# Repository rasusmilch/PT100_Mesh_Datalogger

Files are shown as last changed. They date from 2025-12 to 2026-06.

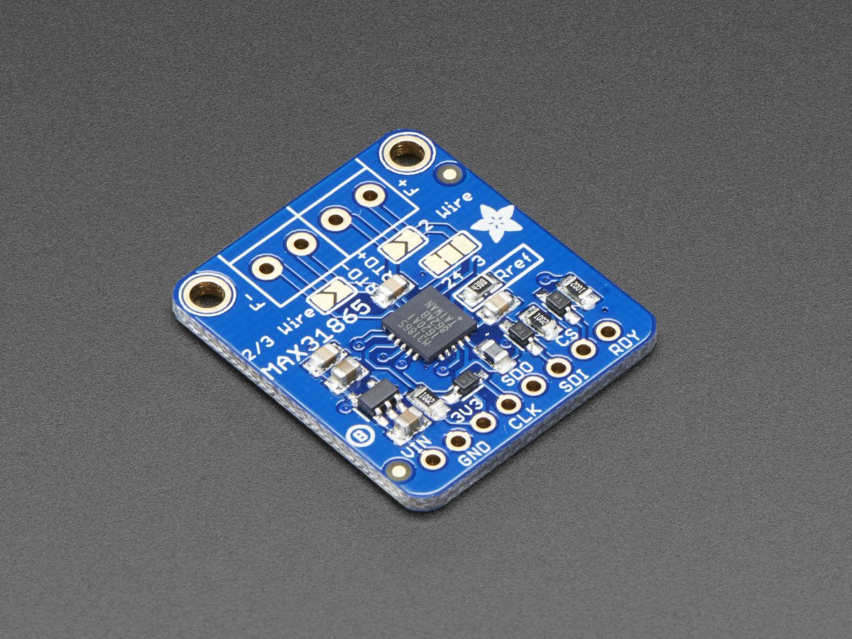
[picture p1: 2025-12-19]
documents/Adafruit_MAX31865-master/Adafruit_MAX31865-master/assets/image.jpg

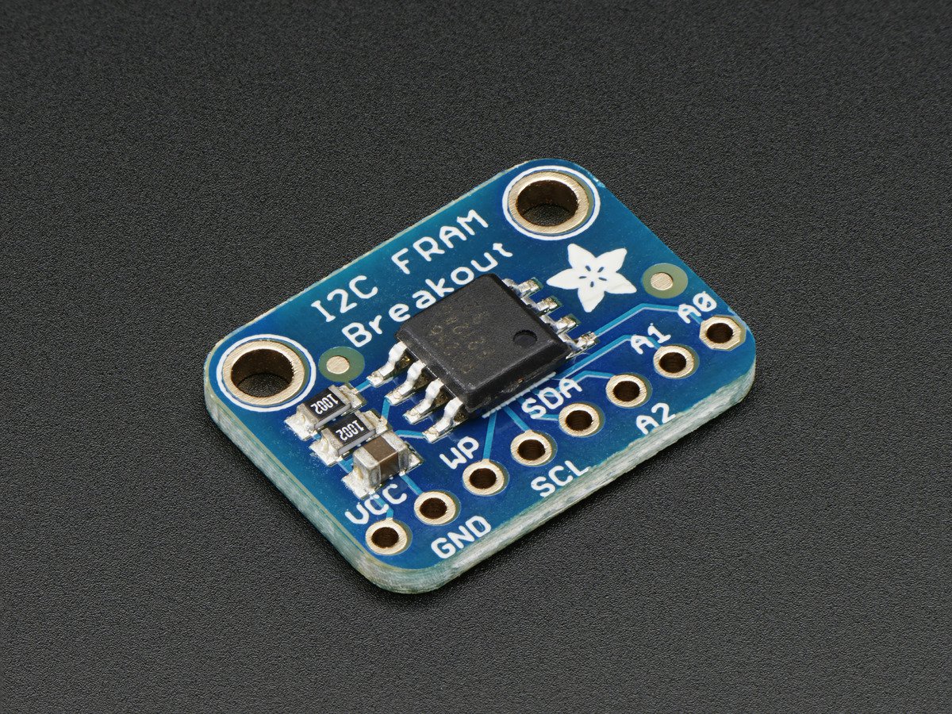
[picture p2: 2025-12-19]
documents/Adafruit_FRAM_I2C-master/Adafruit_FRAM_I2C-master/assets/image.jpg

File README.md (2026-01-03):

# PT100 + MAX31865 Temperature Data Logger (ESP32-S3, ESP-IDF)

This application turns an ESP32-S3 N8R2 into a UTC-centric PT100 data logger with FRAM-first buffering, SD-card CSV batching/verification, DS3231 RTC support, mesh streaming, and serial-console calibration.

## Hardware / wiring

All signal pins are configurable under `idf.py menuconfig -> PT100 Logger`:

- Shared SPI bus: `MOSI`, `MISO`, `SCLK`
- Chip-selects: `MAX31865 CS`, `FRAM CS`, `SD CS`
- DS3231 I2C: `SDA`, `SCL` (address selectable)

Configure mesh root/leaf role and Wi-Fi credentials in the same menu.

## Build / flash

```bash
idf.py set-target esp32s3
idf.py menuconfig   # configure pins, mesh role, batch sizes, flush thresholds
idf.py build flash monitor
```

## Logging pipeline (FRAM → SD with verification)

- Sensor task samples MAX31865 at `log interval` (NVS-backed).
- Each record is appended as a fixed-size binary struct (with CRC) to a FRAM ring buffer; the persistent header tracks read/write indices and the next sequence number.
- The SD task builds large CSV batches (~64–256 KB, configurable) from FRAM without consuming it, then:
  1. Appends the batch to the daily CSV file (`YYYY-MM-DD.csv`) with `setvbuf` buffering.
  2. `fflush()` + `fsync()`.
  3. Reads back the appended region and checks SHA-256.
  4. On mismatch: truncates to the original size and leaves FRAM untouched.
  5. On success: consumes the matching FRAM records.
- CSV header (written once per day):  
  `schema_ver,record_id,seq,epoch_utc,iso8601_local,raw_rtd_ohms,raw_temp_c,cal_temp_c,flags,node_id`
- FRAM is limited (default 32 KB); when it fills, logging pauses (no overwrite) until a flush frees space. A `fram_full` flag surfaces via `status`.

### Resume / crash safety

- On boot or day rollover the logger:
  1. Opens today’s file, truncates to the last newline if the tail was partial.
  2. Scans the tail to find the last written `seq`.
  3. Drops any FRAM records with `seq <= last_sd_seq` to guarantee no duplicates.
- If FRAM corruption is detected, consumption stops and the corrupted record can be skipped explicitly (see logs).

### Timekeeping

- DS3231 is treated as UTC and seeds system time at boot.
- Mesh root uses SNTP, updates DS3231, and broadcasts time over the mesh; leaves can request/broadcast time updates.

## Serial console commands

- `status`
- `raw` (one sample: raw/calibrated temp + resistance)
- `log interval <ms>`
- `log watermark <records>` (FRAM flush high-water mark)
- `log flush_period <ms>` (periodic SD flush interval)
- `log batch <bytes>` (target SD batch size)
- `log show`
- `cal clear`
- `cal add <raw_c> <actual_c>`
- `cal list`
- `cal apply` (1 point = offset-only; 2–4 points fit deg1–deg3)
- `flush` (best-effort FRAM→SD flush with verification)
- `diag check` (diagnostics mode only; sensor/FRAM/SD/mesh/time quick health check)

All configuration changes persist to NVS.

## Mesh / host streaming

### Mesh mode (leaf → root → broker/serial)

- Leaf nodes publish samples into the mesh; logging to FRAM continues if the
  mesh or upstream network is down.
- The root bridges mesh records to the MQTT broker and/or the DATA UART (CSV),
  and these exports are best-effort only.

### Direct Wi-Fi leaf mode (leaf → broker)

- Leaves can bypass the mesh and publish directly to the broker when configured
  for direct Wi-Fi.

FRAM/SD logging plus the DATA UART output never depend on network availability.

- Leaf nodes send samples upstream; logging to FRAM continues if mesh is down.
- Root node prints one CSV row per record over UART (after the CSV header).

Root upstream router credentials can be provided via the `wifi_ssid` /
`wifi_pass` NVS settings (from your console tooling or provisioning flow). If
those are not set, the root falls back to
`CONFIG_APP_WIFI_ROUTER_SSID` / `CONFIG_APP_WIFI_ROUTER_PASSWORD` in Kconfig.

## Test plan

1. **Calibration persistence**: Add points, apply, reboot, and confirm `status` shows the same coefficients and calibrated readings remain adjusted.
2. **Batching size**: Monitor SD writes (logic analyzer or debug prints) to confirm large buffered writes (64–256 KB) rather than per-sample writes.
3. **Crash during flush**: Pull power mid-flush; on reboot confirm the CSV tail is repaired and no duplicated `seq` appears on SD after FRAM drains.
4. **Tail repair**: Manually append a partial line to a CSV, reboot, and confirm it is truncated to the last newline automatically.
5. **Mesh resilience**: Run leaves with the root powered off; verify local FRAM accumulation and later FRAM→SD flush when root/SD returns.
6. **SD removal**: Unmount/remove SD, ensure FRAM continues to grow; remount and verify backlogged records flush with verified appends.

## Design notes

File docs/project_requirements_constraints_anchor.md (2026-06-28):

# Project Requirements and Constraints Anchor

Suggested path: `docs/project_requirements_constraints_anchor.md`

## Product requirements

The PT100 mesh datalogger shall prioritize unattended data preservation, clear diagnostics, and safe recovery over convenience or broad automatic cleanup.

Core product requirements:

1. The firmware shall collect PT100 temperature samples and preserve them through SD-card interruptions where possible.
2. The root logging node shall write durable PTLOG files to SD storage.
3. The system shall use FRAM as a buffer when SD logging is unavailable, delayed, degraded, or recovering.
4. New PTLOG files shall use the nested monthly FAT 8.3 layout:

   * `/sdcard/logs/YYYY-MM/YYYYMMDD.RRR`

   `RRR` is a decimal same-day revision from `000` through `999`; the extension is revision metadata, not file-type metadata.
5. The firmware shall ignore old root-level and long-name `.ptlog` files for PTLOG scanning, stats, and reclaim.
6. SD reclaim shall delete only old eligible compact nested PTLOG files from approved locations.
7. SD reclaim shall preserve current-date PTLOG files unless a later explicit emergency policy approves otherwise.
8. SD diagnostics shall preserve enough detail to distinguish mount, card, byte-space, create/open, directory-entry, and I/O failure classes where practical.
9. FRAM diagnostics shall distinguish current live pressure from historical data-loss evidence.
10. Host tools shall continue to read and process compact PTLOG data required for plotting, reporting, and validation; CSV import may remain as a generic feature.
11. Host tools shall tolerate partial/corrupt PTLOG tails, process all valid compact nested revisions independently, deduplicate valid records by `record_id`, and report skipped/corrupt records with file/offset or line details when available.

## Workflow requirements

Developer workflow requirements:

1. Before any Codex planning, execution, review, validation, or next-action task, inspect the latest available source directly.
2. Prefer the latest user-provided local snapshot if available. If not available, inspect the current GitHub repository, PR, branch, or commit.
3. State exactly what source, branch, PR, commit, files, anchors, and receipts were inspected.
4. Treat Codex receipts, old plans, comments, tests, and code names as claims to verify, not authority.
5. Keep tasks narrow and staged.
6. Do not combine unrelated roadmap work into a single execute task.
7. For embedded firmware changes, require build validation with ESP-IDF before merge when available.
8. For storage/recovery behavior, distinguish host-test coverage from real hardware validation.
9. Do not claim hardware validation unless real target hardware/media was used and the scenario is described.
10. Preserve explicit exclusions in every task receipt.

Operator workflow requirements:

1. Operators shall have a clear way to inspect SD and FRAM status.
2. Destructive SD format shall remain an explicit operator action.
3. Runtime alerts shall distinguish active/current failures from stale historical conditions where practical. Repeated stale `fram_overrun - active` ntfy after SD recovery and FRAM drain is a known deferred defect, not expected product behavior.
4. Display/status codes shall not be treated as precise unless their semantics are explicit.
5. Recovery behavior should avoid requiring card format unless reclaim/retry policies cannot recover.

## Data and state requirements

PTLOG data requirements:

1. PTLOG files shall remain append-safe and recoverable after interrupted writes where practical.
2. New daily PTLOG file names shall include the UTC date as `YYYYMMDD` in `/logs/YYYY-MM/YYYYMMDD.RRR`.
3. New revision PTLOG files shall use decimal `.RRR` revision metadata from `000` through `999`; old long names with `-<revision>.ptlog` are ignored by firmware.
4. New daily PTLOG files shall be grouped under `/logs/YYYY-MM/`.
5. Root-level and old long-name PTLOG-looking files shall not be eligible for firmware scanning, stats, or reclaim.
6. Automatic retention shall use parsed PTLOG metadata, not directory enumeration order alone.
7. Automatic retention shall fail closed when names, paths, stat results, or directory traversal are ambiguous.
8. On boot, SD remount, recovery, restart, header/signature uncertainty, or prior-file uncertainty, firmware should create a new same-day revision file rather than repairing and appending to an uncertain old tail.
9. Old/corrupt/partial revision files shall be preserved for host-side recovery, and firmware must not consume/discard FRAM records until append/verify to the active revision succeeds.

FRAM state requirements:

1. FRAM total overrun count shall be treated as durable historical data-loss evidence.
2. FRAM active pressure shall represent current live pressure or active overwriting, not merely an old unacknowledged total.
3. Historical/unacknowledged FRAM overrun and current/live FRAM pressure shall be modeled separately.
4. FRAM contents shall not be cleared by SD format unless a later explicit policy approves that behavior.
5. After SD recovery, FRAM drain behavior shall preserve record ordering and record IDs.
6. Repeated `fram_overrun - active` ntfy after SD recovery and FRAM drain appears caused by historical cumulative overrun being treated as active/current pressure; later FRAM semantic work shall fix it, and unrelated SD storage tasks shall not modify ntfy/display/FRAM behavior unless explicitly scoped.

SD state requirements:

1. SD mounted/unmounted state, card-present state, create/open failure, I/O failure, byte-space pressure, directory-entry pressure, and degraded/backoff state are distinct.
2. Current daily PTLOG date shall be protected from reclaim.
3. Current open PTLOG path protection is desirable but not currently tracked; current-date protection is the current conservative guard.
4. Reclaim deletion count shall count only successful `unlink()` calls.
5. Reclaim shall recompute storage condition after each successful delete.

## Architecture and model constraints

General architecture constraints:

1. Keep storage/path behavior centralized in storage/path helper code where practical.
2. Avoid duplicating PTLOG name parsing in multiple modules.
3. Prefer bounded, fixed-buffer embedded logic, but do not treat fixed-size buffers as approval to place large storage path, file, candidate, scan-observation, or I/O buffers on a FreeRTOS task stack.
4. SD/PTLOG path, filename, month-directory, candidate-path, and related path-workflow buffers currently local to stack-heavy workflows should be moved to centrally owned static storage where practical. Prefer PSRAM-backed allocation/storage on the target when safe and available.
5. Largish reusable buffers should be centrally owned/static rather than repeatedly placed on task stacks. Do not increase FreeRTOS task stack sizes merely to compensate for storage/path stack pressure.
6. The abandoned generic storage scratch-owner direction from PR #376 is not the intended architecture and must not be merged as-is; it is preserved only on `archive/scratch-owner-pr376-0819853` for reference.
7. The next implementation must remain narrow: path/candidate buffer placement only, using a dedicated typed SD/PTLOG path workspace if useful. It must not create a generic allocator, slot pool, borrow/release API, or concurrency framework.
8. Future storage/path code must document ownership, lifetime, capacity, fail-closed behavior, diagnostics, and explicit runtime serialization or locking assumptions for shared/static workspace use.
9. Separate mechanism from policy:

   * candidate discovery is mechanism;
   * retention thresholds are policy;
   * create/open retry rules are policy;
   * current-date deletion is policy;
   * display/ntfy wording is product behavior.
10. Prefer one-candidate-per-pass reclaim over large in-memory candidate arrays.
11. Do not use unbounded recursive directory traversal on embedded firmware.
12. Do not follow arbitrary host-created directories.
13. Do not preserve obsolete root-only assumptions after the nested PTLOG layout.
14. Do not refactor broadly while fixing a specific reliability issue.
15. Do not change public/operator-visible behavior unless it is in scope.

PTLOG path constraints:

1. Approved automatic scan locations are:

   * `/sdcard`
   * `/sdcard/logs`
   * `/sdcard/logs/YYYY-MM`
2. Approved automatic delete candidates are regular files with parsed PTLOG names in approved locations.
3. Unknown subdirectories under `/logs` shall not be traversed unless they match `YYYY-MM`.
4. System directories such as `.Trash-1000`, `FOUND.000`, and `System Volume Information` shall be ignored by automatic retention.
5. Path joins shall check truncation and fail closed.
6. Scan/reclaim code shall remain bounded and non-recursive when storage path-workflow buffers are moved out of task stack.

## Security and permission constraints

1. Automatic firmware deletion shall be restricted to validated PTLOG candidates.
2. The firmware shall not automatically delete arbitrary user files, host-created system directories, or unknown directories.
3. Destructive operations such as SD format shall require explicit operator command/action.
4. Diagnostics may include path and errno information, but should avoid leaking unrelated sensitive data.
5. Network notification changes, if any, shall be scoped and reviewed separately.
6. Tasks shall not introduce new unauthenticated control paths or remote destructive operations without explicit approval.
7. Host tools shall not silently overwrite source data unless explicitly designed and documented.

## Validation and testing requirements

General validation requirements:

1. Every execute task shall list exact commands run and exact results.
2. Tests must be behavior-based where practical, not only compile/import smoke tests.
3. Host tests are acceptable for path parsing, candidate selection, and small deterministic helpers.
4. ESP-IDF build is required for embedded firmware changes before merge when `idf.py` is available.
5. If `idf.py` is unavailable, the exact error shall be reported and firmware build shall remain unverified.
6. Hardware validation is required before claiming real SD/FAT behavior is proven.
7. `git diff --check` shall be run for code changes.
8. Final receipts shall identify unverified and environment-limited items.

Storage-specific validation requirements:

1. PTLOG path construction tests shall cover base daily files and revision files.
2. PTLOG parsing tests shall reject malformed names and overflow revisions.
3. Candidate traversal tests shall cover root and nested candidates.
4. Candidate traversal tests shall verify current-date and current-path protection where applicable.
5. Reclaim tests shall verify:

   * nested candidate selection;
      * current-date protection;
   * same-date revision protection;
   * non-PTLOG preservation;
   * PTLOG-looking directory preservation;
   * system directory exclusion;
   * malformed month directory exclusion;
   * max delete limit behavior;
   * successful delete counting;
   * unlink-failure no-count behavior.
6. Hardware SD validation should include real FAT16 media, nested log directories, old ignored root files, low-space or forced reclaim conditions, and current-date file protection.

## Documentation requirements

1. Project anchors shall be concise and reusable.
2. Do not paste raw receipts into anchors.
3. Anchors shall summarize current intent, requirements, constraints, decisions, risks, and validation gaps.
4. Markdown anchor files should include a “Last updated context” section.
5. Code comments shall explain non-obvious behavior, invariants, safety constraints, or failure models.
6. Avoid placeholder comments that restate function names or parameter names without adding meaning.
7. Operator documentation shall be updated when commands, public workflows, display/status behavior, setup, or expected operator action changes.
8. PR bodies shall accurately distinguish direct production-function tests from test-local approximations.
9. If a code documentation policy anchor exists, future source changes shall read and follow it.
10. If no code documentation policy anchor exists, embedded tasks shall include focused documentation requirements.

## Deployment and environment constraints

1. Target firmware environment is ESP-IDF on ESP32-class hardware.
2. SD storage currently uses FAT-compatible ESP-IDF VFS behavior.
3. FAT16 with 16 KiB allocation units is an accepted current configuration.
4. `.allocation_unit_size = 16 * 1024` shall not be changed without explicit approval.
5. `.max_files = 5` shall not be changed without explicit approval and validation.
6. Real SD/FAT behavior may differ from Linux host filesystem behavior.
7. Host tests may use Linux temporary directories to simulate paths, but such tests do not prove FAT directory-entry behavior.
8. Some Codex/local environments may lack configured git remotes.
9. Some Codex/local environments may lack `idf.py`.
10. Codex may check out work into a local branch named `work`; this name shall not be treated as the product branch name.

## Code style and maintainability requirements

1. Prefer small, readable C helpers over large mixed-responsibility functions.
2. Use fixed-size buffers and explicit bounds checks in embedded path/storage code.
3. Preserve existing public interfaces unless a task explicitly changes them.
4. Remove dead static helpers when replacing obsolete behavior.
5. Avoid broad reformatting or unrelated cleanup.
6. Log useful failure detail without creating noisy repeated logs.
7. Keep task-specific comments focused on safety and model decisions.
8. Avoid duplicating parsing/validation rules in multiple places.
9. Prefer deterministic candidate ordering.
10. Keep host-test helpers small and purpose-specific.
11. Do not create a large fake ESP-IDF harness unless a task explicitly approves it.
12. Any execute task touching storage/path code shall report new stack buffers by file/function/size, new static buffers by owner/lifetime/size, new heap or PSRAM allocations with fallback behavior, and task-safety/locking assumptions for shared static path workspaces.
13. Future storage tasks shall not silently add or preserve large stack buffers; if a small stack path-fragment buffer is necessary, the task receipt shall justify it and distinguish it from reusable static SD/PTLOG path-workflow buffers.

## Prompting and Codex receipt formatting requirements

Codex planning tasks shall require:

1. Latest source inspection before planning.
2. No file changes.
3. Verified current behavior by file/function.
4. Comparison of current behavior to intended behavior.
5. Explicit behavior gap.
6. Architecture/model/pattern/rule checkpoint.
7. Minimal safe implementation path.
8. Split-vs-single-task recommendation.
9. Proposed tests.
10. Documentation requirements.
11. Risks, unverified items, product decisions, and exclusions.
12. Complete planning receipt inside one copy/paste-ready `~~~text` fence.

Codex execute tasks shall require:

1. Latest source inspection before editing.
2. Implementation of only approved behavior.
3. Preservation of prior validated behavior.
4. Avoidance of future roadmap work.
5. Behavior tests for intended workflow and real failure scenarios.
6. Documentation compliance.
7. Exact command results.
8. Final receipt inside one copy/paste-ready `~~~text` fence.
9. No nested fences in receipts.

Codex receipts shall include at minimum:

1. Inspected context.
2. Source state and branch/commit identity.
3. Anchor files and docs inspected.
4. Summary of changes or planning decision.
5. Files changed, if any.
6. Verified behavior.
7. Tests and commands.
8. Acceptance criteria.
9. Documentation compliance.
10. Explicitly preserved exclusions.
11. Risks and unverified items.
12. Environment-limited items.
13. Next recommended action.

## Scope-control rules

1. Do not let Codex decide product policy.
2. Mark undecided behavior as a product decision.
3. Do not broaden a task because related issues are visible.
4. Do not start the next roadmap task until the current PR has at least build validation.
5. Do not claim validation that was not performed.
6. If a task touches embedded storage, preserve safety exclusions unless explicitly changed.
7. If a task reveals a wrong model, stop and replan instead of patching around it.
8. Do not combine SD path/reclaim changes with FRAM semantic changes.
9. Do not combine display/status/ntfy wording changes with storage mechanism changes unless explicitly scoped.
10. Do not create anchors during unrelated implementation tasks unless explicitly requested.

## Known project-specific hazards

1. FAT16 root-directory entry exhaustion from many long PTLOG filenames.
2. Long FAT filenames consuming multiple directory entries.
3. Free byte space appearing sufficient while directory-entry allocation fails.
4. Linux reading a card successfully while ESP-IDF FATFS fails create/open.
5. Root-only reclaim failing after logs move to nested monthly directories.
6. Automatic deletion accidentally targeting non-PTLOG files if parsing/traversal is too broad.
7. Current-date PTLOG deletion causing active logging data loss.
8. Historical FRAM overrun being displayed or alerted as active/live pressure.
9. Misleading `SDOUT` interpretation.
10. Post-append mutation of a record flag not affecting the already-stored FRAM record.
11. Environment receipts that report local branch `work` without remote metadata.
12. PR or receipt claims overstating test coverage.

## Settled requirements

These are currently settled unless the user explicitly changes them:

1. New daily PTLOG files use nested monthly directories with `YYYYMMDD.RRR` FAT 8.3 basenames.
2. Legacy/root long-name PTLOG compatibility is intentionally removed; old files are ignored, not migrated.
3. Automatic PTLOG traversal is bounded to approved locations.
4. Automatic reclaim deletes only parsed regular PTLOG candidates.
5. Current-date PTLOG files are protected.
6. Reclaim deletes one oldest eligible candidate per pass.
7. Reclaim currently remains byte-space-triggered only until threshold policy is added.
8. FAT16 / 16 KiB allocation unit configuration remains accepted.
9. Hardware validation is required before claiming SD/FAT runtime behavior is proven.
10. FRAM historical overrun and live pressure must be separated in future FRAM work.
11. Display/ntfy status changes are separate tasks.
12. Project tasks should minimize Codex usage through focused planning and execution.

## Provisional requirements and product decisions still needed

These require user decision or explicit task approval:

1. Exact max total PTLOG file count.
2. Exact max PTLOG files per directory.
3. Exact compact nested PTLOG count threshold.
4. Exact estimated FAT directory-entry pressure threshold.
5. Whether reclaim should run before daily open based on file-count/directory-entry pressure.
6. Which daily `fopen`/create errors trigger reclaim and retry.
7. Whether create/open reclaim retry deletes one file or multiple files.
8. Whether current-date PTLOGs may ever be deleted in an emergency.
9. Whether same-day old revision PTLOGs may be deleted automatically.
10. Whether empty month directories should be removed after reclaim.
11. Whether to track current open PTLOG path in `sd_logger_t`.
12. Compact PTLOG names are mandatory for firmware PTLOG files as `YYYYMMDD.RRR`; legacy `.ptlog` compatibility is removed.
13. Replacement display/status code taxonomy for `SDOUT`.
14. FRAM acknowledgement policy for historical data loss.
15. Whether `LOG_RECORD_FLAG_FRAM_FULL` should be fixed before append or removed.
16. Whether formal decision log and validation ledger anchors should be required for future tasks.

## References and related anchors

Known current reference:

* `docs/sd_fram_failure_2026_06_23_analysis.md`

Recommended related anchors:

* `docs/project_intent_anchor.md`
* `docs/project_roadmap_anchor.md`
* `docs/code_documentation_policy_anchor.md`
* `docs/decision_log_anchor.md`
* `docs/validation_ledger_anchor.md`

At this update, the requirements/constraints anchor itself was not present in current `main`.

## Last updated context

This anchor was drafted from:

* Current conversation through merged PR #369.
* Merged PR #368: `Move PTLOG writes to FAT16-safe log directories`.
* Merged PR #369: `Refactor SD reclaim to use SdPtlogFindOldestCandidate and add reclaim unit tests`.
* Current `main/sd_logger.c` reclaim implementation after PR #369.
* Current `main/sd_ptlog_paths.c` bounded PTLOG path and candidate scanner implementation.
* `docs/sd_fram_failure_2026_06_23_analysis.md`.
* Codex Task 2A planning and execution receipts.
* ChatGPT senior review of Task 2A execution.
* User direction to conserve Codex usage through narrow, staged tasks.

Unverified at this update:

* Real hardware SD/FAT16 validation after PR #368 and PR #369.
* Long-duration field behavior after nested monthly PTLOG writes and reclaim changes.
* Host tool support for nested `/logs/YYYY-MM/` discovery across all workflows.
* Whether display/ntfy state names have been corrected.
* Whether FRAM active-vs-historical overrun semantics have been fixed.
* Whether formal roadmap, code documentation policy, decision log, or validation ledger anchors exist in the repository after this draft.

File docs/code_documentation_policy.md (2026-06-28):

# Code Documentation Policy

Suggested path: `docs/code_documentation_policy.md`

## Purpose and scope

This policy defines how source code documentation shall be written and reviewed in this repository.

It applies to:

* Embedded C firmware.
* Public and internal C headers.
* Python host tools.
* Tests and test helpers.
* Build/tooling scripts when they contain project behavior.
* Future C++ code if added.
* Codex-generated code and review tasks.

The goal is not to add large comments everywhere. The goal is to preserve product intent, safety constraints, hardware assumptions, validation boundaries, and non-obvious behavior so future maintainers and Codex sessions do not accidentally preserve stale patterns or introduce unsafe behavior.

## Audience

Code documentation should help:

* Future maintainers.
* Junior developers.
* Codex sessions.
* Human reviewers.
* Operators investigating failures.
* Hardware/debug support.
* Test authors.
* Anyone validating SD, FRAM, mesh, display, notification, calibration, or host-tool behavior.

Documentation should assume the reader can read code, but may not know the project history, hardware constraints, SD/FAT failure modes, FRAM semantics, or prior product decisions.

## Repository languages detected

The repository currently contains:

* Embedded C firmware under `main/`.
* C headers under `main/`.
* Python host tools under `host_tools/`.
* C host tests under `host_tools/tests_c/`.

C++ source was checked but not found as an active implementation language in the inspected context. C headers use `extern "C"` guards, so public headers should remain compatible with future C++ consumers.

Markdown documentation exists under `docs/`.

## General documentation standard

Document behavior when the reader needs information that is not obvious from the code.

Good documentation explains:

* Why this behavior exists.
* What invariant must remain true.
* Which product decision it encodes.
* Which safety or reliability issue it prevents.
* Which hardware or filesystem assumption it depends on.
* Which states are intentionally distinct.
* Which failures are expected and how they are handled.
* Which behavior is provisional or intentionally deferred.

Avoid comments that merely translate syntax into English.

Documentation must not claim validation that was not performed.

## Python standard

Python modules, classes, and functions shall follow PEP 257-compatible docstrings.

Use concise one-line docstrings for simple private helpers where the behavior is obvious but the helper name benefits from clarification.

Use a full docstring block when a function or class has:

* Nontrivial parsing or validation.
* File I/O.
* Report/export behavior.
* User-facing behavior.
* Error handling.
* Side effects.
* Data conversion.
* Time zone logic.
* Calibration or units.
* Compatibility with firmware schemas.
* Regression coverage for a previous bug.

Prefer Google-style sections when they add clarity:

* `Args:`
* `Returns:`
* `Raises:`
* `Side Effects:`
* `Notes:`

Python docstring example:

```python
def parse_ptlog_timestamp(value: str, default_tz: ZoneInfo) -> datetime.datetime:
    """Parse a PTLOG timestamp and attach the expected source timezone.

    Args:
        value: Timestamp text from a PTLOG or CSV export.
        default_tz: Timezone to apply when the source timestamp is naive.

    Returns:
        A timezone-aware datetime suitable for sorting and report ranges.

    Raises:
        ValueError: If the timestamp cannot be parsed.

    Notes:
        PTLOG source timestamps may be naive in older exports. Do not silently
        treat them as local workstation time; that changes report ordering and
        trim behavior.
    """
```

Short private-helper example:

```python
def _is_blank_row(row: dict[str, str]) -> bool:
    """Return true when every parsed CSV field is empty."""
```

Do not add large docstrings to trivial wrappers where the name and type hints already explain the behavior.

## C standard

Use Doxygen-compatible comments for:

* Public header functions.
* Public structs, enums, and typedefs.
* Callback types.
* Macros that behave like APIs or encode product limits.
* Nontrivial static functions when they encode safety, policy, hardware, timing, or failure behavior.
* Test helpers that model production behavior.

Preferred tags:

* `@brief`
* `@param`
* `@return`
* `@retval`
* `@note`
* `@warning`
* `@pre`
* `@post`

Document the following when relevant:

* Ownership and lifetime.
* Buffer sizes.
* Units.
* Error codes and return meanings.
* Blocking behavior.
* ISR safety.
* Thread/task safety.
* Locking assumptions.
* Allocation behavior.
* Stack usage when a helper uses more than small scalar or path-fragment locals.
* Buffer ownership, lifetime, and required capacity for static SD/PTLOG path-workspace buffers.
* Whether an SD/PTLOG path-workspace buffer is stack, static, heap, PSRAM, or caller-owned.
* Task/lock assumptions for shared static SD/PTLOG path-workspace buffers, including whether the function may run while holding the SD I/O lock.
* Truncation and fail-closed behavior for path construction.
* Allocation failure behavior and fallback allocation caps.
* Whether a function may log.
* Whether a function may mutate persistent state.
* Whether a function may delete files or otherwise perform destructive operations.

Storage-specific documentation requirements:

* Do not add comments that normalize large task-stack buffers in storage code.
* Public structs, public helpers, and nontrivial static helpers that use or receive SD/PTLOG path-workspace buffers must document buffer ownership, lifetime, required capacity, placement (stack/static/heap/PSRAM/caller-owned), task/lock assumptions, SD I/O lock expectations, truncation/fail-closed behavior, and allocation failure behavior.
* If a function intentionally uses a stack buffer larger than a small scalar/path-fragment buffer, the source comment must justify why that stack use is safe and the task receipt must report the file, function, and size.
* Documentation must not claim target stack high-water, heap, PSRAM, FAT, or hardware validation unless that validation was actually performed and described.

C header example:

```c
/**
 * @brief Find the oldest PTLOG file that automatic retention may delete.
 *
 * @param mount_point Mounted SD root path, such as "/sdcard".
 * @param current_path Optional exact path of the currently open PTLOG file.
 * @param current_date Optional current UTC date string in "YYYY-MM-DDZ" form.
 * @param candidate_out Receives the selected candidate when true is returned.
 *
 * @return true when an eligible regular PTLOG file was found.
 * @return false when no eligible file was found or required arguments are invalid.
 *
 * @note Traversal is intentionally bounded to root, /logs, and /logs/YYYY-MM.
 * @warning The caller may delete the returned path. This function must fail
 * closed for malformed names, path truncation, special files, and system dirs.
 */
bool SdPtlogFindOldestCandidate(const char* mount_point,
                                const char* current_path,
                                const char* current_date,
                                sd_ptlog_candidate_t* candidate_out);
```

C struct example:

```c
/**
 * @brief Parsed PTLOG candidate returned by bounded SD retention scanning.
 *
 * All string fields are null-terminated. Paths are absolute within the mounted
 * filesystem. A candidate is safe to consider for retention only after the
 * scanner has verified it is a regular file with a parsed PTLOG basename.
 */
typedef struct
{
  char path[SD_PTLOG_MAX_PATH_LEN]; /**< Full path to the candidate file. */
  char name[SD_PTLOG_MAX_NAME_LEN]; /**< Basename as found in the directory. */
  char date[SD_PTLOG_DATE_LEN + 1u]; /**< Parsed UTC date: YYYY-MM-DDZ. */
  uint32_t revision;                /**< Parsed same-day revision, or 0. */
  bool legacy_root;                 /**< True when candidate came from root. */
  bool current_open;                /**< True only if exact current path matched. */
} sd_ptlog_candidate_t;
```

C static helper example:

```c
/**
 * @brief Join a directory and child name without allowing truncation.
 *
 * @return true when the full path fit in the destination buffer.
 * @return false when any argument is invalid or the joined path would truncate.
 *
 * @note Storage code must fail closed on truncated paths because later callers
 * may open, create, or delete the returned path.
 */
static bool JoinPath(const char* dir_path,
                     const char* child_name,
                     char* out_path,
                     size_t out_path_size);
```

## C++ standard

No active C++ implementation files were found in the inspected context. If C++ is added later, use Doxygen-compatible comments for:

* Public classes.
* Public methods and functions.
* Templates.
* Interfaces.
* Enums.
* RAII ownership types.
* Hardware abstraction wrappers.
* Error/status types.

Document:

* Class invariants.
* Ownership and lifetime.
* Move/copy behavior.
* Exception or error-return behavior.
* Thread safety.
* Side effects.
* Blocking behavior.
* Hardware/resource ownership.

C++ example:

```cpp
/**
 * @brief Owns an SD log file and closes it on destruction.
 *
 * The object is movable but not copyable because it owns a file handle.
 *
 * @note Methods are not thread-safe unless the caller holds the runtime lock.
 * @warning Destruction may flush buffered data and can block on filesystem I/O.
 */
class SdLogFile {
 public:
  SdLogFile(SdLogFile&& other) noexcept;
  SdLogFile& operator=(SdLogFile&& other) noexcept;

  SdLogFile(const SdLogFile&) = delete;
  SdLogFile& operator=(const SdLogFile&) = delete;
};
```

## Embedded C/C++ standard

Embedded documentation must capture hardware and runtime assumptions that are not obvious from generic C code.

Document these when relevant:

* Hardware revision assumptions.
* Pin maps and peripheral maps.
* SPI/I2C/UART bus ownership.
* Clock and timer assumptions.
* Interrupt behavior and ISR/main interactions.
* DMA ownership and alignment requirements.
* RTOS task names, priorities, queues, event groups, and synchronization.
* Stack, heap, static allocation, and PSRAM assumptions.
* Calibration constants, units, scaling, and fixed-point math.
* Power/reset/watchdog behavior.
* Datasheet, errata, and register-sequence assumptions.
* Required delays and timing constraints.
* Safety-critical retry limits.
* Persistent storage layout.
* Filesystem format assumptions.
* Failure states and recovery boundaries.

Embedded example:

```c
/**
 * @brief Attempt bounded SD reclaim before another append attempt.
 *
 * @pre Caller holds the SD logger lock.
 * @pre logger->mount_point is a mounted FAT filesystem path.
 *
 * @param logger Active SD logger instance.
 * @param required_free_bytes Minimum byte-space target before append.
 * @param deleted_files Optional output count of successfully unlinked PTLOGs.
 *
 * @retval ESP_OK Reclaim completed or no eligible PTLOG candidate existed.
 * @retval ESP_ERR_INVALID_ARG logger was NULL.
 * @retval ESP_FAIL Free-space query failed.
 *
 * @note Reclaim is currently byte-space-triggered only. Directory-entry and
 * file-count pressure are handled by later retention policy work.
 * @warning Automatic reclaim must only delete parsed regular PTLOG candidates
 * from approved locations and must protect the current date.
 */
static esp_err_t SdLoggerReclaimSpaceLocked(sd_logger_t* logger,
                                            uint64_t required_free_bytes,
                                            uint32_t* deleted_files);
```

## Inline comment expectations

Inline comments should explain “why,” not trivial “what.”

Use inline comments for:

* Non-obvious domain assumptions.
* Safety constraints.
* Security/permission boundaries.
* Hardware timing assumptions.
* Peripheral register sequences.
* Interrupt, task, or lock interactions.
* Ownership and lifetime rules.
* Strict rejection cases.
* Regression protections for previous quality escapes.
* Why a broader-looking case is intentionally not handled.
* Why a policy is deferred.

Good inline comment example:

```c
/* Current-date protection is intentionally broad because sd_logger_t does not
 * yet track the exact open PTLOG path.  Do not narrow this until current-path
 * lifetime is modeled and tested. */
```

Bad inline comment example:

```c
/* Increment i. */
i++;
```

## What not to comment

Do not add:

* Comments that narrate syntax.
* Speculative comments.
* Stale comments.
* Comments that contradict tests or source behavior.
* Comments that claim hardware validation without hardware results.
* Large copied receipts in source comments.
* TODOs without owner, condition, or follow-up context.
* Comments that preserve deprecated assumptions.
* Comments that repeat function or parameter names without explaining behavior.

Do not remove useful product, hardware, safety, or failure-model comments unless replacing them with more accurate documentation.

## Codex task requirements

Every Codex task that adds or modifies source code must read this policy before editing.

Codex prompts must restate documentation requirements in acceptance criteria. Do not only say “follow the policy.”

Minimum Codex source-task acceptance language:

```text
Code documentation acceptance criteria:
- Read `docs/code_documentation_policy.md` before editing source.
- Add or update Doxygen-compatible comments for new or changed public C headers,
  structs, enums, callbacks, macros that behave like APIs, and nontrivial
  functions whose behavior is not obvious.
- Add or update PEP 257-compatible Python docstrings for new or changed
  modules, classes, public functions, and nontrivial private helpers.
- Add inline comments only for non-obvious product, safety, hardware, timing,
  ownership, concurrency, validation, or failure-model assumptions.
- Do not add comments that merely narrate syntax.
- Do not remove useful safety/product/hardware comments without replacing them
  with more accurate comments.
- Report documentation changes and any intentional documentation omissions in
  the final receipt.
```

Every Codex final receipt for a source task must include:

```text
Code documentation compliance:
- Policy file inspected: yes/no and path.
- Public APIs changed: yes/no.
- New/touched functions/classes/modules documented: yes/no.
- Inline safety/product comments added or updated: yes/no.
- Documentation intentionally omitted for trivial code: yes/no and why.
- Stale/misleading comments removed or corrected: yes/no.
```

## Documentation-only source-pass safety

Documentation-only passes must prove behavior did not change.

For Python documentation-only changes:

* Parse changed Python files with `ast.parse`.
* Compare AST after removing docstrings when practical.
* Run available tests.
* Run formatting/static checks if already part of the project workflow.
* Do not change imports, executable statements, defaults, type behavior, or command-line behavior during doc-only work.

Python AST equivalence guidance:

```text
For documentation-only Python changes, compare the AST with module, class, and
function docstrings stripped. If this guard is unavailable, explain the gap and
run the strongest available tests.
```

For C/C++ documentation-only changes:

* Prefer compile or build checks.
* Use preprocessing or token comparison where practical.
* Run available host tests.
* Run `git diff --check`.
* Run ESP-IDF build when firmware files changed and `idf.py` is available.
* If target hardware behavior is relevant, state that hardware was not validated unless it was.

C/C++ guard guidance:

```text
For documentation-only C/C++ changes, run the relevant compiler/build target
when available. If a token/preprocess equivalence check is available, use it.
If not, report that equivalence was guarded by compile/build/tests only.
```

Embedded verification limits:

* A successful host test does not prove target hardware behavior.
* A successful ESP-IDF build does not prove SD/FAT, timing, ISR, FRAM, or hardware behavior.
* Any hardware claim must list the target board, media/peripheral used, scenario, and observed result.

## Documentation backlog

Use this backlog for future focused tasks.

### Phase D1 — Add or verify behavior-preservation guard tooling

Goal:

* Provide repeatable checks for documentation-only changes.

Examples:

* Python docstring-stripped AST comparison helper.
* C/C++ preprocess/token comparison guidance.
* Documentation-only PR checklist.

### Phase D2 — Document core firmware entry points

Focus:

* `app_main.c`
* runtime manager entry points
* console command registration
* storage startup/shutdown
* task lifecycle

### Phase D3 — Document public APIs and headers

Focus:

* SD logger APIs
* PTLOG path helpers
* FRAM log APIs
* runtime health/status APIs
* alert manager APIs
* display/status APIs
* MAX31865 reader/calibration APIs

### Phase D4 — Document hardware abstraction and peripheral code

Focus:

* SD card detect and SD/FAT assumptions
* FRAM SPI/I2C behavior
* MAX31865 behavior
* I2C bus ownership
* Wi-Fi/mesh stack assumptions
* display hardware
* GPIO units/buttons
* watchdog/reset/power assumptions

### Phase D5 — Document complex tests and fixtures

Focus:

* Host PTLOG parsing/path tests.
* Reclaim behavior tests.
* FRAM drain/overrun tests.
* Host plotter/report tests.
* Any fake filesystem, fake clock, fake SD, or fake FRAM helpers.

### Phase D6 — Remove or correct misleading comments

Focus:

* Placeholder comments.
* Comments that preserve root-only PTLOG assumptions.
* Comments that imply `SDOUT` means only out-of-space.
* Comments that imply historical FRAM overrun is always active/current.
* Comments that overstate test or hardware validation.

## Policy for anchor files and related docs

If this policy is committed at `docs/code_documentation_policy.md`, future anchors should refer to that path.

Do not create duplicate competing policy files such as both:

* `docs/code_documentation_policy.md`
* `docs/code_documentation_policy_anchor.md`

If a legacy anchor path already exists, update the canonical policy file and add a short pointer from the older path if needed.

## Last updated context

This policy was drafted from:

* Current repository: `rasusmilch/PT100_Mesh_Datalogger`, branch `main`.
* Current ESP-IDF embedded C source list in `main/CMakeLists.txt`.
* Current Python host tool example `host_tools/pt100_plotter.py`.
* Current C public header style in `main/sd_ptlog_paths.h`.
* Recent SD/FAT16 PTLOG storage work through PR #368 and PR #369.
* Current chat drafts for project intent, requirements/constraints, decision log, and roadmap anchors.
* User preference for focused Codex tasks, explicit exclusions, and precise receipts.

Unverified at this update:

* Full repository language inventory beyond inspected/search-visible C, headers, Markdown, CMake, and Python.
* Whether C++ source exists in an uninspected path.
* Whether generated code exists and should be exempt from this policy.
* Whether a future docs/admin PR has already committed other anchor files.
* Exact target hardware revision, full pin map, and complete peripheral map.
* Project-wide static-analysis tooling beyond commands seen in prior receipts.
* Any hardware validation results beyond the user-reported successful ESP-IDF build after PR #369.

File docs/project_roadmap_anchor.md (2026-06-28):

# Project Roadmap Anchor

Suggested path: `docs/project_roadmap_anchor.md`

## Current project / workstream objective

Stabilize PT100 mesh datalogger SD/FRAM persistence so long-duration unattended logging is reliable, diagnosable, and recoverable.

The immediate workstream is the SD/FAT16 and FRAM-overrun recovery sequence triggered by the June 2026 storage incident. The working model is:

1. SD failure was most likely FAT directory-entry pressure from many long PTLOG filenames, especially at SD root.
2. FRAM later reported misleading active overrun state because historical cumulative overrun was treated like current live pressure.
3. SD storage mechanism fixes should be completed and validated before FRAM semantic fixes.
4. Each task should remain narrow to conserve Codex usage and prevent scope drift. Product intent remains unattended data preservation: avoid losing records, avoid firmware getting wedged by SD/FAT/path issues, avoid risky broad refactors, prefer bounded deterministic embedded behavior, and defer complex recovery/repair to host tools when that preserves data and reduces firmware risk.

## Current active feature / fix

Current active feature/fix: SD PTLOG storage and reclaim hardening.

Completed in this feature line:

* PR #368: Move new daily PTLOG writes into `/logs/YYYY-MM/`, add bounded path/candidate helper foundation, and add daily PTLOG diagnostics.
* PR #369: Wire bounded PTLOG candidate traversal into SD reclaim so reclaim can delete old eligible PTLOG files from compact nested monthly directories.

Current state after PR #369:

* New PTLOG writes use nested monthly directories.
* Legacy/root long-name PTLOG compatibility is removed; old files are ignored by firmware.
* Reclaim uses `SdPtlogFindOldestCandidate()`.
* Reclaim remains byte-space-triggered only.
* Current-date PTLOG files remain protected.
* No create/open reclaim retry exists yet.
* No file-count or directory-entry threshold policy exists yet.
* Hardware SD/FAT16 validation remains unverified in the available context.

## Phase 0 — Anchor and workflow stabilization

Purpose: reduce repeated context, prevent Codex scope drift, and make future task prompts smaller.

### 0A — Project intent anchor

Status: drafted in chat; repository commit unverified.

Create `docs/project_intent_anchor.md`.

Scope:

* Project purpose.
* Primary users/operators/systems.
* Core workflows.
* Desired behavior.
* Known behavior.
* Non-goals.
* Canonical terminology.
* Deprecated/misleading terminology.
* Data/state lifecycle assumptions.
* Safety/reliability expectations.
* Architecture principles.
* Risks and open decisions.

Task type:

* Focused docs execute task.

Branch/PR:

* May share one docs/admin draft PR with 0B, 0C, 0D, and 0E if no firmware source is touched.

Validation:

* Markdown review only.
* No firmware build required.

### 0B — Requirements and constraints anchor

Status: drafted in chat; repository commit unverified.

Create `docs/project_requirements_constraints_anchor.md`.

Scope:

* Product requirements.
* Workflow requirements.
* Data/state requirements.
* Architecture/model constraints.
* Security/permission constraints.
* Validation/testing requirements.
* Documentation requirements.
* Deployment/environment constraints.
* Code style and maintainability requirements.
* Prompting and receipt-format requirements.
* Scope-control rules.
* Known hazards.
* Settled vs provisional requirements.

Task type:

* Focused docs execute task.

Branch/PR:

* Can share the docs/admin anchor PR with 0A, 0C, 0D, and 0E.

Validation:

* Markdown review only.
* No firmware build required.

### 0C — Decision log anchor

Status: drafted in chat; repository commit unverified.

Create `docs/decision_log_anchor.md`.

Scope:

* Settled decisions from PR #368 and PR #369.
* Provisional decisions still needing product approval.
* Deprecated assumptions.
* Misleading implementation artifacts.
* Patterns that should not be treated as authority.

Task type:

* Focused docs execute task.

Branch/PR:

* Can share the docs/admin anchor PR with 0A, 0B, 0D, and 0E.

Validation:

* Markdown review only.
* No firmware build required.

### 0D — Roadmap anchor

Status: this document.

Create `docs/project_roadmap_anchor.md`.

Scope:

* Current workstream objective.
* Active feature/fix.
* Immediate tasks.
* Stabilization tasks.
* Pilot/validation tasks.
* Future tasks.
* Deferred/rejected paths.
* Sequencing and branch strategy.
* Planning vs execute requirements.
* High-risk checkpoints.
* Current next required action.

Task type:

* Focused docs execute task.

Branch/PR:

* Can share the docs/admin anchor PR with 0A, 0B, 0C, and 0E.

Validation:

* Markdown review only.
* No firmware build required.

### 0E — Code documentation policy anchor

Status: not drafted yet.

Create `docs/code_documentation_policy_anchor.md`.

Scope:

* Embedded C comment expectations.
* Host Python/tooling doc expectations.
* Doxygen/API comment rules.
* What comments to avoid.
* When docs must be updated.
* How to document safety-critical storage behavior.
* How to document test helper boundaries.

Task type:

* Read-only planning first if policy is not already agreed.
* Then focused docs execute task.

Branch/PR:

* Can share the docs/admin anchor PR if kept concise.

Validation:

* Markdown review only.
* No firmware build required.

## Phase 1 — Completed SD FAT16-safe layout foundation

### 1A — Bounded PTLOG path and candidate helper foundation

Status: completed in PR #368.

Outcome:

* Added PTLOG path helpers.
* Added nested monthly path construction.
* Added PTLOG filename parsing.
* Added bounded candidate traversal foundation.

Validation:

* Host PTLOG helper tests passed.
* Firmware built locally.
* Hardware SD runtime validation not performed.

### 1B — Wire daily writer to nested monthly paths

Status: completed in PR #368.

Outcome:

* New PTLOG files are written to `/logs/YYYY-MM/YYYYMMDD.RRR`.
* Same-day revisions are written under the same month directory.
* Legacy root compatibility preserved.
* Directory creation and daily PTLOG diagnostics added.

Validation:

* Host tests passed.
* Firmware built locally.
* Hardware SD runtime validation not performed.

### 1C — Daily PTLOG diagnostics

Status: completed in PR #368.

Outcome:

* Added diagnostics around path build, directory stat/mkdir/verify, revision scan, access, `fopen`, resume, header commit, and empty-file cleanup failures.
* Surfaced last daily PTLOG diagnostic through `diag sd`.

Validation:

* Firmware built locally.
* Hardware validation not performed.

## Phase 2 — SD reclaim and retention hardening

### 2A — Traversal-backed PTLOG reclaim

Status: completed in PR #369.

Outcome:

* `SdLoggerReclaimSpaceLocked()` now uses `SdPtlogFindOldestCandidate()`.
* Reclaim can select eligible compact PTLOGs from nested `/logs/YYYY-MM/`; root files are ignored by current policy.
* Reclaim deletes one candidate per pass.
* Reclaim recomputes free bytes after successful delete.
* Reclaim counts only successful `unlink()` calls.
* Current-date protection is preserved.
* No current-open path field was added.
* No file-count/directory-entry thresholds were added.
* No create/open retry was added.

Validation:

* Host path/reclaim-style tests passed.
* `git diff --check` passed.
* ESP-IDF firmware build was reported successful by user after local checkout.
* Hardware SD/FAT16 runtime validation not performed.

Branch/PR:

* Complete and merged.

Remaining checkpoint:

* Hardware validation still required before considering SD/FAT behavior fully proven.

### 2B — File-count and directory-entry-aware retention triggers

Status: next SD execute candidate after validation.

Goal:

* Add retention triggers beyond free byte space.

Likely scope:

* Count total PTLOG files across approved locations.
* Count PTLOG files per relevant directory.
* Add conservative estimated FAT long-filename directory-entry pressure metric if approved.
* Trigger reclaim when configured thresholds are exceeded.
* Preserve PTLOG-only, regular-file-only, bounded traversal, current-date protection, and one-candidate-per-pass deletion.
* Do not add create/open retry in this task unless explicitly approved.

Needs read-only planning first:

* Yes.

Why:

* Thresholds are product policy.
* Must decide exact compact nested limits; root legacy cleanup is not part of firmware reclaim.
* Must avoid Codex inventing retention policy.

Dependencies:

* 2A complete.
* Prefer hardware/build checkpoint after 2A before execution.
* Product decision required for threshold values.

Branch/PR:

* Separate draft PR from 2A.
* Can share one branch with only tightly related threshold/count code and tests.
* Do not combine with 2C.

High-risk checkpoint:

* Yes. Requires build and hardware/SD-media validation.

### 2C — Reclaim on daily create/open failure and retry

Status: deferred but important.

Goal:

* If daily PTLOG create/open fails with an approved errno/failure class, run reclaim even if free bytes are high, then retry open once.

Likely scope:

* Capture `errno` immediately on daily `fopen` failure.
* Classify operation as daily file open/create.
* If errno suggests space/create/directory-entry pressure, reclaim one approved candidate.
* Retry `fopen` once.
* Preserve diagnostics.
* If retry fails, report specific status/diagnostic.

Needs read-only planning first:

* Yes.

Why:

* Policy decisions are needed for errno list, retry count, candidate count, and status behavior.

Dependencies:

* 2A complete.
* Prefer 2B complete, unless a create/open failure is urgent enough to do 2C first.
* Requires precise diagnostic propagation review.

Branch/PR:

* Separate PR from 2B.
* Do not combine with display/ntfy status split.

High-risk checkpoint:

* Yes. Requires build plus hardware validation with induced create/open failure if feasible.

### 2D — SD diagnostic propagation and status specificity

Status: deferred after 2B/2C planning.

Goal:

* Preserve operation/path/errno/ESP error details from SD logger into runtime status and operator-visible diagnostics.

Likely scope:

* Structured SD failure detail.
* Last operation.
* Last path.
* Last errno and errno text.
* Whether reclaim was attempted.
* Whether create/open failure was suspected directory-entry pressure.

Needs read-only planning first:

* Yes.

Dependencies:

* 2C likely informs diagnostic fields.
* Must coordinate with display/ntfy split.

Branch/PR:

* Separate PR.
* May share with 2E only if planned together.

High-risk checkpoint:

* Moderate. Requires tests and operator-status review.

### 2E — SD display/status code split

Status: deferred.

Goal:

* Replace or supplement overloaded `SDOUT`.

Likely scope:

* Distinguish no card, mount failure, I/O error, out of byte space, create/directory failure, and degraded/backoff.
* Update display/status/ntfy wording only where scoped.
* Avoid changing storage mechanism in the same task.

Needs read-only planning first:

* Yes.

Dependencies:

* 2D recommended first.
* Must decide display code taxonomy.

Branch/PR:

* Separate PR from storage mechanism changes.

High-risk checkpoint:

* Medium. Operator-facing wording and alerts require review.

## Phase 3 — SD hardware and field validation

### 3A — Hardware validation after PR #368 and PR #369

Status: required; not completed in available context.

Goal:

* Validate nested write and traversal-backed reclaim on target ESP32 hardware and actual SD media.

Test matrix:

* Known-good industrial SD card.
* FAT16/current format.
* Old root/long-name PTLOG-looking files present and ignored.
* Nested `/logs/YYYY-MM/` PTLOGs.
* Low-free-space or forced reclaim condition.
* Current-date PTLOG present.
* PTLOG-looking directory present if safe to stage.
* Non-PTLOG file present.
* System directory present if naturally created.

Checks:

* New daily file creates under `/logs/YYYY-MM/`.
* Same-day revision behavior still works.
* Reclaim deletes old eligible nested PTLOG.
* Reclaim does not delete current-date PTLOG.
* Reclaim does not delete non-PTLOG files.
* Reclaim counters/status behave as expected.
* No unexpected mount/backoff behavior.

Needs read-only planning first:

* No, can be a validation checklist/task.

Branch/PR:

* No code branch required unless validation reveals defects.

High-risk checkpoint:

* Yes. This is the checkpoint before claiming SD/FAT behavior is proven.

### 3B — Long-duration pilot

Status: deferred until 2B/2C or at least 3A passes.

Goal:

* Run long enough to verify daily rollover, nested monthly file creation, FRAM drain, and absence of stale error states.

Scope:

* Multi-day logging.
* Date rollover.
* Optional month-boundary simulation if feasible.
* SD removal/reinsert recovery.
* FRAM buffering and drain.
* Status/ntfy observation.

Needs read-only planning first:

* No, but create a clear checklist.

Branch/PR:

* No code branch required unless defects are found.

High-risk checkpoint:

* Yes, field reliability checkpoint.

## Phase 4 — FRAM active-vs-historical overrun fix

### 4A — Plan FRAM overrun semantic split

Status: next major non-SD workstream after SD reclaim/create diagnostics are stable.

Goal:

* Separate historical data-loss accounting from current live FRAM pressure.
* Explicitly address repeated stale `fram_overrun - active` ntfy after SD recovery and FRAM drain.

Needs read-only planning first:

* Yes.

Why:

* This changes status/alert semantics and must not hide real data loss. The stale FRAM ntfy symptom is known and deferred; it is not part of static SD/PTLOG path-workspace work.

Dependencies:

* SD work should be stable enough that FRAM behavior can be evaluated without storage noise.
* Review current `fram_log.c`, `runtime_manager.c`, ntfy/status/display paths, and tests.

Branch/PR:

* Separate PR from SD tasks.

High-risk checkpoint:

* Yes. Alert semantics and audit behavior are high risk.

### 4B — Implement FRAM active-vs-historical status fields

Status: deferred until 4A plan approved.

Likely scope:

* Track lifetime overrun total.
* Track session baseline.
* Track last seen total.
* Track unacknowledged historical overrun separately from active live pressure.
* Alert on new/current overrun, not stale historical state.
* Preserve audit trail that data loss occurred.

Needs read-only planning first:

* Already covered by 4A.

Branch/PR:

* Separate PR.

Validation:

* Unit tests for boot with historical overrun.
* Unit tests for new overrun during session.
* Unit tests for SD recovery and FRAM drain clearing active pressure while preserving historical/unacknowledged state.

### 4C — Fix misleading FRAM warning logs

Status: deferred.

Goal:

* Replace live-overwrite wording when only historical overrun is observed.

Needs read-only planning first:

* Maybe not if 4A/4B already specify behavior.

Branch/PR:

* Can share with 4B if tightly scoped and planned.
* Otherwise separate.

### 4D — Fix or remove `LOG_RECORD_FLAG_FRAM_FULL`

Status: deferred.

Goal:

* Address post-append mutation of `record.flags` that may not affect stored FRAM record.

Needs read-only planning first:

* Yes.

Why:

* Must decide whether this flag is required as per-record audit data or should be removed.

Branch/PR:

* Separate PR unless 4A concludes it is part of the same status model.

## Phase 5 — Host tools and reporting alignment

### 5A — Verify host tools discover nested PTLOG files

Status: deferred but should occur before relying on field cards with nested logs.

Goal:

* Ensure host-side plotting/reporting/analysis tools handle `/logs/YYYY-MM/` and compact nested PTLOG files.

Needs read-only planning first:

* Yes, inspect host tools first.

Scope:

* Search for root-only assumptions.
* Add recursive/bounded discovery in host tools if needed.
* Preserve explicit user file selection behavior where present.
* Add tests with root and nested sample files.

### 5A-PTLOG-HOST-RECOVER — Host-side tolerant PTLOG ingestion and corrupt-tail handling

Status: deferred, required after firmware tail-repair direction changes.

Requirements:

* Scan all approved compact nested PTLOG revision files: `/sdcard/logs/YYYY-MM/YYYYMMDD.RRR`.
* Tolerate partial or corrupt trailing records/lines.
* Extract all valid records that can be parsed safely.
* Deduplicate by `record_id`.
* Report skipped/corrupt records with file names, offsets or line numbers when available, and reason codes.
* Do not let one corrupt revision/file prevent processing of other valid files.
* Keep any historical root/legacy file support separate and explicit because firmware ignores firmware-created root/legacy files.

Branch/PR:

* Separate host-tool PR.

High-risk checkpoint:

* Medium. Affects data retrieval/reporting, not embedded runtime.

### 5B — Validation ledger anchor

Status: deferred docs/admin task.

Goal:

* Track builds, host tests, hardware tests, SD media tests, known unverified items, and field pilot results.

Needs read-only planning first:

* No.

Branch/PR:

* Can share with docs/admin anchor PR if concise.

## Expansion / future tasks

These are future tasks, not part of the active SD/FAT16 fix unless explicitly promoted:

1. Task 2B-3A adopted new nested `YYYYMMDD.RRR` FAT 8.3 PTLOG filenames and `#PT100_LOG_V1` magic identity; next implement read-only pressure/status scanning.
2. Evaluate FAT32 migration only if field evidence justifies it.
3. Add richer SD diagnostics to ntfy messages.
4. Add operator acknowledgement workflow for historical FRAM data-loss state.
5. Add maintenance command to list PTLOG counts by root/month directory.
6. Add maintenance command to report estimated FAT directory-entry pressure.
7. Add optional empty-month-directory cleanup after retention, if approved.
8. Add current-open PTLOG path tracking, if same-day revision reclaim or more precise protection becomes necessary.
9. Add consolidated validation harness for SD/FRAM recovery scenarios.
10. Add field-pilot checklist and operator guide.

## Explicitly deferred tasks

Deferred until after SD Task 2A validation:

* File-count and directory-entry-aware retention triggers.
* Daily create/open reclaim retry.
* SD status/display/ntfy taxonomy replacement.
* FRAM active-vs-historical overrun semantics.
* `LOG_RECORD_FLAG_FRAM_FULL` fix/removal.
* Empty month directory cleanup.
* Short 8.3 filename design.
* FAT32 migration.
* Host tool recursive/nested discovery changes, unless host tool failure blocks data analysis.

## Explicitly rejected or deprecated paths

Rejected/deprecated unless a later decision reverses them:

1. Root-only PTLOG model.
2. Root-only reclaim.
3. Treating free byte space as the only final retention signal.
4. Treating `SDOUT` as precise “out of byte space.”
5. Treating historical cumulative FRAM overrun as current active pressure.
6. Unbounded SD directory traversal.
7. Automatic deletion of non-PTLOG files.
8. Automatic deletion of current-date PTLOG files.
9. Broad cleanup PRs mixed with reliability fixes.
10. Claiming hardware validation from host tests or firmware build alone.

## Task dependencies and sequencing

Current recommended sequence:

1. Complete the documentation correction that abandons the generic scratch-owner direction and records the revised static SD/PTLOG path-workspace roadmap.
2. Implement `2B-3B-1R` static PSRAM-backed SD/PTLOG path workspace only.
3. Implement `2B-3B-2` firmware tail-repair/resume removal and always-new-revision-on-uncertainty policy.
4. Implement `5A-PTLOG-HOST-RECOVER` host-side tolerant corrupt-log ingestion and `record_id` deduplication.
5. Plan and execute read-only bounded PTLOG pressure/status scan facts.
6. Plan Task 2B read-only: file-count/directory-entry-aware retention triggers.
7. Execute Task 2B after threshold policy approval.
8. Hardware validate Task 2B.
9. Plan Task 2C read-only: daily create/open reclaim retry.
10. Execute Task 2C after errno/retry policy approval.
11. Hardware validate Task 2C.
12. Plan and execute SD diagnostic/status split.
13. Plan and execute FRAM active-vs-historical overrun fix, including stale `fram_overrun - active` ntfy after recovery/drain.
14. Verify host tools discover nested PTLOG files.
15. Run long-duration pilot.

## Branch / PR grouping guidance

Tasks that can share one draft PR branch:

* Phase 0 anchor files can share one docs/admin PR if no firmware source is touched.
* A documentation-only validation ledger can share the same docs/admin PR if concise.

Tasks that should be separate PRs:

* Task 2B threshold-based retention triggers.
* Task 2C create/open reclaim retry.
* SD diagnostic/status propagation.
* SD display/ntfy status split.
* FRAM active-vs-historical overrun semantic fix.
* `LOG_RECORD_FLAG_FRAM_FULL` fix/removal.
* Host tool nested PTLOG discovery and tolerant corrupt-tail recovery/deduplication.

Do not combine:

* SD storage mechanism changes with FRAM semantic changes.
* Display/ntfy wording changes with reclaim mechanism changes.
* Product-policy threshold decisions with unrelated cleanup.
* Anchor docs with firmware behavior changes unless explicitly requested.

## Tasks requiring read-only planning first

Require read-only planning first:

1. Task 2B-3B-1R: static PSRAM-backed SD/PTLOG path workspace.
2. Task 2B: file-count/directory-entry-aware retention triggers.
3. Task 2C: create/open reclaim retry.
4. Task 2D: SD diagnostic propagation/status specificity.
5. Task 2E: SD display/status code split.
6. Task 4A/4B: FRAM active-vs-historical overrun model.
7. Task 4D: `LOG_RECORD_FLAG_FRAM_FULL` fix/removal.
8. Task 5A / 5A-PTLOG-HOST-RECOVER: host tools nested PTLOG discovery and tolerant corrupt-tail ingestion/deduplication.
9. Any FAT32 migration or short 8.3 filename change.
10. Any automatic deletion of current-date or same-day revision PTLOGs.

## Tasks that can be focused execute tasks

Can be focused execute tasks if already approved:

1. Create/update anchor docs from approved chat drafts.
2. Add validation ledger anchor.
3. Update PR/body wording or docs wording where behavior is already settled.
4. Add narrowly scoped tests for already-settled helper behavior.
5. Add hardware validation checklist docs.

## High-risk tasks requiring checkpoint validation

High-risk tasks:

1. File-count/directory-entry retention triggers.
2. Create/open reclaim retry.
3. Any automatic deletion policy change.
4. Any SD format or filesystem configuration change.
5. Any display/ntfy status taxonomy change.
6. FRAM active-vs-historical overrun semantic change.
7. Any host tool change that affects interpretation/export/reporting of logged data.
8. Any migration/rewrite/move of existing PTLOG files.

Checkpoint requirements:

* Source review.
* Host tests where practical.
* `git diff --check`.
* ESP-IDF build for firmware changes.
* Hardware validation for SD/FAT behavior.
* Operator-facing review for display/ntfy wording.
* Explicit list of unverified items.

## Completed tasks still needing integrated validation

Completed but not fully integrated-validated:

1. PR #368 nested monthly PTLOG writes.

   * Host tests passed.
   * Firmware build reported successful.
   * Hardware SD runtime validation not verified.

2. PR #369 traversal-backed PTLOG reclaim.

   * Host tests passed.
   * Firmware build reported successful.
   * Hardware SD/FAT16 reclaim validation not verified.

3. Drafted anchors in chat.

   * Project intent anchor drafted.
   * Requirements/constraints anchor drafted.
   * Decision log anchor drafted.
   * Roadmap anchor drafted here.
   * Repository commits unverified.

## Deferred/future scoped tasks that must remain visible

* `2B-3B-1R` static PSRAM-backed SD/PTLOG path workspace implementation.
* `2B-3B-2` firmware tail-repair/resume removal and always-new-revision-on-uncertainty policy.
* `5A-PTLOG-HOST-RECOVER` host-side corrupt log handling and `record_id` deduplication.
* PTLOG pressure/read-only scan facts.
* File-count/directory-entry-aware retention triggers.
* Daily create/open failure retry/reclaim policy.
* SD diagnostic/status specificity.
* Display/ntfy status wording split.
* FRAM active-vs-historical overrun semantic fix, including stale `fram_overrun` active alerts after recovery/drain.
* `LOG_RECORD_FLAG_FRAM_FULL` ordering/fix/removal if still applicable.
* Host tools nested PTLOG discovery/ingestion.
* Runtime file-buffer sizing review, including old 64 KiB fallback versus current Kconfig defaults.
* CSV tail-scan buffer sizing/removal review, including old 256 KiB fallback versus current configured default.
* Hardware validation after SD/PTLOG changes.
* Long-duration pilot validation.

## Current next required action

Recommended next actions, in order:

1. Documentation correction to abandon the generic scratch-owner direction and record the revised static SD/PTLOG path-workspace direction.
2. `2B-3B-1R — Replace SD/PTLOG stack path buffers with static PSRAM-backed path workspace`.
3. `2B-3B-2 — Remove firmware tail repair/resume scan and always create new revision on uncertainty`.
4. `5A-PTLOG-HOST-RECOVER — Host-side tolerant PTLOG ingestion and corrupt-tail handling`.
5. Resume the broader SD pressure/reclaim/status roadmap: read-only pressure scan facts, file-count/directory-entry retention triggers, create/open retry/reclaim policy, SD diagnostic specificity, display/ntfy wording split, FRAM semantic fixes, hardware validation, and long-duration pilot validation.

Do not merge PR #376 as-is. Its scratch-owner implementation is abandoned for now and preserved only on `archive/scratch-owner-pr376-0819853` for reference. Do not start read-only PTLOG pressure/status scan facts, retention thresholds, create/open retry, display/ntfy changes, FRAM semantic fixes, host-tool ingestion changes, or SD format changes as part of the path-workspace implementation. The repeated stale `fram_overrun - active` ntfy after SD recovery and FRAM drain remains a known deferred FRAM active-vs-historical semantic defect.

## Last updated context

This roadmap was drafted from:

* Current conversation through merged PR #369.
* Current GitHub repository `rasusmilch/PT100_Mesh_Datalogger`, default branch `main`.
* PR #368: `Move PTLOG writes to FAT16-safe log directories`, merged at `939ac9b717373a6ce5e9b38e9f4dfae112be2e43`.
* PR #369: `Refactor SD reclaim to use SdPtlogFindOldestCandidate and add reclaim unit tests`, merged at `1e9dffa51d6409c9c63dfbee5410525e9f406bbc`.
* Current `main/sd_logger.c` reclaim implementation after PR #369.
* Current `main/sd_ptlog_paths.c` bounded PTLOG scanner.
* `docs/sd_fram_failure_2026_06_23_analysis.md`.
* Codex Task 2A planning and execution receipts.
* ChatGPT senior review of Task 2A execution.
* Drafted project intent, requirements/constraints, and decision log anchors from this chat.

Unverified at this update:

* Real hardware SD/FAT16 validation after PR #368 and PR #369.
* Long-duration field behavior after nested monthly PTLOG writes and reclaim changes.
* Full host-tool support for nested `/logs/YYYY-MM/` PTLOG discovery.
* Display/ntfy status split implementation.
* FRAM active-vs-historical overrun fix implementation.
* Whether project intent, requirements/constraints, decision log, roadmap, code documentation policy, or validation ledger anchors have been committed after this draft.

## Task 2B-3 staged PTLOG filename, pressure scan, and reclaim work

### 2B-3A — YYYYMMDD.RRR filename and PTLOG magic foundation

Status: implemented in this branch. New nested firmware PTLOG files use `/sdcard/logs/YYYY-MM/YYYYMMDD.RRR` with decimal revisions `000` through `999`; legacy/root long-name `.ptlog` compatibility is removed; old files are ignored by firmware. PTLOG identity is formalized around the first-line `#PT100_LOG_V1` magic. No migration, display progress, read-only pressure expansion, create/open retry, or reclaim policy change is included.

### 2B-3B-DOC1 / DOC2 — Superseded storage scratch-owner documentation

Status: superseded by Task 2B-3B-DOC3. Earlier anchors described a centrally owned PSRAM-backed storage scratch owner with a future slot-style design. That direction is abandoned for now.

### 2B-3B-DOC3 — Abandon scratch owner and record revised SD/PTLOG roadmap

Status: documentation-only correction. Record that PR #376 is not the intended architecture and must not be merged as-is; preserve it only on `archive/scratch-owner-pr376-0819853`; replace the generic scratch-owner path with a narrow static SD/PTLOG path-workspace direction; record the tail-repair removal decision; and add host-tool corrupt-log recovery/deduplication requirements.

### 2B-3B-1R — Replace SD/PTLOG stack path buffers with static PSRAM-backed path workspace

Status: next implementation after the documentation correction. Move SD/PTLOG path, filename, month directory, candidate path, and related path-workflow buffers that are currently local stack arrays to centrally owned static storage where practical. Prefer PSRAM-backed storage on target when safe and available. Keep the implementation narrow: path/candidate buffer placement only. Do not create a generic allocator, slot pool, borrow/release API, concurrency framework, CSV tail repair change, file-buffer sizing change, SD format change, reclaim policy change, display/ntfy wording change, FRAM semantic change, or host-tool ingestion change. Explicitly document ownership, lifetime, capacity, and runtime serialization/locking assumptions.

### 2B-3B-2 — Remove firmware tail repair/resume scan and always create new revision on uncertainty

Status: future dedicated implementation. Runtime firmware tail repair/resume scanning is abandoned. On boot, SD remount, recovery, restart, header/signature uncertainty, or prior-file uncertainty, firmware should create a new same-day revision file instead of repairing/appending to the uncertain old one. Old/corrupt/partial revision files are preserved for host-side recovery. Firmware must still avoid consuming or discarding FRAM records until append/verify to the active revision succeeds. This removes historical CSV sequence-resume baggage and associated large tail-scan buffers in a scoped code task, not in documentation.

### 2B-3B — Read-only bounded pressure/status scan model

Status: after 2B-3B-1R path-workspace implementation and tail-repair/host-recovery sequencing as approved. Add richer read-only scan facts without deletion or full-card recursion, but do not merely add scan facts on top of large task-stack PTLOG path buffers.

### 2B-3C — Compact MAX7219 scan progress

Status: later. Add throttled count-up display states only after scan/status architecture is validated.

### 2B-3D — Pressure-targeted reclaim

Status: later. Reclaim actions must directly relieve the pressure class; directory-count cleanup remains unapproved unless explicitly decided.

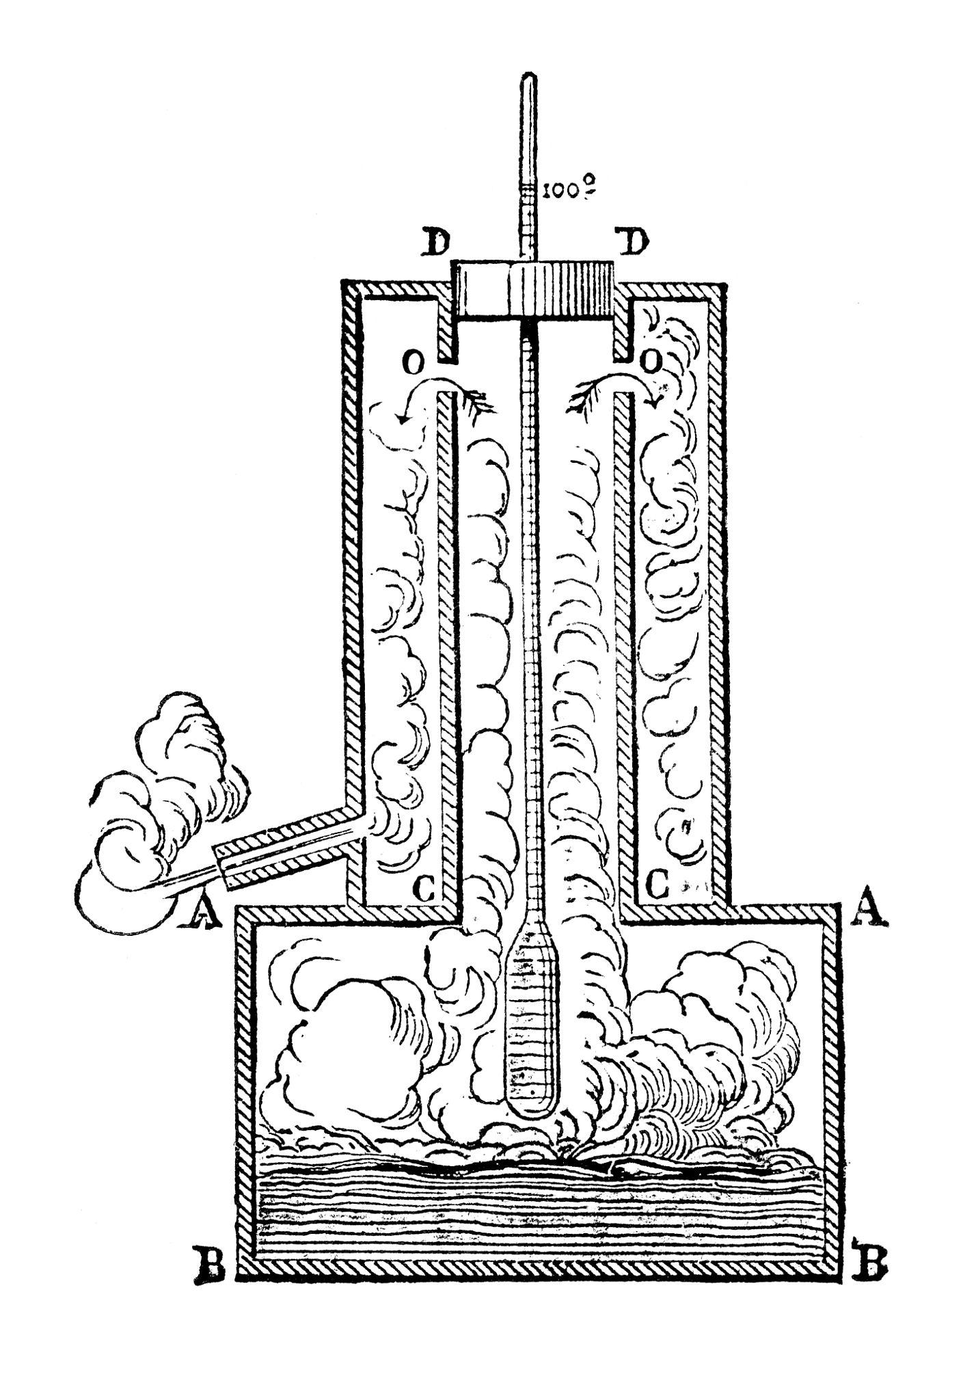
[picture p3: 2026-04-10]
documents/Hypsometer (Steam point bath).jpg

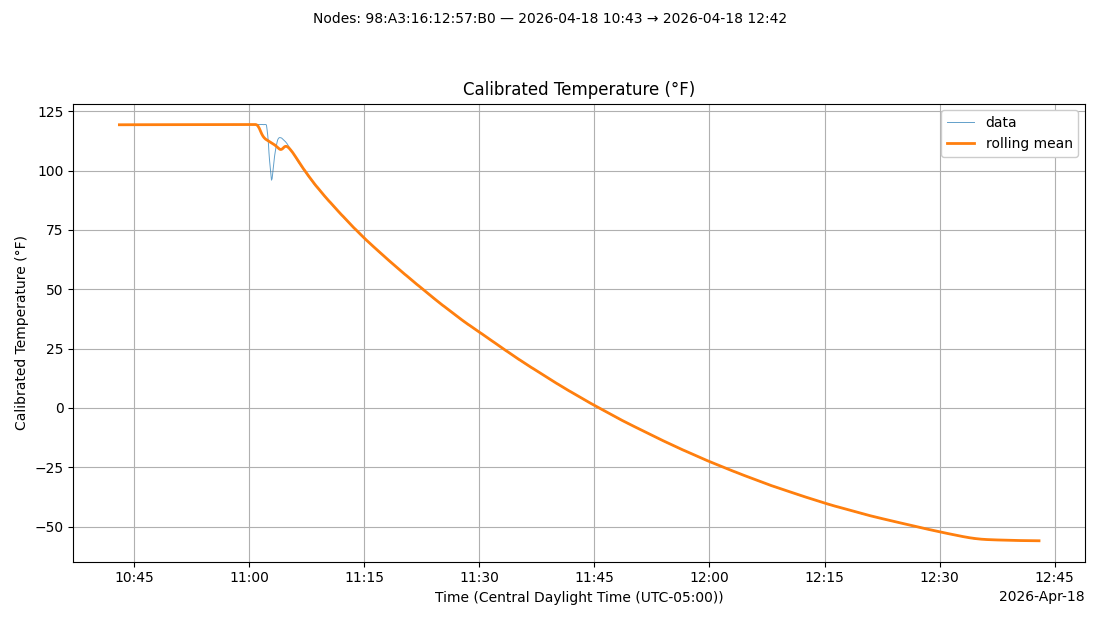
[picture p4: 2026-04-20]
documents/Figure_1.png

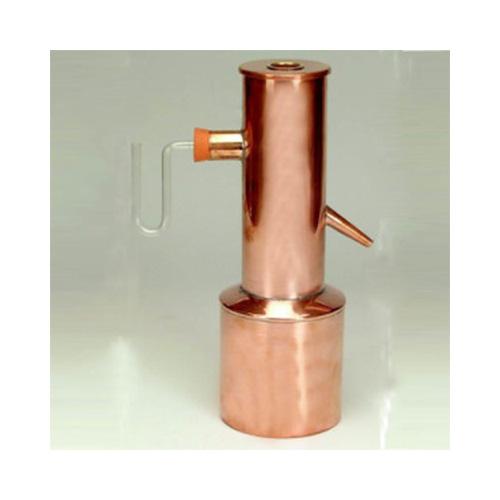
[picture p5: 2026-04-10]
documents/Hypsometer 3.jpg

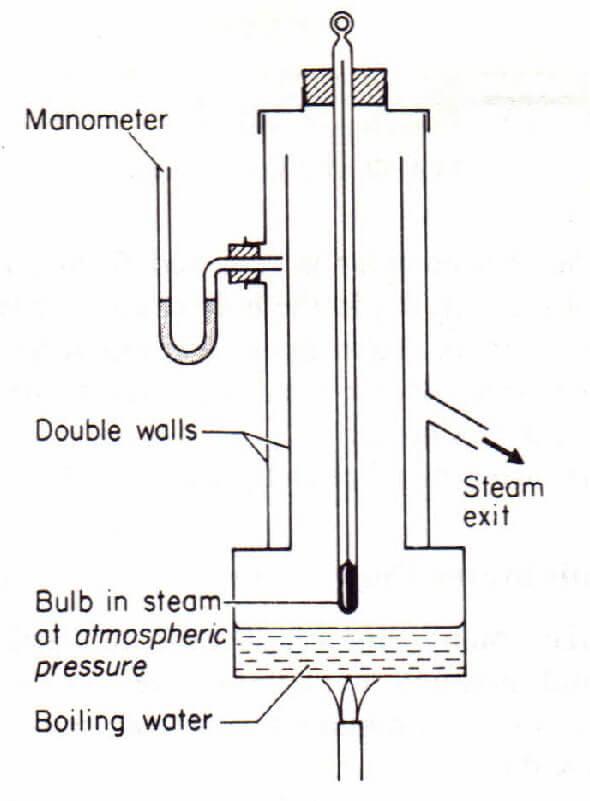
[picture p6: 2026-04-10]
documents/Hypsometer 2.jpg

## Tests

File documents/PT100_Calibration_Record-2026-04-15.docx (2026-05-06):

# CALIBRATION RECORD

PT100 Temperature Datalogger System

Certificate No. | [to be assigned] | Date of Calibration | 2026-04-15
Asset ID | [to be assigned] | Calibration Due Date | 2027-04-15
Alternate Unique ID | MAC 98:A3:16:12:57:B0 | Reference Indicator | Fluke 51 II N1052
Reference Probe | Wahl TC801P Type K | Transfer Block | Epicor 1126212

# 1. Instrument Identification

Instrument Under Test (IUT): PT100 temperature datalogger system

Sensor: Omega PR-21D-3-100 platinum resistance thermometer

Sensor Configuration: 4-wire RTD

Measurement Electronics: MAX31865 RTD interface, 430 ohm reference resistor

Transfer Block Material: 6061-T6 aluminum

Reference Thermocouple Probe: Wahl TC801P Type K thermocouple probe, 1/8 in diameter, approximately 12 in long, standard thermocouple connector

# 2. Statement of Calibration

The IUT was calibrated as a complete corrected measurement system using a resistance-domain polynomial calibration derived from comparison against the reference thermometer system identified in this certificate.

This certificate applies to the corrected PT100 probe-plus-readout system in service. The retained source record documents the calibration-point dataset used to generate and apply the active correction model and includes the active polynomial form and coefficients. Accordingly, this certificate documents the calibration-point data, the active correction equation, the calibration coefficients, and the uncertainty statement for the corrected system.

The active resistance-domain polynomial coefficients are listed in Section 4.

# 3. Calibration Method

Calibration was performed by transfer comparison in a Thermotron environmental chamber using the custom aluminum transfer block identified above. The reference Type K thermocouple probe and the IUT probe were inserted into adjacent transfer-block bores at nominally equal depth. Setpoints were allowed to stabilize prior to data capture.

The transfer block was manufactured from 6061-T6 aluminum, which has typical thermal conductivity of approximately 167 W/m·K at 77 °F. Dry-block calibration performance, however, depends not only on block material but also on axial and radial uniformity, probe fit, stem conduction, loading, and external influences.

# 4. Calibration Conditions and Capture Controls

The resistance-domain correction applied by the system is R_(corrected) =ax^2 +bx+c , where x is the measured raw resistance in ohms and the calibrated coefficients are those listed in the table below.

Calibration mode | Polynomial
Calibration domain | Resistance (ohm)
Capture window | 60 seconds
Drift limit | 0.020 °C/min
Runtime correction path | Raw measured ohms → corrected ohms → corrected temperature
Calibration equation | R_(corrected) =ax^2 +bx+c , where x = raw measured resistance (ohm)
Coefficient a | 0.000124274878
Coefficient b | 0.968385256
Coefficient c | 1.95552775

For this certificate, residuals are defined as follows:

∆T_i =T_(ref,i) -T_(raw,i)

∆R_i =R_(ideal,i) -R_(raw,i)

Positive residual temperature therefore indicates that the raw uncorrected IUT reading was lower than the reference temperature at that point.

# 5. Calibration Data Used for the Active Correction Model

Point | Ref. Temp. (°C) | Captured Raw Avg. Temp. (°C) | Residual Temp. (°C) | Raw Temp. Std. Dev. (°C) | Drift (°C/min) | Delta (°C)
1 | -48.900 | -49.455 | +0.555 | 0.018 | -0.018 | -0.011
2 | -13.300 | -13.467 | +0.167 | 0.019 | +0.007 | +0.006
3 | 24.700 | 24.718 | -0.018 | 0.019 | -0.003 | -0.003
4 | 81.600 | 81.742 | -0.142 | 0.017 | +0.002 | +0.002

The retained source export records this calibration as valid, applied, time-valid, and due on 2027-04-15.

The largest raw temperature residual in the source dataset was +0.555 °C at -48.900 °C, and the smallest was -0.142 °C at 81.600 °C. The raw captured point standard deviations remained between 0.017 and 0.019 °C in temperature and between 0.006 and 0.007 ohm in resistance across the four calibration captures.

Figure 1 is provided as a supplemental visual aid comparing the raw captured calibration-point residuals against the residuals remaining after application of the resistance-domain polynomial model. The figure is intended to aid interpretation only and does not replace the tabulated calibration data, fit statistics, or uncertainty statement.

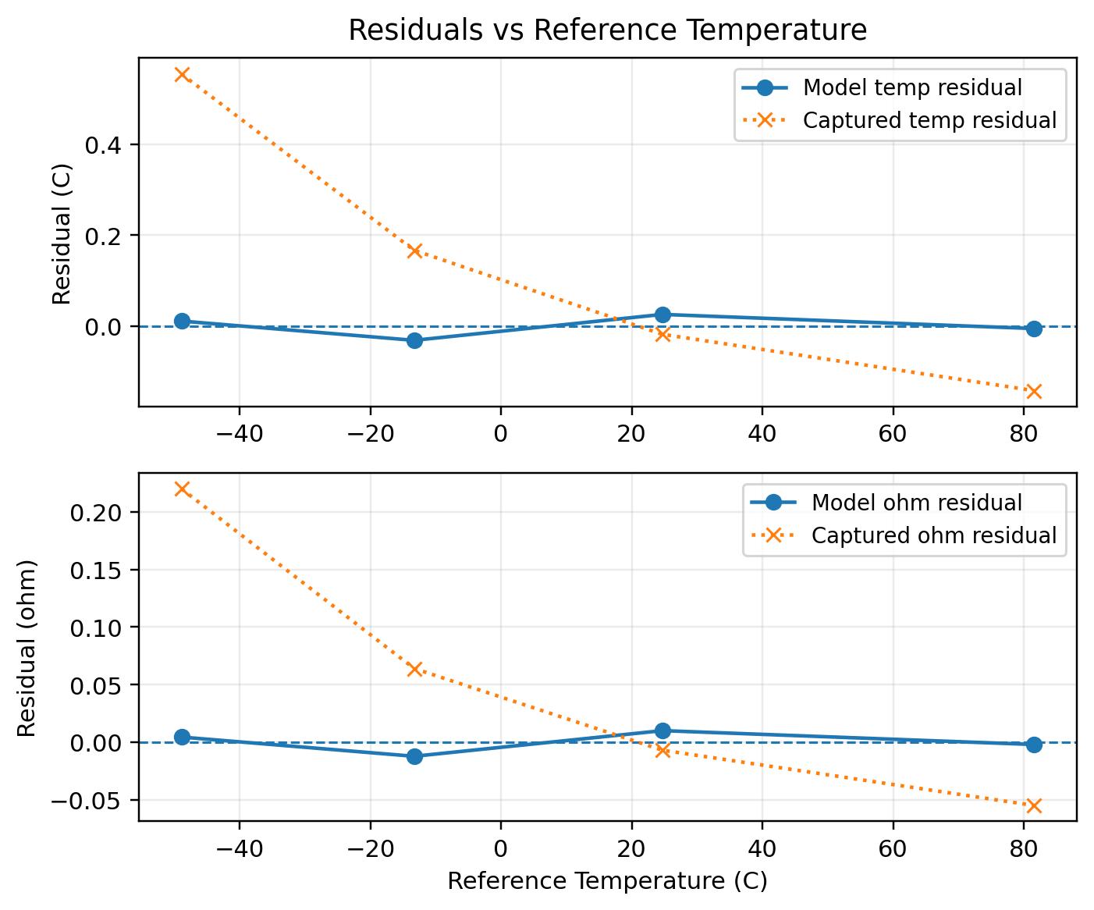
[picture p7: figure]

Figure 1. Calibration-point residual comparison before and after application of the resistance-domain polynomial correction model. The figure illustrates improvement at the stored calibration points only.

# 6. Supporting Verification of IUT Repeatability

A separate PT100 repeatability study was performed in a slush ice bath and is included here only as supporting verification of short-term IUT stability, not as a direct contributor in the formal transfer-calibration uncertainty budget.

Number of independent runs | 5
Samples per run | 30
Resistance range | 99.964-99.971 ohm
Resistance spread | 0.007 ohm
Temperature residual range | +0.074-0.092 °C
Temperature spread | 0.018 °C
Per-run standard deviation | 0.005-0.007 °C
Practical repeatability | ±0.01°C to ±0.02°C

These results support the conclusion that short-term PT100 measurement repeatability was small relative to the final reference-chain uncertainty stated in Section 8.

# 7. Supporting Verification of Transfer-Block Bore Performance

A bore-bracketing study was performed at the 48.8°C (120 °F) setpoint using A-B-A and B-A-B sequences, including a 180-degree block rotation.

When reduced to a common B-A basis, the observed combined mean bore difference was approximately +0.0074 °C, with combined RMS variation of approximately 0.025 °C and maximum observed magnitude of approximately 0.049 °C.

The sign did not reverse after block rotation, indicating a small bore-dependent effect rather than a dominant chamber-side asymmetry. These results support use of a small transfer-medium contribution relative to the reference thermocouple contribution.

# 8. Uncertainty Analysis

## 8.1 Reference Indicator Contribution

The Fluke 51 II calibration certificate for Gage ID N1052 states uncertainty of 0.08 °C at 95% confidence level for Type K over the range -55 °C to 1000 °C and explicitly states that thermocouple error is not included. For the formal uncertainty budget, this was treated as approximately k = 2.

u_(meter) =0.08/2=0.04°C

## 8.2 Reference Thermocouple Contribution

A current probe-specific calibration certificate was not available for the Wahl TC801P thermocouple probe used during calibration. The probe was therefore modeled conservatively as a standard commercial Type K thermocouple using the published standard limits of error.

Across the temperature range used in this calibration, the ±2.2°C term governs. To incorporate this value into a formal uncertainty budget, the class limit was treated as a rectangular Type B distribution.

u_(probe) =2.2/(√3)=1.27°C

## 8.3 Transfer and Setup Contribution

The transfer and setup contribution was based on the measured bore study and the physical transfer arrangement. Standard uncertainties of 0.03 °C each were assigned to radial bore difference/probe-spacing effect, insertion depth sensitivity, thermal coupling/fit variation, and block gradient/environmental coupling.

u_(transfer) =√(0.03^2 +0.03^2 +0.03^2)=0.06°C

## 8.4 Combined Standard Uncertainty

u_c =√(u_(meter) ^2 +u_(probe) ^2 +u_(transfer) ^2)

u_c =√(0.04^2 +1.27^2 +0.06^2 =1.27°C)

## 8.5 Expanded Uncertainty

Expanded uncertainty is reported using k = 2, consistent with NIST convention for reporting expanded uncertainty.

U=2u_c =2(1.27)=2.54°C

Reported Expanded Uncertainty: +/-2.6 °C (k = 2)

# 9. Calibration Result

The PT100 datalogger system identified in this certificate was calibrated as a complete corrected system using a 4-point resistance-domain polynomial calibration referenced to the Fluke 51 II indicator and Wahl TC801P Type K thermocouple identified above. The active correction equation and coefficients documented in Section 4 are part of the corrected system configuration covered by this certificate.

This uncertainty is dominated by the reference thermocouple contribution. The PT100 repeatability and transfer-block contributions were small relative to the reference thermocouple term.

# 10. Applicability and Validity

This certificate applies only to the specific PT100 probe-and-readout combination identified in Section 1, in the calibrated configuration used at the time of calibration. It does not apply to the sensor alone, the electronics alone, or any substituted reference probe. Continued validity is contingent on the system remaining in the same calibrated configuration and not undergoing damage, repair, or material change affecting measurement performance.

# 11. Authorization

Calibrated by | Robert Susmilch | 2026-04-15
Reviewed by
Approved by

# 12. References

[1] MatWeb, Aluminum 6061-T6 Material Data Sheet, thermal conductivity approximately 167 W/m K at 77 degF.

[2] ASTM E3186, Standard Guide for Use and Testing of Dry-Block Temperature Calibrators.

[3] Fluke 51 II calibration certificate, Gage ID N1052, Certificate No. 4015405, calibrated 2026-02-16; stated uncertainty 0.08 °C at 95% confidence for Type K over -55 °C to 1000 °C; thermocouple error excluded.

[4] Omega Engineering, Type K Thermocouple Reference Table, standard limits of error +/-2.2 °C or applicable percent term, whichever is greater.

[5] NIST Technical Note 1297, Type B evaluation and expanded uncertainty reporting.

Calibration Certificate - PT100 Temperature Datalogger System

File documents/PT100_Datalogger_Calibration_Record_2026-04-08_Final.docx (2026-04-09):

# Temperature Datalogger Calibration Record

Internal calibration record for the PT100 datalogger.

# Revision History

Revision | Date | Description of Change | Approved By / Initials
0 | 2026-03-06 | Initial editable calibration record issued for the single PT100 datalogger unit. | RS
1 | 2026-03-06 | Separated assigned calibration uncertainty from in-use allowance and added basis notes for assigned values. | RS
2 | 2026-04-08 | Updated template for Omega PR-21D-3-100-A-1/8-0300-M12-1, resistance-domain fixed-point calibration workflow, steam-column method, and revised uncertainty structure. | RS

# Instrument Identification

Item | Value
Instrument | PT100 Temperature Datalogger
Calibration ID
Internal ID (MAC address) | 98:A3:16:12:57:B0
Controller | ESP32-S3
RTD Interface | MAX31865
Probe Model | Omega PR-21D-3-100-A-1/8-0300-M12-1
Probe Construction Notes | Pt100, Class A, 4-wire, 316L sheath, 1/8 in diameter, 3 in length, M12 connection
Location | Bemidji Test Laboratory
Atmospheric Pressure Source | KBJI METAR (Bemidji Regional Airport, adjacent to site) or local calibrated barometer if available
Calibration Domain in Firmware | Resistance-domain fixed-point model preferred (raw measured ohms -> corrected ohms -> corrected temperature)

# Measurement Configuration Snapshot

Item | Value
RTD Type | PT100
Wiring | 4-wire
Reference Resistor | 430 ohm
MAX31865 Filter | 60 Hz
MAX31865 Conversion Mode | PT100 table
Bias Settle Delay | 10 ms
Temperature Resolution | 0.03125 C nominal
Calibration Model | 2-point linear unless engineering change approves otherwise
Calibration Storage | ESP32 NVS
Record Note | Template should retain both temperature-domain values for readability and resistance-domain values for audit traceability.

# Calibration Procedure

Ice point procedure. Prepare distilled water and crushed ice as a true slush, not floating ice in bulk water. Immerse the sensing section deeply enough that the active element is fully surrounded by slurry. Gently move or stir the probe during stabilization to break up local pockets. Capture the point at 0.000 C.

Steam point procedure. Boil distilled water vigorously in a vented beaker and place the probe in the attached steam column so the sensing section is fully inside the saturated steam path and not in liquid water. Keep the column vented; do not seal the system. The steam reference temperature is calculated in firmware using satpt from either local station pressure or METAR altimeter plus site elevation. Record the exact pressure input used.

Model application. The firmware prefers resistance-domain calibration. During capture, the instrument stores raw average temperature, raw average resistance, and their stability statistics. During calibration application, the entered reference temperature is converted to ideal Pt100 resistance and the fit is performed in ohms; runtime correction then applies in ohms before converting back to temperature.

# Pressure / Steam Reference Record

Field | Record
Pressure source type | METAR
METAR Station / Barometer ID | KBJI - Bemidji Regional Airport
Calibration Date/Time (UTC) | 2026-04-08T20:12:33Z
Observation Time | 2026-04-08T19:55:00Z
Elevation used | 1391 feet
Altimeter Setting | A2969
Estimated Station Pressure | 28.23 inHg
Calculated Steam Temperature | 98.379
Notes | Probe centered in steam path; vent remained open.

# Calibration Data and Stored Calibration Points

Use the values actually reported by the firmware window/capture data. The record should preserve both operator-readable temperature residuals and the resistance-domain values actually used for fitting.

Point | Raw Avg (C) | Raw Avg (Ohm) | Reference (C) | Ideal Ref (Ohm) | Residual (C) | Residual (Ohm) | Std. Dev. (C) | Std. Dev. (Ohm)
Ice Point | -0.077 | 99.970 | 0.000 | 100.000 | 0.077 | 0.030 | 0.007 | 0.010
Steam Point | 98.688 | 138.891 | 98.379 | 137.891 | -0.309 | -0.121 | 0.027 | 0.003

# Stored Model / Coefficient Record

Coefficient Record | Value
Calibration mode | Linear
Calibration domain | Resistance

# Assigned Calibration Uncertainty

Purpose. This section states the assigned calibration uncertainty of the instrument as calibrated. The values below are recommended working values for this updated hardware and steam-column method. They should be confirmed or adjusted after the first few completed calibrations and after reviewing actual residuals.

Calibration component | Std. unc. (C) | Brief basis
Probe residual / interpolation allowance | 0.08 | Recommended starting value for the Class A probe after 2-point endpoint calibration in resistance domain. Tightened from the earlier template because the probe class is better and the fit is applied in ohms, but still leaves room for interpolation and element/sheath behavior.
Electronics / conversion / quantization | 0.03 | Carryover value for residual MAX31865 readout, reference resistor, conversion, and quantization effects after calibration.
Fixed-point realization (ice + steam column) | 0.07 | Reduced from the earlier steam-space allowance because the attached steam column gives a better defined saturated-vapor zone and reduces splash / surface-gradient ambiguity, while still keeping allowance for pressure estimation, venting, equilibration, and practical setup scatter.

Calculation. Combined calibration standard uncertainty u_c =√(0.08x^2 +0.03x^2 + 0.07x^2)= 0.110 C , rounded to 0.11 C. Assigned calibration expanded uncertainty U=kxu_c with k = 2, rounded to 0.22 C.

Meaning. When the logger is used as a calibrated instrument under conditions similar to the calibration setup, the indicated temperature is provisionally assigned a calibration uncertainty of approximately +/-0.22 C at k = 2. Replace this text if a different uncertainty budget is justified by actual study data.

# Assigned In-Use Allowance and Working Uncertainty

Purpose. This section separates real-world use effects from the calibration itself so the record shows both the calibration-only result and the more conservative working uncertainty used in service.

In-use component | Std. unc. (C) | Brief basis
Placement / coupling / stem-conduction allowance | 0.08 | Retained as a practical allowance for probe placement, thermal coupling, local gradients, insertion depth sensitivity, and stem-conduction effects during normal use. The shorter 3 in sheath does not justify relaxing this without actual use data.

Calculation. Combined working standard uncertainty u_w =√(0.110x^2 +0.08x^2)=0.136 C , rounded to 0.14 C. Assigned working expanded uncertainty U=kxu_w with k = 2, rounded to 0.27 C.

Meaning. This is the more conservative value to use for actual decisions, comparisons, and audit discussions when the instrument is being used outside the calibration setup.

# Residual Review Notes

- Residuals should now be reviewed in both Celsius and ohms. The Celsius residual remains useful for the record, but the ohmic residual better matches the actual fit domain used by the firmware.
- If a calibrated local barometer is available at the bench, it is preferable to METAR-derived pressure for the steam point and may justify a smaller steam-method allowance than 0.07 C.

# Traceability and Use Statement

This calibration is an internally controlled working calibration based on physical temperature reference points. The steam point reference may be derived either from a local barometer or from adjacent-airport METAR data converted in firmware to estimated station pressure. This record supports internal verification and audit documentation for the single custom datalogger unit. It is not an accredited laboratory calibration certificate.

# Authorization

Field | Value
Technician | Robert Susmilch
Calibration Date | 2026-04-08
Next Calibration Due | 1 year from calibration date unless shortened by policy or observed drift

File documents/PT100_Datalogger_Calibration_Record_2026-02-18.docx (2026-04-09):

# Temperature Datalogger Calibration Record

Internal calibration record for the single custom PT100 datalogger unit used in the test laboratory.

# Revision History

Revision | Date | Description of Change | Approved By / Initials
0 | 2026-03-06 | Initial editable calibration record issued for the single PT100 datalogger unit. | RS
1 | 2026-03-06 | Separated assigned calibration uncertainty from in-use allowance and added basis notes for assigned values. | RS

# Instrument Identification

Instrument | PT100 Temperature Datalogger (custom single unit)
Controller | ESP32-S3
RTD Interface | MAX31865
Probe Model | Omega PR-21D-3-100-A-1/8-0300-M12-1
Location | Bemidji Test Laboratory
Atmospheric Pressure Source | KBJI METAR (Bemidji Regional Airport, adjacent to site)

# Measurement Configuration Snapshot

Item | Value
RTD Type | PT100
Wiring | 4-wire
Reference Resistor | 430 ohm
MAX31865 Filter | 60 Hz
MAX31865 Conversion Mode | PT100 table
Bias Settle Delay | 10 ms
Temperature Resolution | 0.03125 C nominal
Calibration Model | 2-point linear
Calibration Storage | ESP32 NVS

# Calibration Procedure

Ice point procedure. Distilled water and crushed ice are prepared as a true slurry/slush, not floating ice in bulk water. The probe is immersed approximately 5 to 6 inches into the slush in a 2 L beaker. The probe is gently moved/stirred in the slurry during stabilization to minimize local pockets and maintain equilibrium at the sensing element. This point is assigned a reference temperature of 0.000 C.

Steam point procedure. Distilled water is boiled vigorously in a loosely covered beaker. The probe is placed several inches above the water surface within the steam space under the cover, without immersion in liquid water. The steam reference temperature is calculated in firmware from KBJI METAR pressure data by converting the reported altimeter setting to estimated station pressure and then calculating the saturation temperature of water at that pressure.

Model application. The raw measured temperatures at the two reference points are used to calculate and store a linear 2-point calibration model in nonvolatile memory within the datalogger.

# METAR Pressure Record

Field | Record
METAR Station | KBJI - Bemidji Regional Airport
Calibration Date/Time | 2026-02-18T17:56:35Z (UTC)
METAR Observation Time | 11:35 AM
Elevation (FAA Chart Supplement) | 1391 feet
Altimeter Setting | 29.23 inHg
Estimated Station Pressure | 27.804 inHg
Calculated Steam Temperature | 97.967 C
Notes | Airport is adjacent to calibration site

# Calibration Data and Stored Calibration Points

Point | Raw Avg (C) | Reference (C) | Residual (C)
Ice Point | 0.471 | 0.000 | -0.471
Steam Point | 98.206 | 97.967 | -0.239

## Coefficient Record

Coefficient Record | Value
Point 1 Raw | 0.471 C
Point 1 Actual | 0.000 C
Point 2 Raw | 98.206 C
Point 2 Actual | 97.967 C
Calibration Mode | Linear

# Assigned Calibration Uncertainty

Purpose. This section states the assigned calibration uncertainty of the instrument as calibrated. The values below are assigned internal working standard uncertainties based on manufacturer information, instrument design, the observed calibration method, and engineering judgment. They are not derived from a formal repeated-study uncertainty analysis.

Calibration component | Std. unc. (C) | Brief basis
Probe residual / interpolation allowance | 0.12 | Residual probe-model allowance after 2-point endpoint calibration. Based on the 1/3 DIN PT100 probe class, but smaller than the full uncalibrated end-of-range tolerance because endpoint offset and gain are already corrected.
Electronics / conversion / quantization | 0.03 | Residual MAX31865 readout contribution after calibration. Covers quantization plus small remaining reference/conversion effects; intentionally larger than bare LSB math alone.
Fixed-point realization (ice + steam) | 0.10 | Method allowance for the stirred slush ice bath and the pressure-corrected steam point. Dominated mainly by the practical steam setup and pressure-estimation method, not by the ice bath.

Calculation. Combined calibration standard uncertainty u_c ,cal=√((0.12^2 + 0.03^2 + 0.10^2 ))=0.159 °C , rounded to 0.16 C. Assigned calibration expanded uncertainty U_(cal) =k∙u_c ,cal with k=2=±0.32 °C , rounded to ±0.32 °C .

Meaning. When the logger is used as a calibrated instrument under conditions similar to the calibration setup, the indicated temperature is assigned a calibration uncertainty of approximately ±0.32 °C at k=2 .

# Assigned In-Use Allowance and Working Uncertainty

Purpose. This section separates real-world use effects from the calibration itself so the record shows both the calibration-only result and the more conservative working uncertainty used in service.

In-use component | Std. unc. (C) | Brief basis
Placement / coupling / stem-conduction allowance | 0.08 | Allowance for probe placement, thermal coupling, local gradients, and stem-conduction effects during normal use. This term is not part of the fixed-point calibration itself; it is added to represent practical field/lab use.

Calculation. Combined working standard uncertainty u_c ,work=√(0.159^2 + 0.08^2)=0.178 °C , rounded to 0.18 °C . Assigned working expanded uncertainty U_(work) =k ∙ u_c ,work with k=2=±0.36 °C , rounded to ±0.36 °C .

Meaning. This is the more conservative value to use for actual decisions, comparisons, and audit discussions when the instrument is being used outside the calibration setup.

# Traceability and Use Statement

This calibration is an internally controlled working calibration based on physical temperature reference points. The atmospheric pressure input for the steam point is derived from the adjacent airport METAR record and converted in firmware to estimated station pressure. This record supports internal verification and audit documentation for the single custom datalogger unit. It is not an accredited laboratory calibration certificate.

# Authorization

Technician | Robert Susmilch
Calibration Date | February 18, 2026
Next Calibration Due | 1 year from calibration date

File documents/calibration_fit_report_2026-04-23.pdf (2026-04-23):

# PT100 Calibration Fit Report

Input source: calibration_2026-04-22

## Summary

Item | Value
Input source | calibration_2026-04-22
Calibration equation | ax^2+bx+c
Fit domain | Resistance (ohms)
Model type | poly
Polynomial degree | 2
Calibration points used | 4
Model parameters | 3
Degrees of freedom | 1
Calibration method | Reference transfer from Fluke 51 II N1052
Effective last UTC | 2026-04-17T00:00:00Z
Due date | 2027-04-17T00:00:00Z

## Calibration Curve

Polynomial fit with calibration target points and model values at each point.

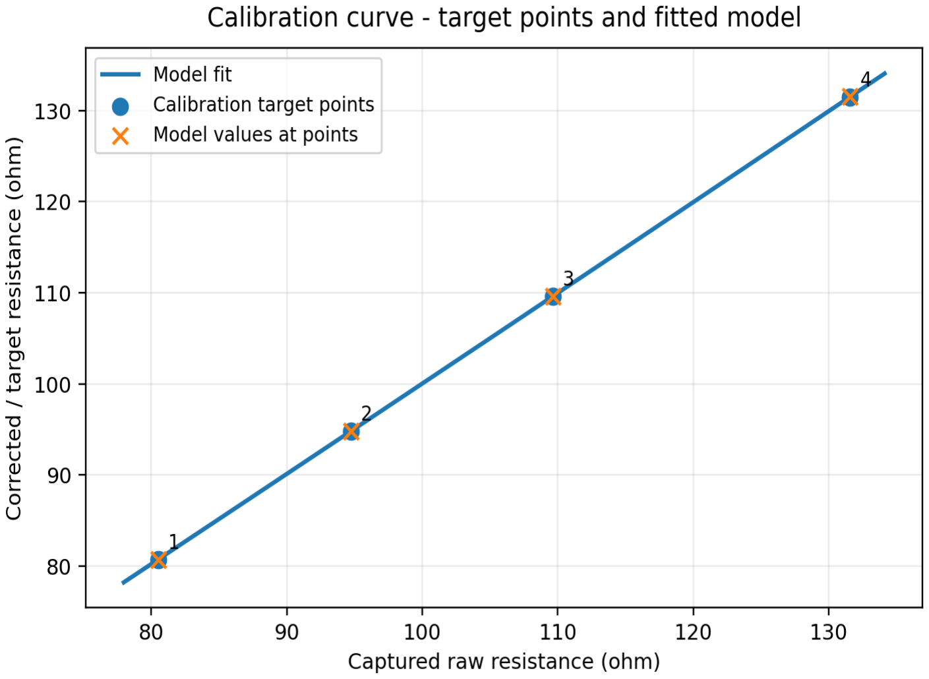
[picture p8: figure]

## Residuals

Model-fit and captured residuals plotted against reference temperature.


## Model Fit Statistics

Metric | Value
Mean absolute residual (ohms) | 0.007189709
Root mean square error (ohms) | 0.008283515
Maximum absolute residual (ohms) | 0.012259575
Mean absolute residual (C) | 0.018400459
Root mean square error (C) | 0.021190599
Maximum absolute residual (C) | 0.031243308
R^2 | 0.999999808
Adjusted R^2 | 0.999999424
Largest applied correction (ohms) | 0.215606214
Mean signed residual (ohms) | 3.40519205e-05
Residual standard deviation (ohms) | 0.008283445
Sum of squared error (ohm^2) | 0.000274466488
Mean signed residual (C) | 8.90917565e-05
Residual standard deviation (C) | 0.021190412
Sum of squared error (C^2) | 0.001796166

## Calibration Point Values

Pt | Target C | Target ohm | Captured C | Captured ohm | Model C | Model ohm
1 | -48.900 | 80.743 | -49.455 | 80.523 | -48.911 | 80.739
2 | -13.300 | 94.792 | -13.467 | 94.728 | -13.269 | 94.804
3 | 24.700 | 109.618 | 24.718 | 109.625 | 24.674 | 109.608
4 | 81.600 | 131.507 | 81.742 | 131.562 | 81.605 | 131.509

## Residuals and Applied Corrections

Pt | Model res C | Model res ohm | Capture res C | Capture res ohm | Applied correction (ohm)
1 | 0.011163 | 0.004431 | 0.555000 | 0.220000 | 0.215606
2 | -0.031243 | -0.012260 | 0.167000 | 0.064000 | 0.075894
3 | 0.025816 | 0.010016 | -0.018000 | -0.007000 | -0.016748
4 | -0.005379 | -0.002052 | -0.142000 | -0.055000 | -0.052752

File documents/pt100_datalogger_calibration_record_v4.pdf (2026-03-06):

# Temperature Datalogger Calibration Record

Internal calibration record for the single custom PT100 datalogger unit used in the test laboratory.

## Instrument Identification

Instrument: PT100 Temperature Datalogger (custom single unit) Controller: ESP32-S3
RTD Interface: MAX31865
Probe Model: Omega P-L-1/3-1/8-6-0-T-3
Location: Bemidji Test Laboratory
Atmospheric Pressure Source: KBJI METAR (Bemidji Regional Airport, adjacent to site)

## Measurement Configuration Snapshot

Item | Value
RTD Type | PT100
Wiring | 4-wire
Reference Resistor | 430 ohm
MAX31865 Filter | 60 Hz
MAX31865 Conversion Mode | PT100 table
Bias Settle Delay | 10 ms
Temperature Resolution | 0.03125 C nominal
Calibration Model | 2-point linear
Calibration Storage | ESP32 NVS

## Calibration Procedure

Calibration is performed using two physical reference points: a stirred ice-water slush bath assigned as 0.000 C and a pressure-corrected saturated steam point derived from local atmospheric pressure.

Ice Point Procedure
Distilled water and crushed ice are prepared as a true slurry/slush, not floating ice in bulk water. The probe is immersed approximately 5 to 6 inches into the slush in a 2 L beaker. The probe is gently moved/stirred in the slurry during stabilization to minimize local pockets and maintain equilibrium at the sensing element. This point is assigned a reference temperature of 0.000 C.

Steam Point Procedure

Distilled water is boiled vigorously in a covered beaker. The probe is placed several inches above the water surface within the steam space under the cover, without immersion in liquid water. The steam reference temperature is calculated in firmware from KBJI METAR pressure data by converting the reported altimeter setting to estimated station pressure and then calculating the saturation temperature of water at that pressure.

Model Application
The raw measured temperatures at the two reference points are used to calculate and store a linear 2-point calibration model in nonvolatile memory within the datalogger.

## METAR Pressure Record

Field | Record
METAR Station | KBJI - Bemidji Regional Airport

Calibration Date/Time

METAR Observation Time

Altimeter Setting (inHg)

Estimated Station Pressure

Calculated Steam Temperature (C)

Notes | Airport is adjacent to calibration site

## Calibration Data and Stored Calibration Points

Point | Raw Avg (C) | Reference (C) | Residual (C)
Ice Point | 0.471 | 0.000 | -0.471
Steam Point | 98.206 | 97.967 | -0.239
Coefficient Record | Value
Point 1 Raw | 0.471 C
Point 1 Actual | 0.000 C
Point 2 Raw | 98.206 C
Point 2 Actual | 97.967 C
Calibration Mode | linear

## Assigned Uncertainty

Uncertainty Component | Standard Uncertainty (C)
Probe class / interpolation allowance | 0.12
Electronics / conversion / quantization | 0.03
Calibration realization (ice + steam) | 0.10
General use / placement / coupling allowance | 0.08

Combined standard uncertainty: 0.173 C
Assigned expanded uncertainty (k = 2): +/-0.30 C over approximately 0 to 100 C.

## Traceability and Use Statement

This calibration is an internally controlled working calibration based on physical temperature reference points. The atmospheric pressure input for the steam point is derived from the adjacent airport METAR record and converted in firmware to estimated station pressure. This record supports internal verification and audit documentation for the single custom datalogger unit. It is not an accredited laboratory calibration certificate.

## Authorization

Technician

Calibration Date

Next Calibration Due | 1 year from calibration date

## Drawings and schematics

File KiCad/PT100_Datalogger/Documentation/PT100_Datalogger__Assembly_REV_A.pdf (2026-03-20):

J9 100nF C¹³ ESP32-S3-WROOM-1-N8R2 U1 | 100nF C⁷ 10uF
R9 ¹⁰⁰nF C¹ | LED

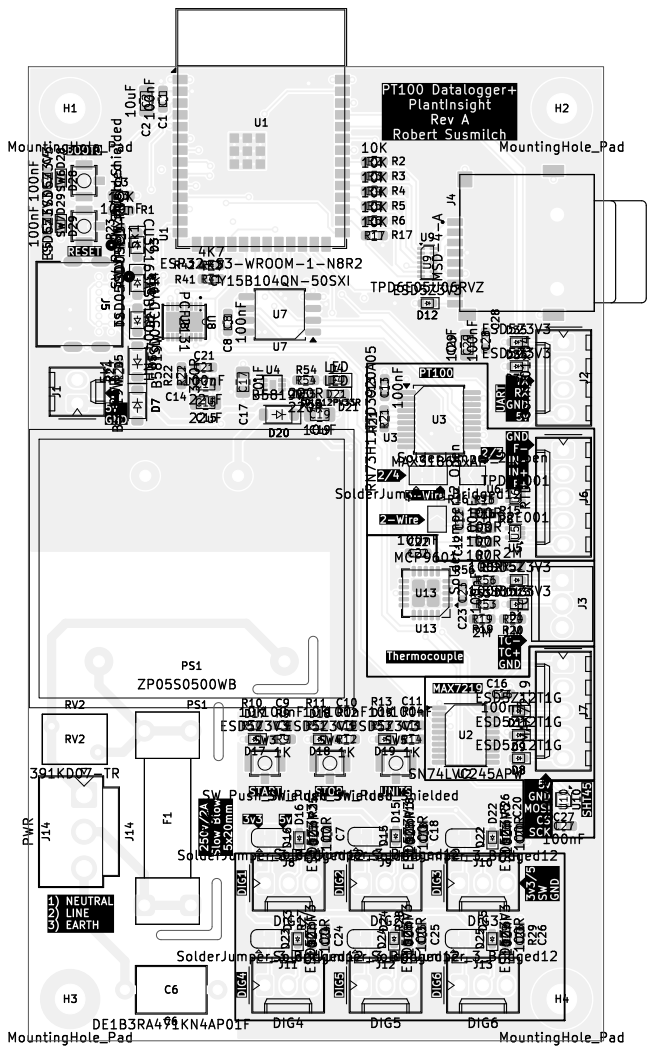
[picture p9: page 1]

Id: /1 Title: File: PT100_Datalogger.kicad_pcb Sheet: Black And White TOP

1 | 2 | 3 | 4 | 5

A

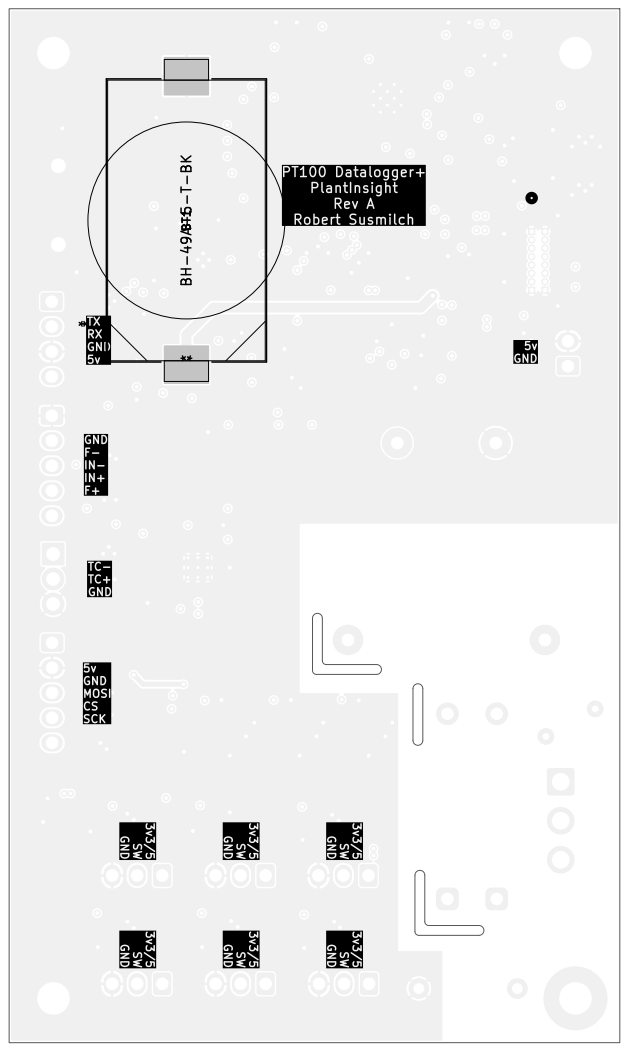
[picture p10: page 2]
D Date: KiCad; E.D.A. 9.0.8 Size: USLetter; Rev:; Id: /1 Title: File: PT100_Datalogger.kicad_pcb Sheet: Black; And; White; BOT Board2Pdf:; Black; BOT -; Page 2/8 BH⁻⁴⁹A⁻⁵⁻T⁻BK

J9 100nF C¹³ ESP32-S3-WROOM-1-N8R2 U1 | 100nF C⁷ 10uF
R9 ¹⁰⁰nF C¹ | LED

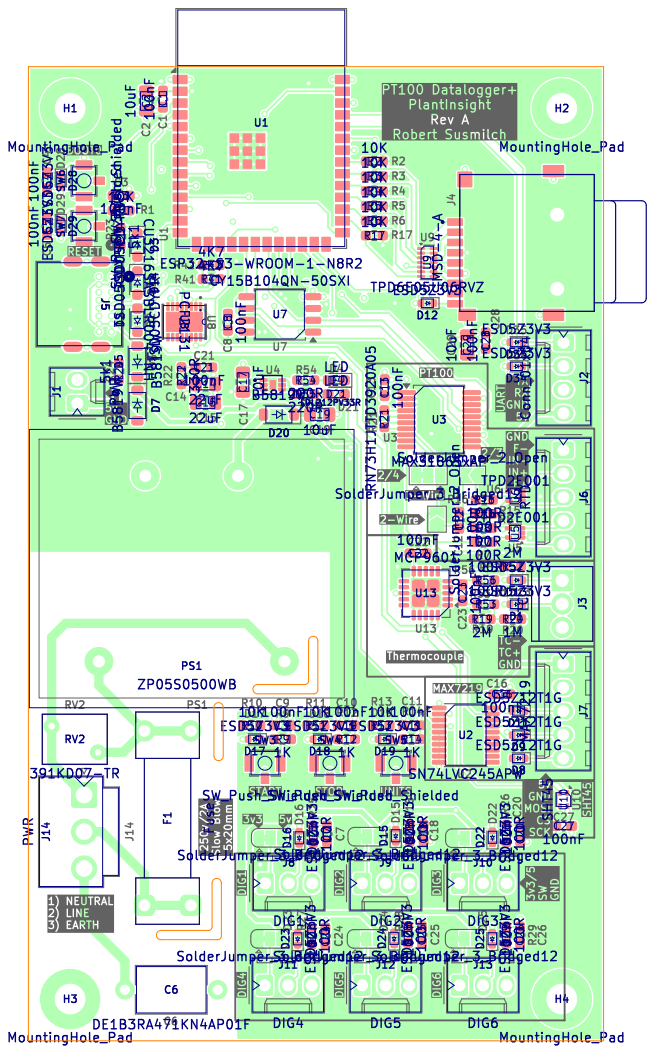
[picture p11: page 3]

Id: /1 Title: File: PT100_Datalogger.kicad_pcb Sheet: Colored TOP

A

A

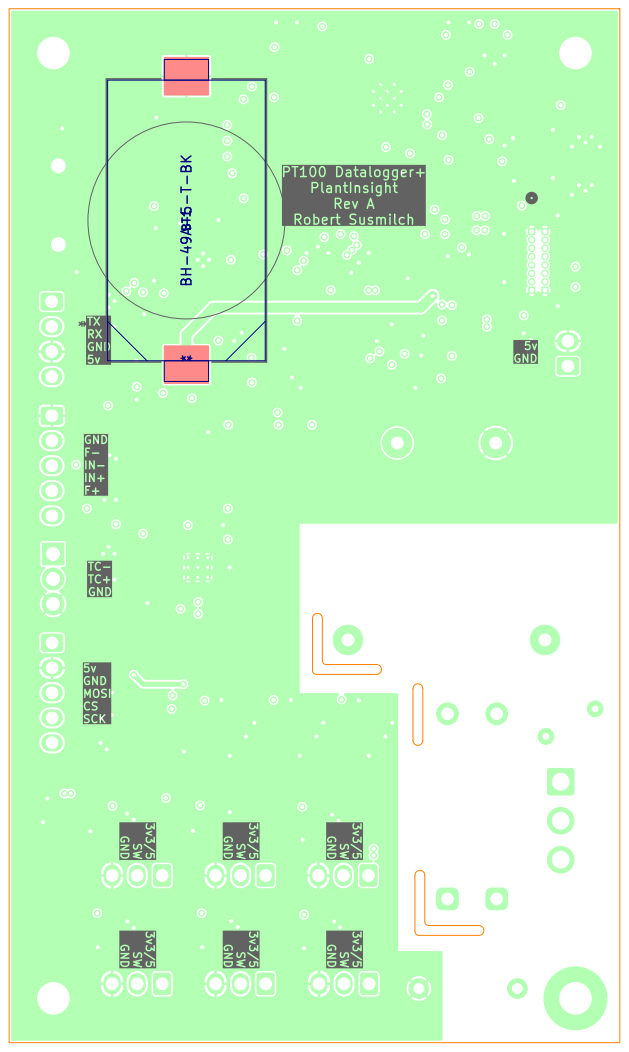
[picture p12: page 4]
D Date: KiCad; E.D.A. 9.0.8 Size: USLetter; Rev:; Id: /1 Title: File: PT100_Datalogger.kicad_pcb Sheet: Colored; BOT Board2Pdf:; Colored; BOT -; Page 4/8 BH⁻⁴⁹A⁻⁵⁻T⁻BK

# KEEP-OUT ZONE

A

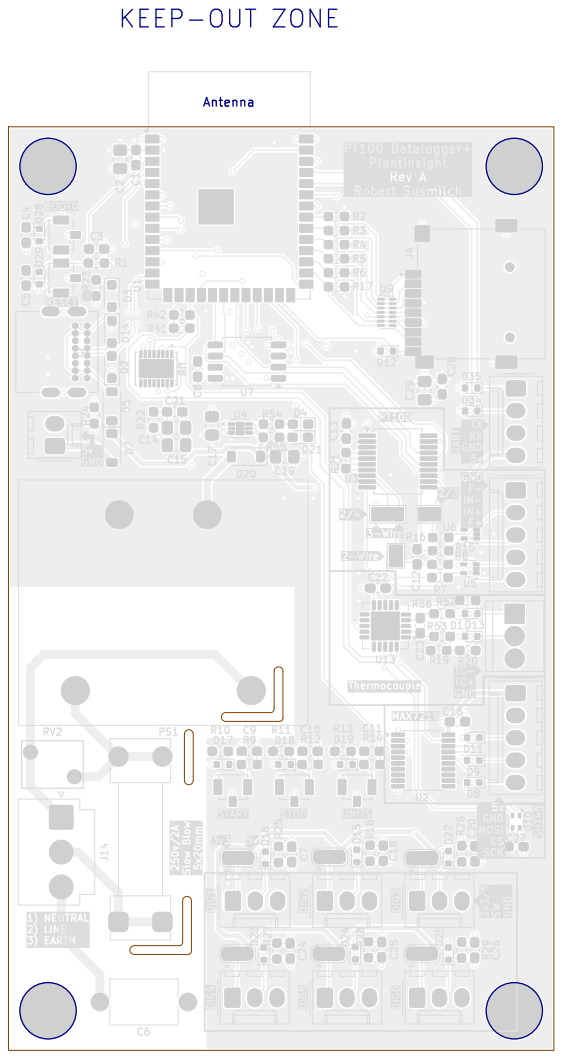
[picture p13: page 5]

A

A

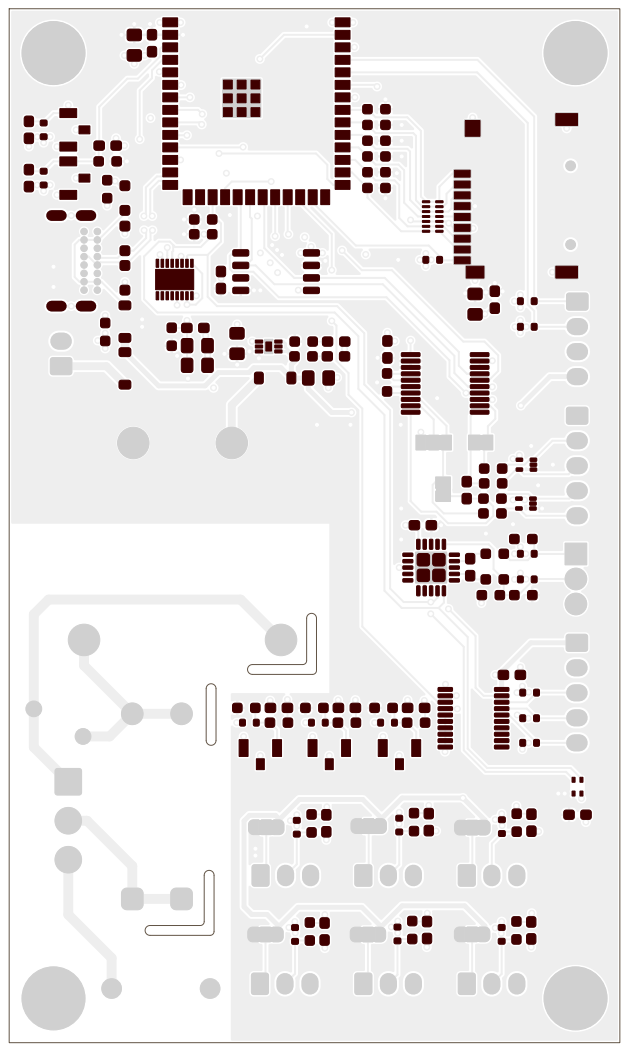
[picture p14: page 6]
D Date: KiCad; E.D.A. 9.0.8 Size: USLetter; Rev:; Id: /1 Title: File: PT100_Datalogger.kicad_pcb Sheet: Light Colors; PCB; Paste; TOP; Board2Pdf:; Light Colors; TOP -; Page 6/8

A

A

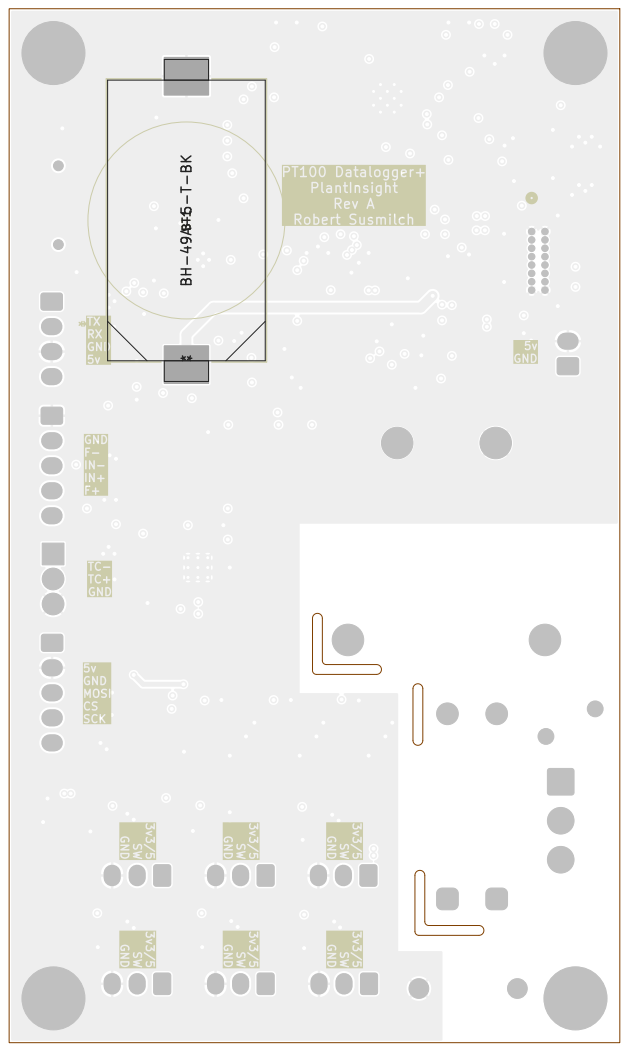
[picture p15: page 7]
D Date: KiCad; E.D.A. 9.0.8 Size: USLetter; Rev:; Id: /1 Title: File: PT100_Datalogger.kicad_pcb Sheet: Light Colors; Placement; BOT Board2Pdf:; Light Colors; BOT -; Page 7/8

J9 100nF C¹³ ESP32-S3-WROOM-1-N8R2 U1 | 100nF C⁷ 10uF
R9 ¹⁰⁰nF C¹ | LED

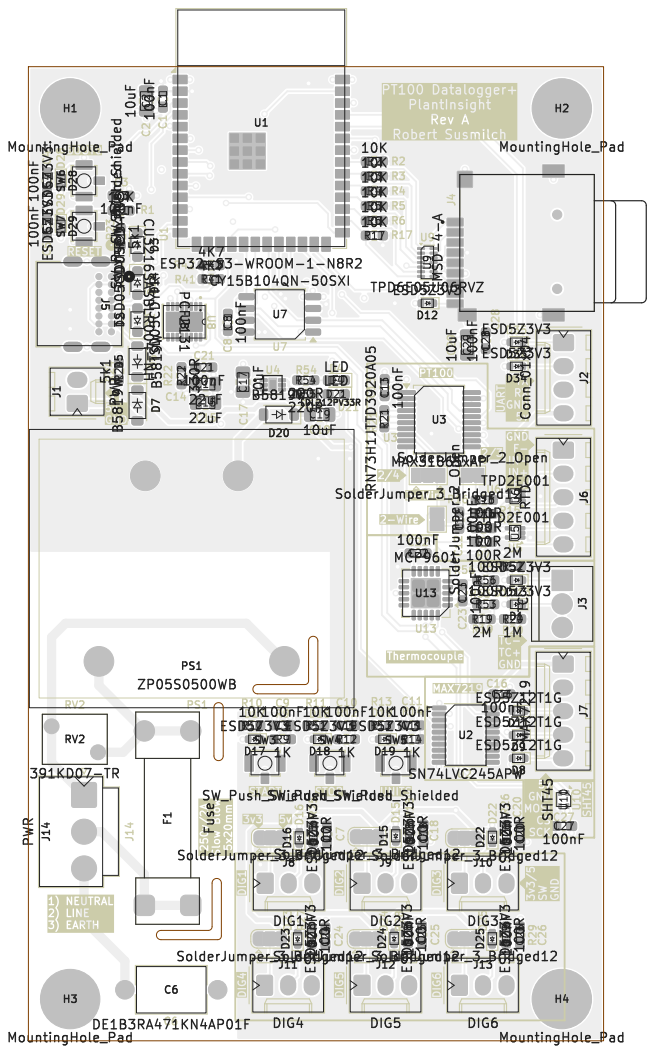
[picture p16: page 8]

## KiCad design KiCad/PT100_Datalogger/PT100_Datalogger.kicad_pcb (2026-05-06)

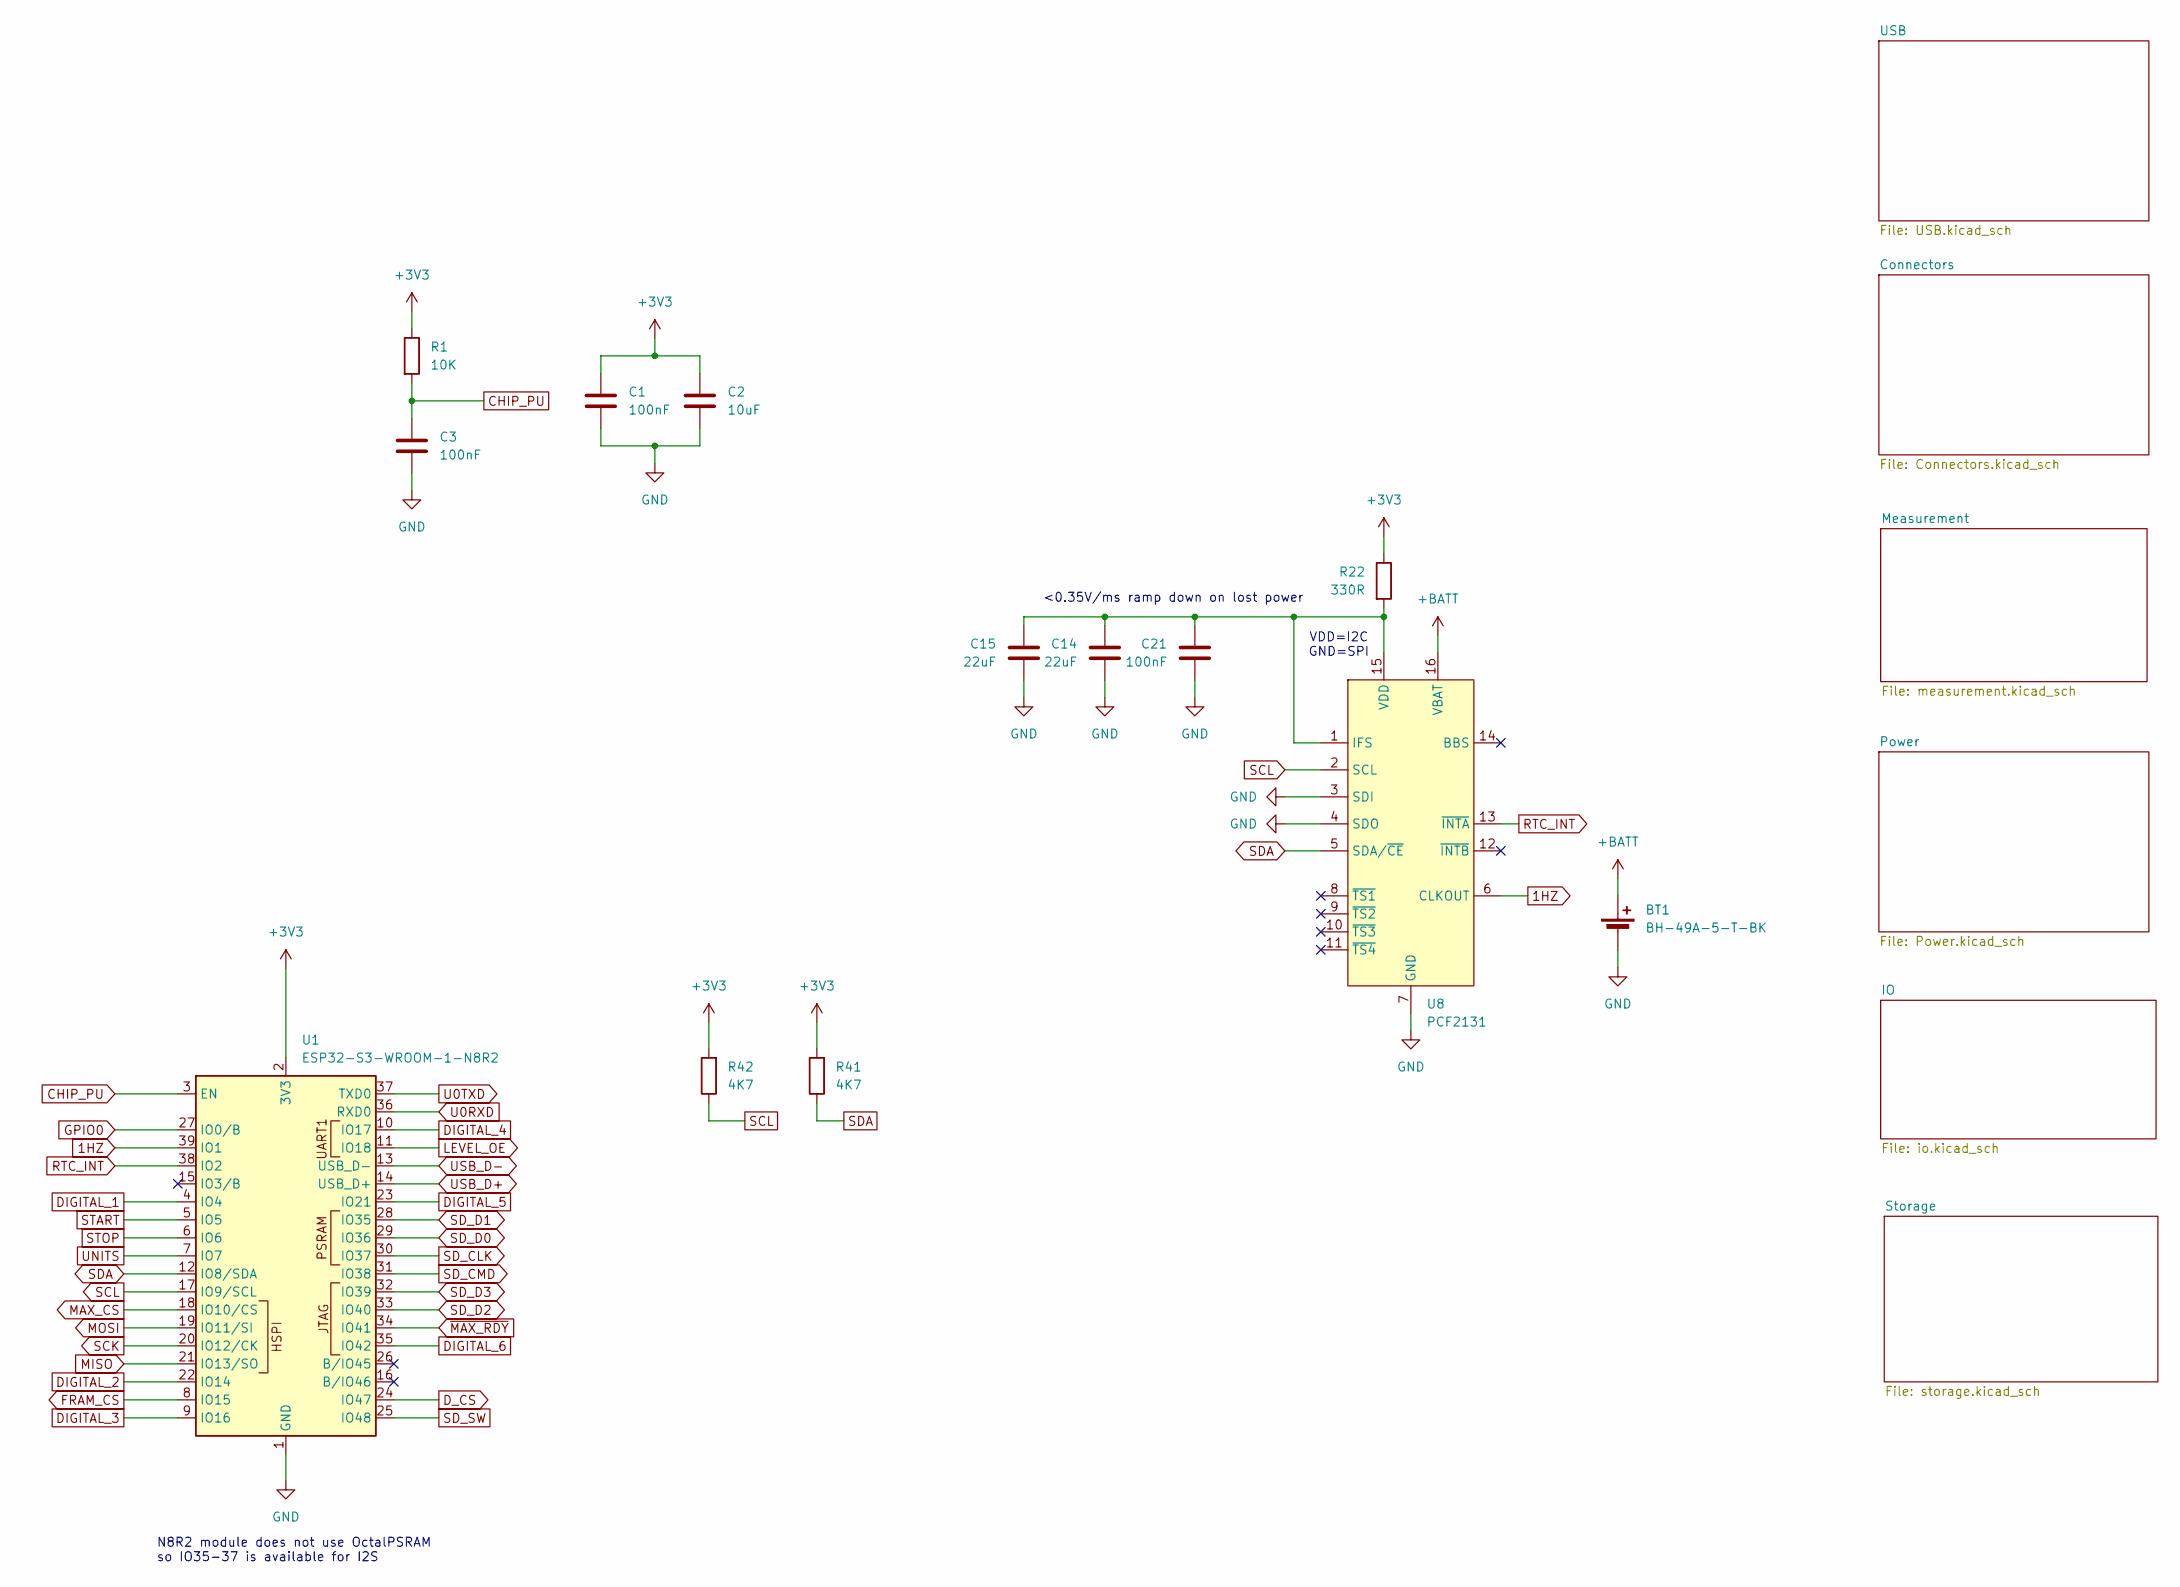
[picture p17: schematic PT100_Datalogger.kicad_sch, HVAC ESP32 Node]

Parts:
BT1: BH-49A-5-T-BK; BH-49A-5-T-BK_ADM
C1, C3, C21: 100nF; C_0603_1608Metric_Pad1.08x0.95mm_HandSolder
C2: 10uF; C_0805_2012Metric_Pad1.18x1.45mm_HandSolder
C14, C15: 22uF; C_0805_2012Metric_Pad1.18x1.45mm_HandSolder
R1: 10K; R_0603_1608Metric_Pad0.98x0.95mm_HandSolder
R22: 330R; R_0603_1608Metric_Pad0.98x0.95mm_HandSolder
R41, R42: 4K7; R_0603_1608Metric_Pad0.98x0.95mm_HandSolder
U1: ESP32-S3-WROOM-1-N8R2; ESP32-S3-WROOM-1
U8: PCF2131; 16-HLSON

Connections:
1HZ: U1.39 (IO1), U8.6 (CLKOUT)
+3V3: C1.1, C2.1, R1.1, R22.1, R41.2, R42.2, U1.2 (3V3); also elsewhere on the board
+BATT: BT1.1 (+), U8.16 (VBAT)
CHIP_PU: C3.1, R1.2, U1.3 (EN); also elsewhere on the board
DIGITAL_1: U1.4 (IO4); also elsewhere on the board
DIGITAL_2: U1.22 (IO14); also elsewhere on the board
DIGITAL_3: U1.9 (IO16); also elsewhere on the board
DIGITAL_4: U1.10 (IO17); also elsewhere on the board
DIGITAL_5: U1.23 (IO21); also elsewhere on the board
DIGITAL_6: U1.35 (IO42); also elsewhere on the board
D_CS: U1.24 (IO47); also elsewhere on the board
FRAM_CS: U1.8 (IO15); also elsewhere on the board
GND: BT1.2 (-), C1.2, C2.2, C3.2, C14.2, C15.2, C21.2, U1.1 (GND), U1.40 (GND), U1.41 (GND), U8.3 (SDI), U8.4 (SDO), U8.7 (GND); also elsewhere on the board
GPIO0: U1.27 (IO0/B); also elsewhere on the board
LEVEL_OE: U1.11 (IO18); also elsewhere on the board
MAX_CS: U1.18 (IO10/CS); also elsewhere on the board
MISO: U1.21 (IO13/SO); also elsewhere on the board
MOSI: U1.19 (IO11/SI); also elsewhere on the board
unnamed: C14.1, C15.1, C21.1, R22.2, U8.1 (IFS), U8.15 (VDD)
RTC_INT: U1.38 (IO2), U8.13 (~INTA)
SCK: U1.20 (IO12/CK); also elsewhere on the board
SCL: R42.1, U1.17 (IO9/SCL), U8.2 (SCL); also elsewhere on the board
SDA: R41.1, U1.12 (IO8/SDA), U8.5 (SDA/~CE); also elsewhere on the board
SD_CLK: U1.30 (IO37); also elsewhere on the board
SD_CMD: U1.31 (IO38); also elsewhere on the board
SD_D0: U1.29 (IO36); also elsewhere on the board
SD_D1: U1.28 (IO35); also elsewhere on the board
SD_D2: U1.33 (IO40); also elsewhere on the board
SD_D3: U1.32 (IO39); also elsewhere on the board
SD_SW: U1.25 (IO48); also elsewhere on the board
START: U1.5 (IO5); also elsewhere on the board
STOP: U1.6 (IO6); also elsewhere on the board
U0RXD: U1.36 (RXD0); also elsewhere on the board
U0TXD: U1.37 (TXD0); also elsewhere on the board
UNITS: U1.7 (IO7); also elsewhere on the board
USB_D+: U1.14 (USB_D+); also elsewhere on the board
USB_D-: U1.13 (USB_D-); also elsewhere on the board
~MAX_RDY: U1.34 (IO41); also elsewhere on the board

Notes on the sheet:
<0.35V/ms ramp down on lost power
VDD=I2C GND=SPI
N8R2 module does not use OctalPSRAM so IO35-37 is available for I2S

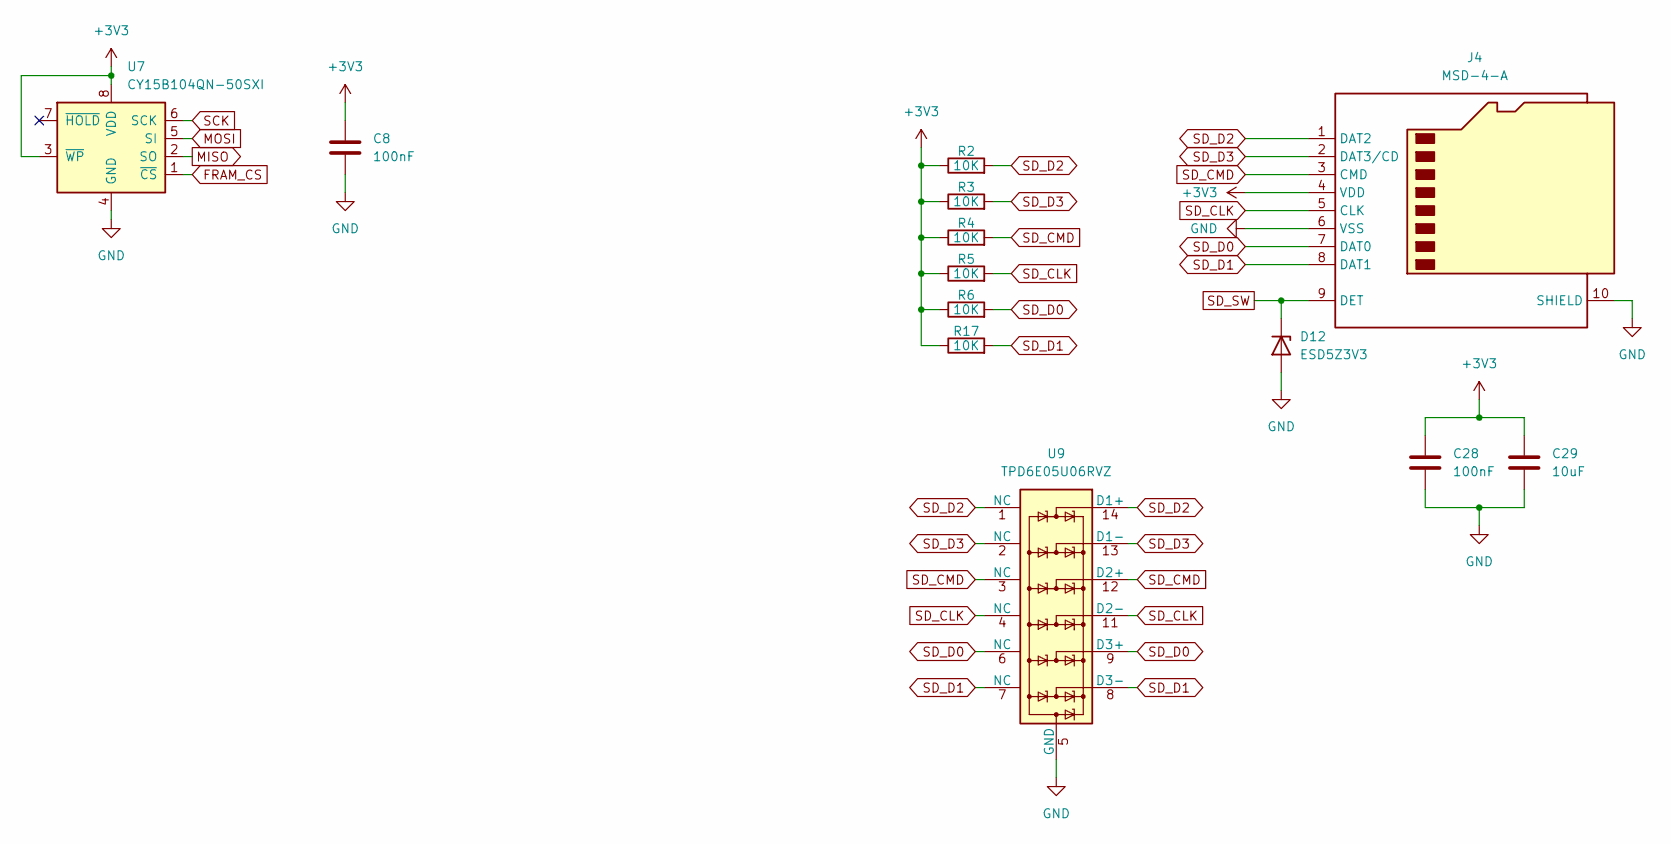
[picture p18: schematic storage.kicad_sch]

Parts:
C8, C28: 100nF; C_0603_1608Metric_Pad1.08x0.95mm_HandSolder
C29: 10uF; C_0805_2012Metric_Pad1.18x1.45mm_HandSolder
D12: ESD5Z3V3; D_SOD-523
J4: MSD-4-A; CUI_MSD-4-A
R2, R3, R4, R5, R6, R17: 10K; R_0603_1608Metric_Pad0.98x0.95mm_HandSolder
U7: CY15B104QN-50SXI; SOIC-8_5.3x5.3mm_P1.27mm
U9: TPD6E05U06RVZ; Texas_R-PUSON-N14

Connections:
+3V3: C8.1, C28.1, C29.1, J4.4 (VDD), R2.1, R3.1, R4.1, R5.1, R6.1, R17.1, U7.3 (~WP), U7.8 (VDD); also elsewhere on the board
FRAM_CS: U7.1 (~CS); also elsewhere on the board
GND: C8.2, C28.2, C29.2, D12.2 (A), J4.6 (VSS), J4.10 (SHIELD), U7.4 (GND), U9.5 (GND), U9.10 (GND); also elsewhere on the board
MISO: U7.2 (SO); also elsewhere on the board
MOSI: U7.5 (SI); also elsewhere on the board
SCK: U7.6 (SCK); also elsewhere on the board
SD_CLK: J4.5 (CLK), R5.2, U9.4 (NC), U9.11 (D2-); also elsewhere on the board
SD_CMD: J4.3 (CMD), R4.2, U9.3 (NC), U9.12 (D2+); also elsewhere on the board
SD_D0: J4.7 (DAT0), R6.2, U9.6 (NC), U9.9 (D3+); also elsewhere on the board
SD_D1: J4.8 (DAT1), R17.2, U9.7 (NC), U9.8 (D3-); also elsewhere on the board
SD_D2: J4.1 (DAT2), R2.2, U9.1 (NC), U9.14 (D1+); also elsewhere on the board
SD_D3: J4.2 (DAT3/CD), R3.2, U9.2 (NC), U9.13 (D1-); also elsewhere on the board
SD_SW: D12.1 (K), J4.9 (DET); also elsewhere on the board

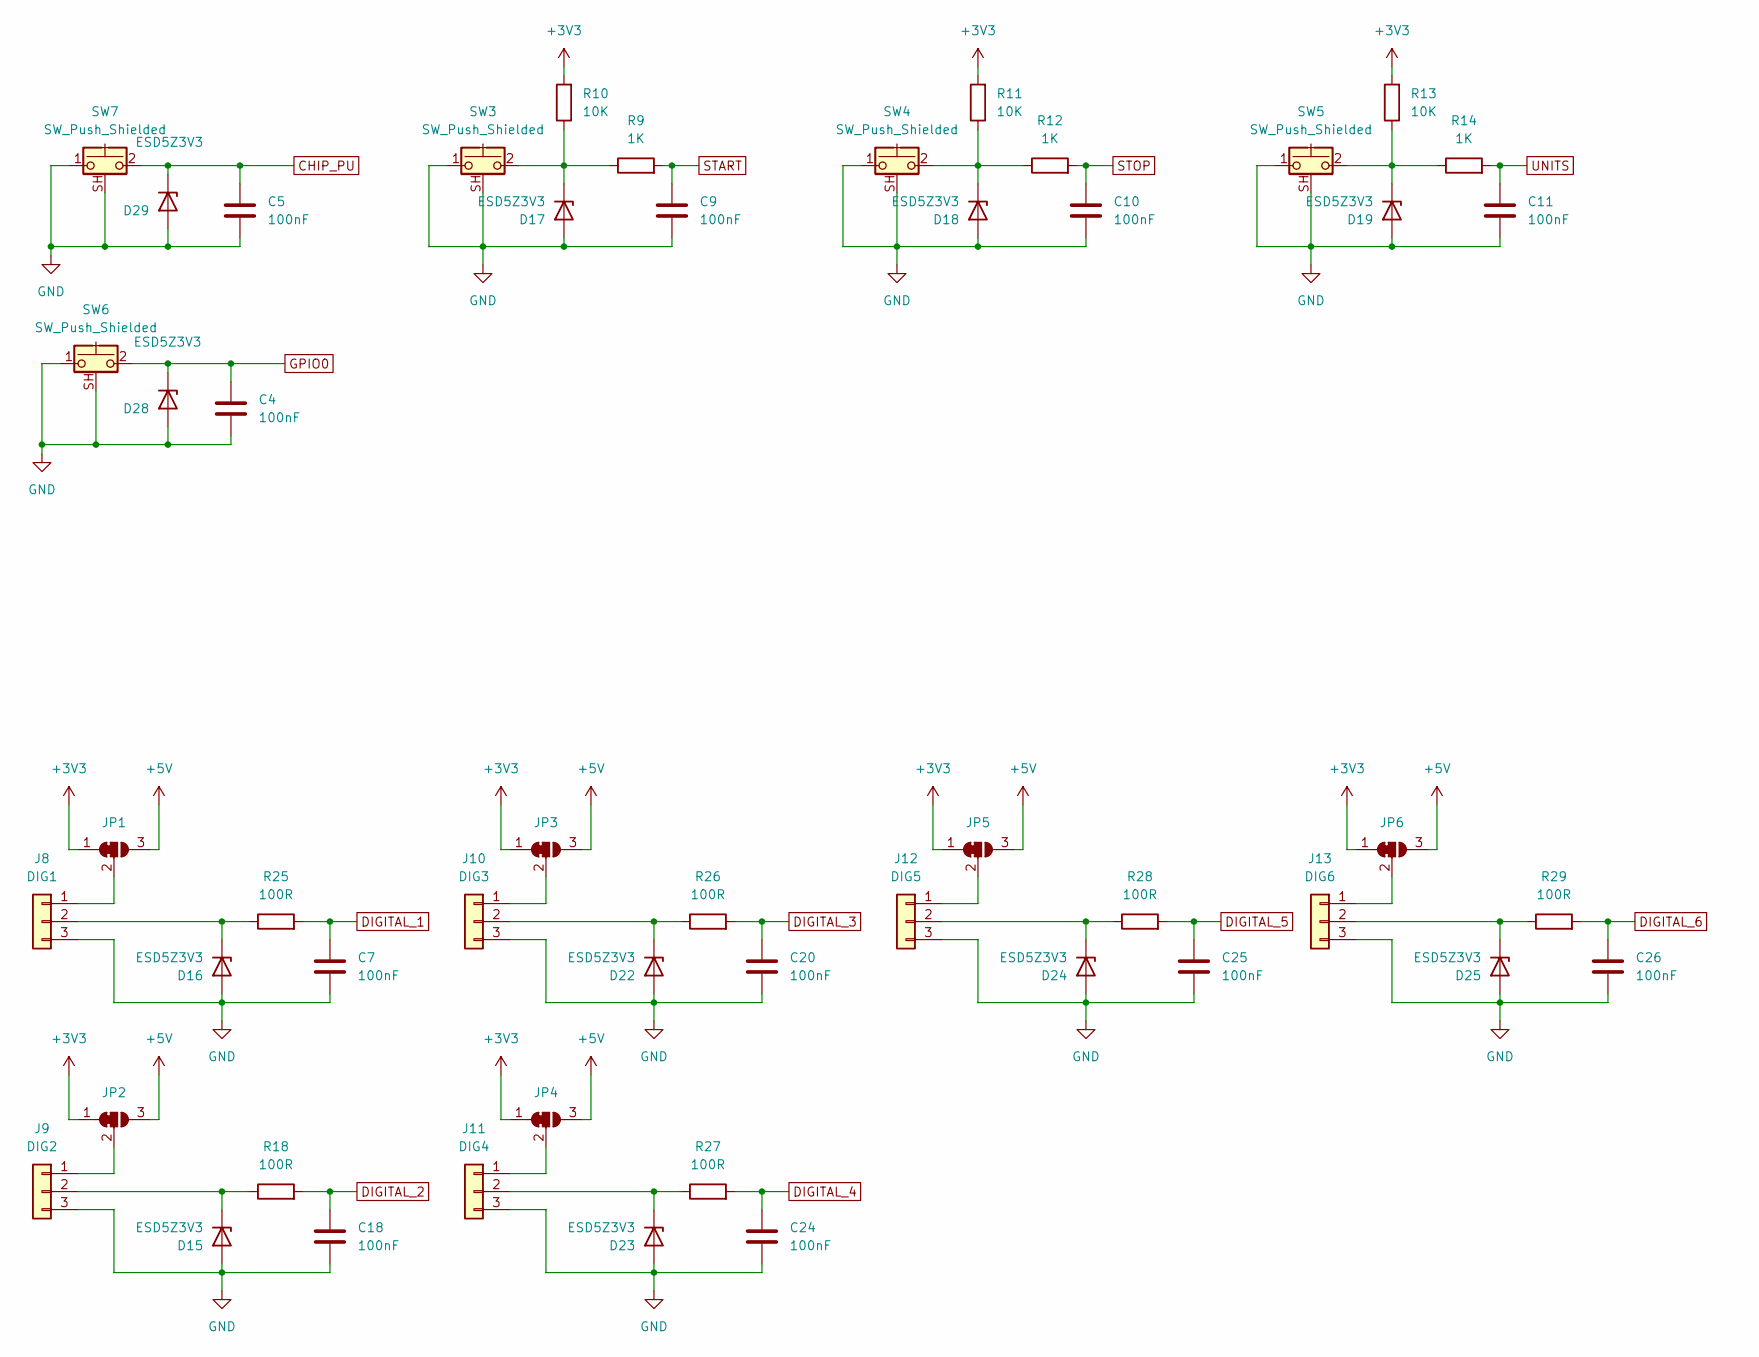
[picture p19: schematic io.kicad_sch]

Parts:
C4, C5, C7, C9, C10, C11, C18, C20, C24, C25, C26: 100nF; C_0603_1608Metric_Pad1.08x0.95mm_HandSolder
D15, D16, D17, D18, D19, D22, D23, D24, D25, D28, D29: ESD5Z3V3; D_SOD-523
J8: DIG1; Molex_KK-254_AE-6410-03A_1x03_P2.54mm_Vertical
J9: DIG2; Molex_KK-254_AE-6410-03A_1x03_P2.54mm_Vertical
J10: DIG3; Molex_KK-254_AE-6410-03A_1x03_P2.54mm_Vertical
J11: DIG4; Molex_KK-254_AE-6410-03A_1x03_P2.54mm_Vertical
J12: DIG5; Molex_KK-254_AE-6410-03A_1x03_P2.54mm_Vertical
J13: DIG6; Molex_KK-254_AE-6410-03A_1x03_P2.54mm_Vertical
JP1, JP2, JP3, JP4, JP5, JP6: SolderJumper_3_Bridged12; SolderJumper-3_P1.3mm_Bridged12_RoundedPad1.0x1.5mm
R9, R12, R14: 1K; R_0603_1608Metric_Pad0.98x0.95mm_HandSolder
R10, R11, R13: 10K; R_0603_1608Metric_Pad0.98x0.95mm_HandSolder
R18, R25, R26, R27, R28, R29: 100R; R_0603_1608Metric_Pad0.98x0.95mm_HandSolder
SW3, SW4, SW5, SW6, SW7: SW_Push_Shielded; SW_SPST_B3U-1100P

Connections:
+3V3: JP1.1 (A), JP2.1 (A), JP3.1 (A), JP4.1 (A), JP5.1 (A), JP6.1 (A), R10.2, R11.2, R13.2; also elsewhere on the board
+5V: JP1.3 (B), JP2.3 (B), JP3.3 (B), JP4.3 (B), JP5.3 (B), JP6.3 (B); also elsewhere on the board
CHIP_PU: C5.1, D29.1 (K), SW7.2; also elsewhere on the board
DIGITAL_1: C7.1, R25.2; also elsewhere on the board
DIGITAL_2: C18.1, R18.2; also elsewhere on the board
DIGITAL_3: C20.1, R26.2; also elsewhere on the board
DIGITAL_4: C24.1, R27.2; also elsewhere on the board
DIGITAL_5: C25.1, R28.2; also elsewhere on the board
DIGITAL_6: C26.1, R29.2; also elsewhere on the board
GND: C4.2, C5.2, C7.2, C9.2, C10.2, C11.2, C18.2, C20.2, C24.2, C25.2, C26.2, D15.2 (A), D16.2 (A), D17.2 (A), D18.2 (A), D19.2 (A), D22.2 (A), D23.2 (A), D24.2 (A), D25.2 (A), D28.2 (A), D29.2 (A), J8.3, J9.3, J10.3, J11.3, J12.3, J13.3, SW3.1, SW3.SH (B), SW4.1, SW4.SH (B), SW5.1, SW5.SH (B), SW6.1, SW6.SH (B), SW7.1, SW7.SH (B); also elsewhere on the board
GPIO0: C4.1, D28.1 (K), SW6.2; also elsewhere on the board
unnamed: D15.1 (K), J9.2, R18.1
unnamed: D16.1 (K), J8.2, R25.1
unnamed: D17.1 (K), R9.1, R10.1, SW3.2
unnamed: D18.1 (K), R11.1, R12.1, SW4.2
unnamed: D19.1 (K), R13.1, R14.1, SW5.2
unnamed: D22.1 (K), J10.2, R26.1
unnamed: D23.1 (K), J11.2, R27.1
unnamed: D24.1 (K), J12.2, R28.1
unnamed: D25.1 (K), J13.2, R29.1
unnamed: J8.1, JP1.2 (C)
unnamed: J9.1, JP2.2 (C)
unnamed: J10.1, JP3.2 (C)
unnamed: J11.1, JP4.2 (C)
unnamed: J12.1, JP5.2 (C)
unnamed: J13.1, JP6.2 (C)
START: C9.1, R9.2; also elsewhere on the board
STOP: C10.1, R12.2; also elsewhere on the board
UNITS: C11.1, R14.2; also elsewhere on the board

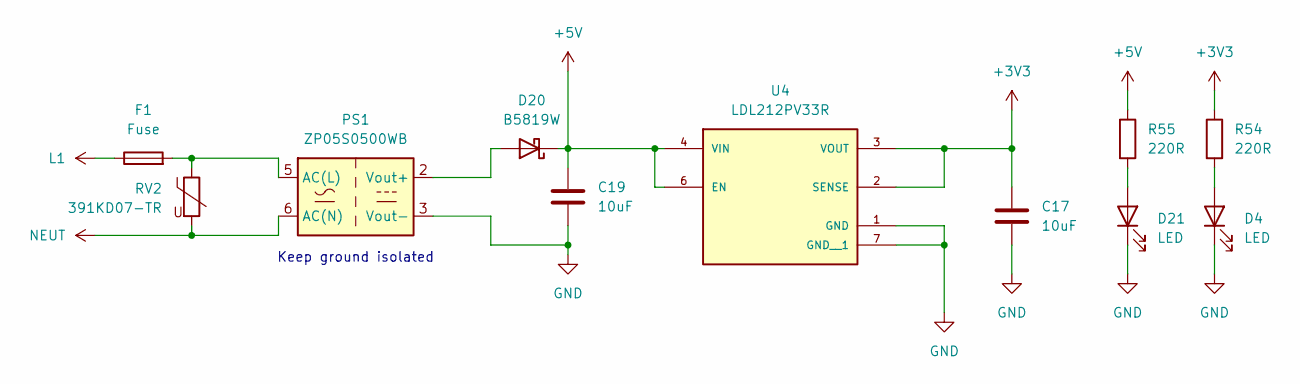
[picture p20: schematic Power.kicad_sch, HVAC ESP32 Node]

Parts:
C17, C19: 10uF; C_0805_2012Metric_Pad1.18x1.45mm_HandSolder
D4, D21: LED; LED_0603_1608Metric_Pad1.05x0.95mm_HandSolder
D20: B5819W; D_SOD-123
F1: Fuse; Fuseholder_Clip-5x20mm_Littelfuse_111_Lateral_P18.80x5.00mm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
PS1: ZP05S0500WB
R54, R55: 220R; R_0603_1608Metric_Pad0.98x0.95mm_HandSolder
RV2: 391KD07-TR; RV_Disc_D7mm_W5.4mm_P5mm
U4: LDL212PV33R; SON50P200X200X80-7N; PARTREV 5

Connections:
+3V3: C17.1, R54.1, U4.2 (SENSE), U4.3 (VOUT); also elsewhere on the board
+5V: C19.1, D20.1 (K), R55.1, U4.4 (VIN), U4.6 (EN); also elsewhere on the board
GND: C17.2, C19.2, D4.1 (K), D21.1 (K), PS1.3 (Vout-), U4.1 (GND), U4.7 (GND__1); also elsewhere on the board
L1: F1.1; also elsewhere on the board
NEUT: PS1.6 (AC(N)), RV2.2; also elsewhere on the board
unnamed: D4.2 (A), R54.2
unnamed: D20.2 (A), PS1.2 (Vout+)
unnamed: D21.2 (A), R55.2
unnamed: F1.2, PS1.5 (AC(L)), RV2.1

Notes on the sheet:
Keep ground isolated

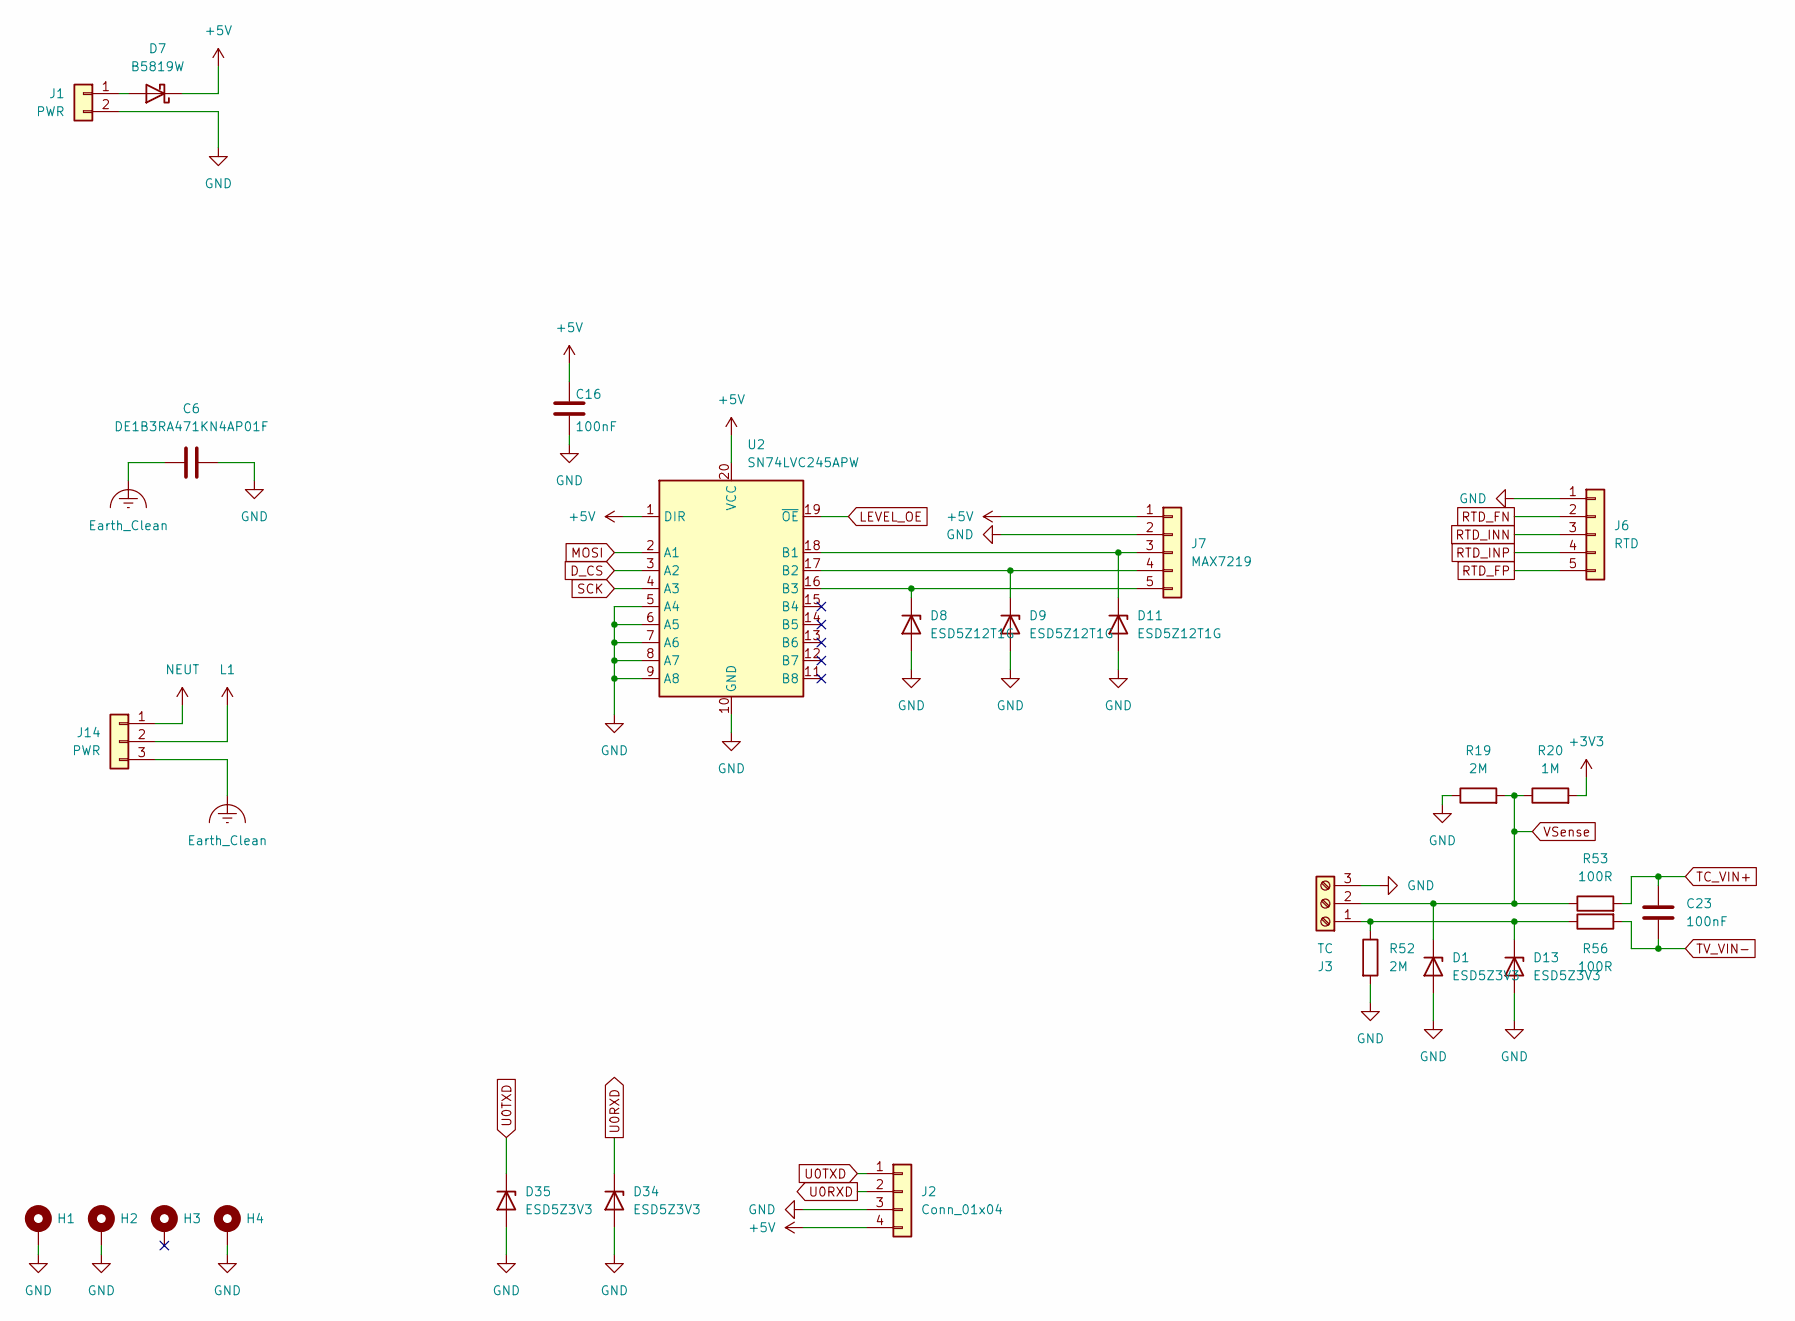
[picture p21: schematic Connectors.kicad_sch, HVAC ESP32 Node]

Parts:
C6: DE1B3RA471KN4AP01F; C_Disc_D7.5mm_W5.0mm_P10.00mm
C16, C23: 100nF; C_0603_1608Metric_Pad1.08x0.95mm_HandSolder
D1, D13, D34, D35: ESD5Z3V3; D_SOD-523
D7: B5819W; D_SOD-123
D8, D9, D11: ESD5Z12T1G; D_SOD-523
H1, H2, H3, H4: MountingHole_Pad; MountingHole_3.2mm_M3_Pad
J1: PWR; Molex_KK-254_AE-6410-02A_1x02_P2.54mm_Vertical
J2: Conn_01x04; Molex_KK-254_AE-6410-04A_1x04_P2.54mm_Vertical
J3: TC; TerminalBlock_Onshore-3_P2.54mm
J6: RTD; Molex_KK-254_AE-6410-05A_1x05_P2.54mm_Vertical
J7: MAX7219; Molex_KK-254_AE-6410-05A_1x05_P2.54mm_Vertical
J14: PWR; JST_VH_B3P-VH_1x03_P3.96mm_Vertical
R19, R52: 2M; R_0603_1608Metric_Pad0.98x0.95mm_HandSolder
R20: 1M; R_0603_1608Metric_Pad0.98x0.95mm_HandSolder
R53, R56: 100R; R_0603_1608Metric_Pad0.98x0.95mm_HandSolder
U2: SN74LVC245APW; TSSOP-20_4.4x6.5mm_P0.65mm

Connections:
+3V3: R20.2; also elsewhere on the board
+5V: C16.1, D7.1 (K), J2.4, J7.1, U2.1 (DIR), U2.20 (VCC); also elsewhere on the board
D_CS: U2.3 (A2); also elsewhere on the board
Earth_Clean: C6.1, J14.3
GND: C6.2, C16.2, D1.2 (A), D8.2 (A), D9.2 (A), D11.2 (A), D13.2 (A), D34.2 (A), D35.2 (A), H1.1, H2.1, H4.1, J1.2, J2.3, J3.3, J6.1, J7.2, R19.1, R52.2, U2.5 (A4), U2.6 (A5), U2.7 (A6), U2.8 (A7), U2.9 (A8), U2.10 (GND); also elsewhere on the board
L1: J14.2; also elsewhere on the board
LEVEL_OE: U2.19 (~OE); also elsewhere on the board
MOSI: U2.2 (A1); also elsewhere on the board
NEUT: J14.1; also elsewhere on the board
unnamed: D7.2 (A), J1.1
unnamed: D8.1 (K), J7.5, U2.16 (B3)
unnamed: D9.1 (K), J7.4, U2.17 (B2)
unnamed: D11.1 (K), J7.3, U2.18 (B1)
unnamed: D13.1 (K), J3.1, R52.1, R56.1
RTD_FN: J6.2; also elsewhere on the board
RTD_FP: J6.5; also elsewhere on the board
RTD_INN: J6.3; also elsewhere on the board
RTD_INP: J6.4; also elsewhere on the board
SCK: U2.4 (A3); also elsewhere on the board
TC_VIN+: C23.1, R53.2; also elsewhere on the board
TV_VIN-: C23.2, R56.2; also elsewhere on the board
U0RXD: D34.1 (K), J2.2; also elsewhere on the board
U0TXD: D35.1 (K), J2.1; also elsewhere on the board
VSense: D1.1 (K), J3.2, R19.2, R20.1, R53.1; also elsewhere on the board

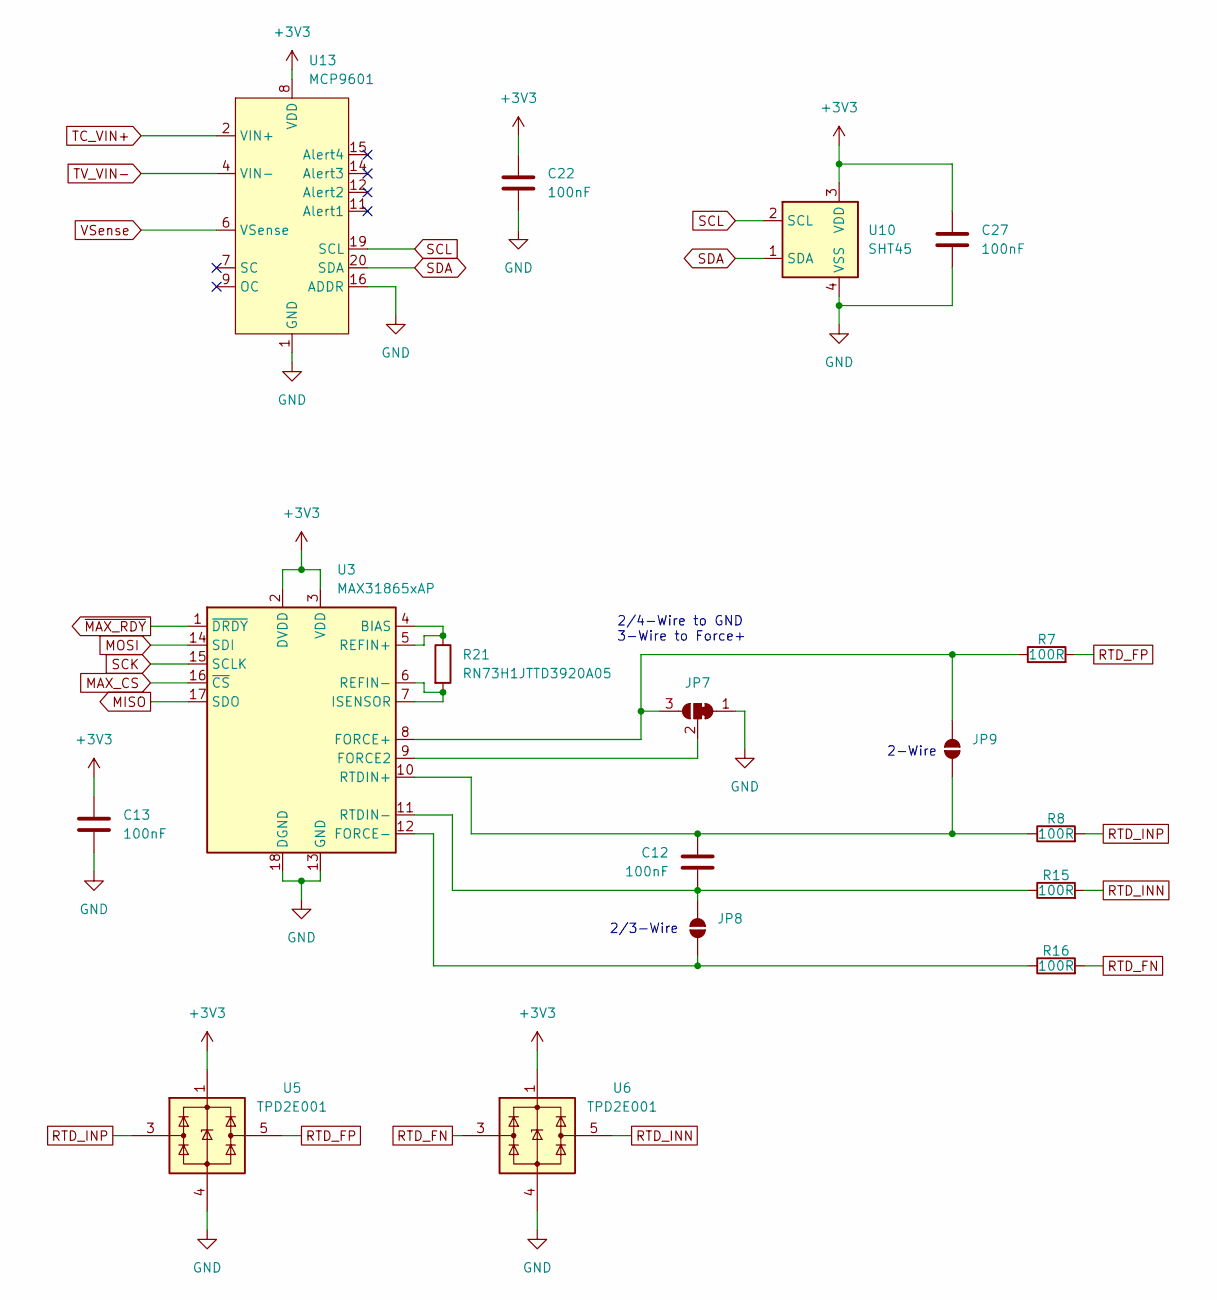
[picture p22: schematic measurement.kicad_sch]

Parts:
C12, C13, C22, C27: 100nF; C_0603_1608Metric_Pad1.08x0.95mm_HandSolder
JP7: SolderJumper_3_Bridged12; SolderJumper-3_P1.3mm_Bridged12_Pad1.0x1.5mm
JP8, JP9: SolderJumper_2_Open; SolderJumper-2_P1.3mm_Open_TrianglePad1.0x1.5mm
R7, R8, R15, R16: 100R; R_0603_1608Metric_Pad0.98x0.95mm_HandSolder
R21: RN73H1JTTD3920A05; R_0603_1608Metric_Pad0.98x0.95mm_HandSolder
U3: MAX31865xAP; SSOP-20_5.3x7.2mm_P0.65mm
U5, U6: TPD2E001; SOT-553
U10: SHT45; Sensirion_DFN-4_1.5x1.5mm_P0.8mm_SHT4x_NoCentralPad
U13: MCP9601; Texas_RGW0020A_VQFN-20-1EP_5x5mm_P0.65mm_EP3.15x3.15mm_Ther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

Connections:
+3V3: C13.1, C22.1, C27.1, U3.2 (DVDD), U3.3 (VDD), U5.1, U6.1, U10.3 (VDD), U13.8 (VDD); also elsewhere on the board
GND: C13.2, C22.2, C27.2, JP7.1 (A), U3.13 (GND), U3.18 (DGND), U3.19 (GND), U5.4, U6.4, U10.4 (VSS), U13.1 (GND), U13.3 (GND), U13.5 (GND), U13.10 (GND), U13.13 (GND), U13.16 (ADDR), U13.17 (GND), U13.18 (GND), U13.21 (EP); also elsewhere on the board
MAX_CS: U3.16 (~CS); also elsewhere on the board
MISO: U3.17 (SDO); also elsewhere on the board
MOSI: U3.14 (SDI); also elsewhere on the board
unnamed: JP7.3 (B), JP9.2 (B), R7.1, U3.8 (FORCE+)
unnamed: JP7.2 (C), U3.9 (FORCE2)
unnamed: JP8.1 (A), R16.1, U3.12 (FORCE-)
unnamed: C12.2, JP8.2 (B), R15.1, U3.11 (RTDIN-)
unnamed: C12.1, JP9.1 (A), R8.1, U3.10 (RTDIN+)
unnamed: R21.1, U3.4 (BIAS), U3.5 (REFIN+)
unnamed: R21.2, U3.6 (REFIN-), U3.7 (ISENSOR)
RTD_FN: R16.2, U6.3; also elsewhere on the board
RTD_FP: R7.2, U5.5; also elsewhere on the board
RTD_INN: R15.2, U6.5; also elsewhere on the board
RTD_INP: R8.2, U5.3; also elsewhere on the board
SCK: U3.15 (SCLK); also elsewhere on the board
SCL: U10.2 (SCL), U13.19 (SCL); also elsewhere on the board
SDA: U10.1 (SDA), U13.20 (SDA); also elsewhere on the board
TC_VIN+: U13.2 (VIN+); also elsewhere on the board
TV_VIN-: U13.4 (VIN-); also elsewhere on the board
VSense: U13.6 (VSense); also elsewhere on the board
~MAX_RDY: U3.1 (~DRDY); also elsewhere on the board

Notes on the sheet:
2/3-Wire
2/4-Wire to GND 3-Wire to Force+
2-Wire

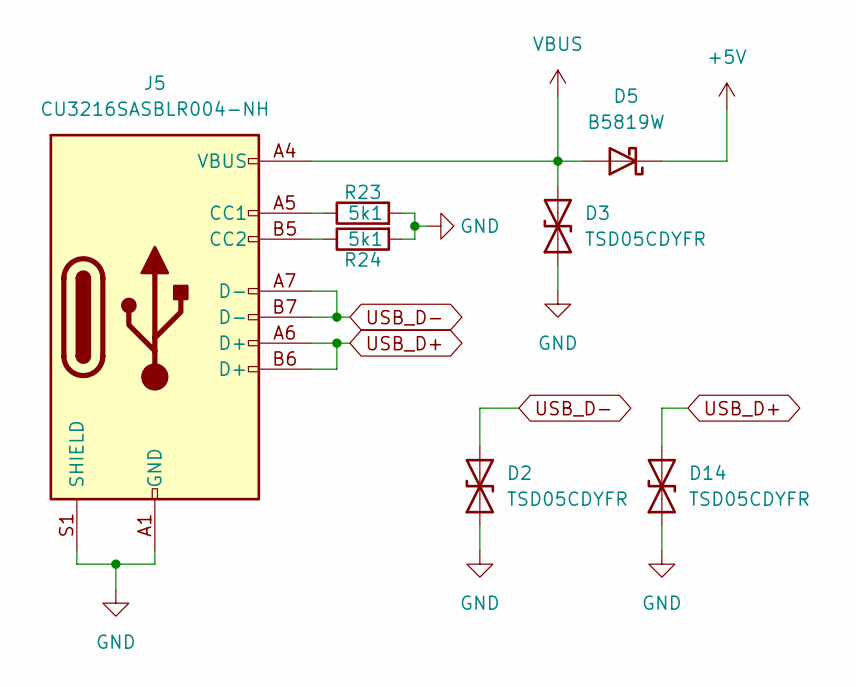
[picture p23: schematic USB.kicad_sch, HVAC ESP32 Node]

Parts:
D2, D3, D14: TSD05CDYFR; D_SOD-323_HandSoldering
D5: B5819W; D_SOD-123
J5: CU3216SASBLR004-NH; CONN_CU3216SASBLR004-NH_CVI
R23, R24: 5k1; R_0603_1608Metric_Pad0.98x0.95mm_HandSolder

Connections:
+5V: D5.1 (K); also elsewhere on the board
GND: D2.1 (A1), D3.1 (A1), D14.1 (A1), J5.A1 (GND), J5.A12 (GND), J5.B1 (GND), J5.B12 (GND), J5.S1 (SHIELD), R23.2, R24.2; also elsewhere on the board
unnamed: J5.A5 (CC1), R23.1
unnamed: J5.B5 (CC2), R24.1
USB_D+: D14.2 (A2), J5.A6 (D+), J5.B6 (D+); also elsewhere on the board
USB_D-: D2.2 (A2), J5.A7 (D-), J5.B7 (D-); also elsewhere on the board
VBUS: D3.2 (A2), D5.2 (A), J5.A4 (VBUS), J5.A9 (VBUS), J5.B4 (VBUS), J5.B9 (VBUS)

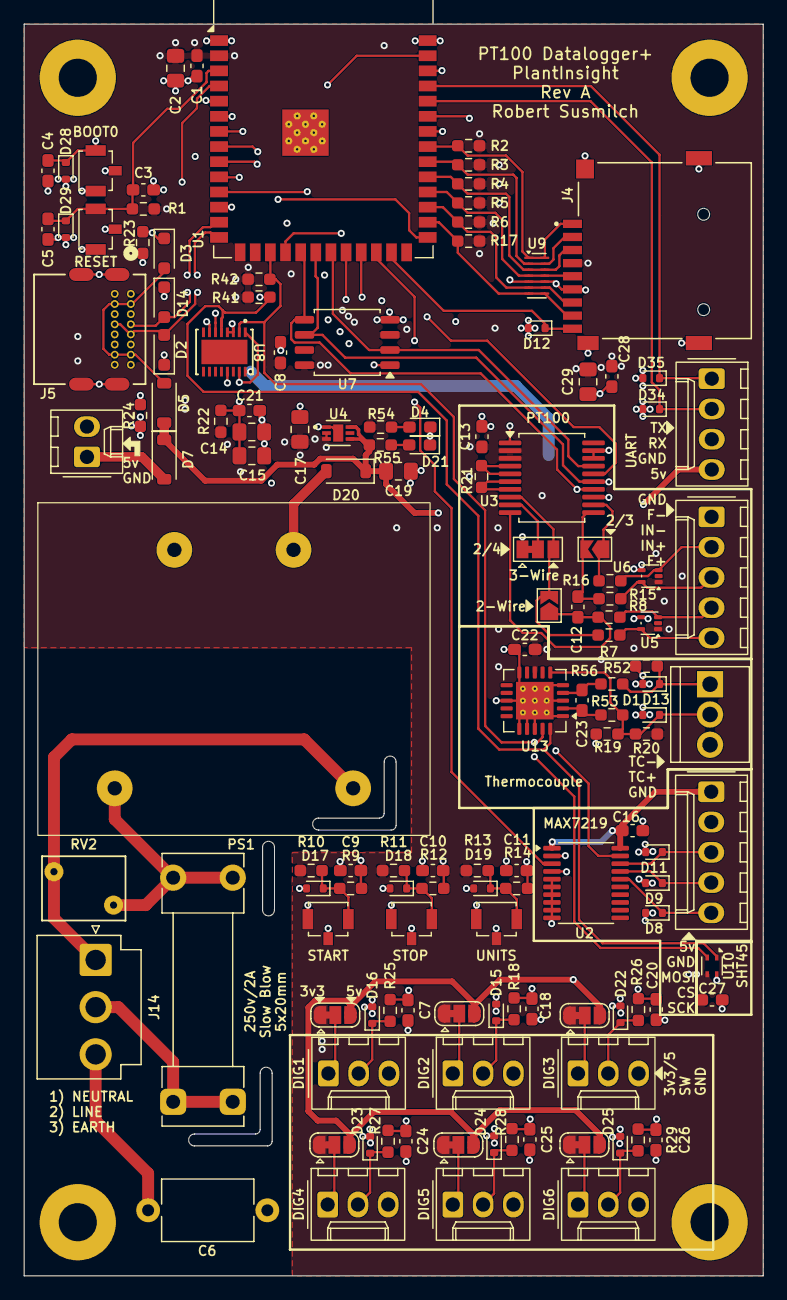
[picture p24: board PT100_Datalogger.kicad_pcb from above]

Board: 4 copper layers, 62.0 x 105.0 mm, 139 parts (1 on the bottom side), 83 nets.

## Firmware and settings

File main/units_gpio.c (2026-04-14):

#include "units_gpio.h"

#include "driver/gpio.h"
#include "esp_err.h"
#include "gpio_buttons.h"
#include "freertos/FreeRTOS.h"

#if defined(CONFIG_APP_UNITS_GPIO_ENABLE)
#define APP_UNITS_GPIO_ENABLED_BY_KCONFIG 1
#else
#define APP_UNITS_GPIO_ENABLED_BY_KCONFIG 0
#endif

static const uint32_t kUnitsGpioRtcMagic = 0x55475031;

typedef struct
{
  uint32_t magic;
  uint32_t units;
} units_gpio_rtc_store_t;

static bool UnitsGpioIsValidPin(int32_t pin);
static app_display_units_t UnitsGpioComputeUnits(bool level_high, bool c_level_high);
static bool UnitsGpioConfigureInput(int32_t pin, app_units_gpio_pull_t pull);
static bool UnitsGpioToggleModeEnabled(void);
static bool UnitsGpioPressedLevelHigh(app_units_gpio_pull_t pull, bool c_level_high);
static bool UnitsGpioIsRtcOverrideValid(void);
static app_display_units_t UnitsGpioGetRtcOverrideUnits(void);
static void UnitsGpioSetRtcOverride(app_display_units_t units);
static void UnitsGpioClearRtcOverrideLocked(void);
static app_display_units_t UnitsGpioGetBootUnitsLocked(void);
static app_display_units_t UnitsGpioGetEffectiveUnitsLocked(void);
static void UnitsGpioUpdateState(int32_t pin,
                                 app_units_gpio_pull_t pull,
                                 bool c_level_high,
                                 bool pin_valid);
static void UnitsGpioRegisterButtonLocked(void);

RTC_DATA_ATTR static units_gpio_rtc_store_t g_units_gpio_rtc = {
  .magic = 0,
  .units = 0,
};

typedef struct
{
  app_settings_t* settings;
  portMUX_TYPE lock;
  bool enabled;
  bool toggle_on_press;
  int32_t pin;
  app_units_gpio_pull_t pull;
  bool c_level_high;
  bool pin_valid;
  bool last_level_high;
  bool pressed_level_high;
  bool pressed;
  bool rtc_override_valid;
  app_display_units_t rtc_override_units;
  app_display_units_t effective_units;
} units_gpio_state_t;

static units_gpio_state_t g_units_gpio = {
  .settings = NULL,
  .lock = portMUX_INITIALIZER_UNLOCKED,
  .enabled = false,
  .toggle_on_press = false,
  .pin = -1,
  .pull = APP_UNITS_GPIO_PULL_NONE,
  .c_level_high = false,
  .pin_valid = false,
  .last_level_high = false,
  .pressed_level_high = false,
  .pressed = false,
  .rtc_override_valid = false,
  .rtc_override_units = APP_DISPLAY_UNITS_F,
  .effective_units = APP_DISPLAY_UNITS_F,
};

static bool
UnitsGpioToggleModeEnabled(void)
{
#if CONFIG_APP_UNITS_GPIO_TOGGLE_ON_PRESS
  return true;
#else
  return false;
#endif
}

static bool
UnitsGpioPressedLevelHigh(app_units_gpio_pull_t pull, bool c_level_high)
{
  if (pull == APP_UNITS_GPIO_PULL_UP) {
    return false;
  }
  if (pull == APP_UNITS_GPIO_PULL_DOWN) {
    return true;
  }
  return c_level_high;
}

static bool
UnitsGpioIsRtcOverrideValid(void)
{
  if (g_units_gpio_rtc.magic != kUnitsGpioRtcMagic) {
    return false;
  }
  return (g_units_gpio_rtc.units == (uint32_t)APP_DISPLAY_UNITS_C)
         || (g_units_gpio_rtc.units == (uint32_t)APP_DISPLAY_UNITS_F);
}

static app_display_units_t
UnitsGpioGetRtcOverrideUnits(void)
{
  if (UnitsGpioIsRtcOverrideValid()) {
    return (app_display_units_t)g_units_gpio_rtc.units;
  }
  return APP_DISPLAY_UNITS_C;
}

static void
UnitsGpioSetRtcOverride(app_display_units_t units)
{
  g_units_gpio_rtc.magic = kUnitsGpioRtcMagic;
  g_units_gpio_rtc.units = (uint32_t)units;
}

static void
UnitsGpioClearRtcOverrideLocked(void)
{
  g_units_gpio_rtc.magic = 0;
  g_units_gpio_rtc.units = 0;
  g_units_gpio.rtc_override_valid = false;
  g_units_gpio.rtc_override_units = APP_DISPLAY_UNITS_C;
}

static app_display_units_t
UnitsGpioGetBootUnitsLocked(void)
{
  return (g_units_gpio.settings != NULL) ? g_units_gpio.settings->display_units
                                         : APP_DISPLAY_UNITS_C;
}

static app_display_units_t
UnitsGpioGetEffectiveUnitsLocked(void)
{
  const app_display_units_t boot_units = UnitsGpioGetBootUnitsLocked();

  if (!g_units_gpio.enabled) {
    return boot_units;
  }

  if (g_units_gpio.toggle_on_press) {
    if (g_units_gpio.rtc_override_valid) {
      return g_units_gpio.rtc_override_units;
    }
    return boot_units;
  }

  if (!g_units_gpio.pin_valid) {
    return boot_units;
  }

  return UnitsGpioComputeUnits(g_units_gpio.last_level_high,
                               g_units_gpio.c_level_high);
}

static bool
UnitsGpioIsValidPin(int32_t pin)
{
  if (pin < 0) {
    return false;
  }
  return GPIO_IS_VALID_GPIO((gpio_num_t)pin);
}

static app_display_units_t
UnitsGpioComputeUnits(bool level_high, bool c_level_high)
{
  return (level_high == c_level_high) ? APP_DISPLAY_UNITS_C
                                      : APP_DISPLAY_UNITS_F;
}
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

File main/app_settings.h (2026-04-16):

#ifndef PT100_LOGGER_APP_SETTINGS_H_
#define PT100_LOGGER_APP_SETTINGS_H_

#include <stdbool.h>
#include <stddef.h>
#include <stdint.h>

#include "calibration.h"
#include "display_attention.h"
#include "esp_err.h"
#include "max31865_reader.h"

#define APP_SETTINGS_TZ_POSIX_MAX_LEN 64
#define APP_SETTINGS_UNIT_SERIAL_MAX_LEN 48
#define APP_SETTINGS_CAL_METHOD_MAX_LEN 96
#define APP_SETTINGS_CAL_METAR_RAW_MAX_LEN 192
#define APP_SETTINGS_CAL_METAR_STATION_MAX_LEN 8
#define APP_SETTINGS_CAL_METAR_OBS_TOKEN_MAX_LEN 16
#define APP_SETTINGS_CAL_METAR_TEMP_TOKEN_MAX_LEN 16
#define APP_SETTINGS_CAL_METAR_FLAGS_MAX_LEN 16
#define APP_SETTINGS_CAL_METAR_REMARKS_MAX_LEN 80
#define APP_SETTINGS_CAL_METAR_OBS_ISO_MAX_LEN 32
#define APP_SETTINGS_CAL_METAR_METHOD_NOTE_MAX_LEN 96
#define APP_SETTINGS_TZ_DEFAULT_POSIX "CST6CDT,M3.2.0/2,M11.1.0/2"
#define APP_SETTINGS_TZ_DEFAULT_STD "CST6"
#define APP_SETTINGS_MQTT_BROKER_URI_DEFAULT "mqtt://192.168.1.50"
#define APP_SETTINGS_MQTT_TOPIC_PREFIX_DEFAULT "pt100"

#ifdef __cplusplus
extern "C"
{
#endif

  typedef enum
  {
    APP_NODE_ROLE_ROOT = 0,
    APP_NODE_ROLE_SENSOR = 1,
    APP_NODE_ROLE_RELAY = 2,
  } app_node_role_t;

  typedef enum
  {
    APP_DISPLAY_UNITS_C = 0,
    APP_DISPLAY_UNITS_F = 1,
  } app_display_units_t;

  typedef enum
  {
    APP_UNITS_GPIO_PULL_NONE = 0,
    APP_UNITS_GPIO_PULL_UP = 1,
    APP_UNITS_GPIO_PULL_DOWN = 2,
  } app_units_gpio_pull_t;

  typedef enum
  {
    APP_NET_MODE_MESH = 0,
    APP_NET_MODE_DIRECT_WIFI = 1,
    APP_NET_MODE_NONE = 2,
  } app_net_mode_t;

  typedef enum
  {
    MQTT_BRIDGE_OFF = 0,
    MQTT_BRIDGE_SERIAL = 1,
    MQTT_BRIDGE_BROKER = 2,
    MQTT_BRIDGE_BOTH = 3,
  } mqtt_bridge_mode_t;

  typedef struct
  {
    uint8_t conversion_mode;
    uint8_t wires;
    uint8_t filter_hz;
    double rref_ohm;
    double r0_ohm;
    uint32_t table_version;
  } calibration_context_t;

  typedef struct
  {
    uint8_t valid;
    char source_type[8];
    char raw_metar[APP_SETTINGS_CAL_METAR_RAW_MAX_LEN];
    char station_id[APP_SETTINGS_CAL_METAR_STATION_MAX_LEN];
    char observation_token[APP_SETTINGS_CAL_METAR_OBS_TOKEN_MAX_LEN];
    char observation_iso_utc[APP_SETTINGS_CAL_METAR_OBS_ISO_MAX_LEN];
    uint8_t observation_resolved;
    uint16_t elevation_ft;
    float altimeter_inhg;
    float station_pressure_inhg;
    float satpt_c;
    char auto_or_cor[APP_SETTINGS_CAL_METAR_FLAGS_MAX_LEN];
    char temp_dew_token[APP_SETTINGS_CAL_METAR_TEMP_TOKEN_MAX_LEN];
    char remarks[APP_SETTINGS_CAL_METAR_REMARKS_MAX_LEN];
    int64_t stored_at_utc_epoch;
    char method_note[APP_SETTINGS_CAL_METAR_METHOD_NOTE_MAX_LEN];
  } calibration_metar_reference_t;

  // Deployment guidance:
  // - Dense plant/fixed power: enable children on RELAY nodes; selectively enable
  //   on SENSOR nodes only where needed.
  // - Sparse/unknown geometry: allow_children on SENSOR nodes can improve reach
  //   at the cost of more chatter.

  typedef struct
  {
    uint32_t log_period_ms;
    uint32_t display_sample_period_ms;
    uint32_t fram_flush_watermark_records;
    uint32_t sd_flush_period_ms;
    uint32_t sd_batch_bytes_target;
    bool sd_verify_readback;
    uint32_t rtc_resync_period_ms;
    calibration_model_t calibration;
    calibration_context_t calibration_context;
    bool calibration_context_valid;
    calibration_point_t calibration_points[CALIBRATION_MAX_POINTS];
    uint8_t calibration_points_count;
    calibration_domain_t calibration_domain;
    uint16_t cal_window_duration_s;
    uint16_t cal_trend_ema_alpha_permille;
    // Calibration tracking (UTC-based)
    int64_t cal_last_utc;
    int64_t cal_last_override_utc;
    uint16_t cal_due_count;
    uint8_t cal_due_unit;
    uint16_t cal_due_override_count;
    uint8_t cal_due_override_unit;
    calibration_metar_reference_t cal_metar;
    bool rtd_ema_enabled;
    uint16_t rtd_ema_alpha_permille;
    uint32_t rtd_fault_assert_ms;
    uint32_t rtd_fault_clear_ms;
    char tz_posix[APP_SETTINGS_TZ_POSIX_MAX_LEN];
    char unit_serial[APP_SETTINGS_UNIT_SERIAL_MAX_LEN];  // Deprecated: do not use for audit identity; MAC is used as device id.
    char cal_method[APP_SETTINGS_CAL_METHOD_MAX_LEN];
    bool dst_enabled;
    app_node_role_t node_role;
    bool allow_children;
    bool allow_children_set;
    app_display_units_t display_units;
    uint32_t display_attention_policy;
    display_attention_mask_t display_attention_mask;
    app_net_mode_t net_mode;
    bool mqtt_enabled;
    char mqtt_broker_uri[128];
    char mqtt_topic_prefix[64];
    uint8_t mqtt_qos;
    bool mqtt_retain;
    mqtt_bridge_mode_t mqtt_bridge_mode;
  } app_settings_t;

  // Loads settings from NVS. If keys are missing or invalid, applies defaults.
/**
 * @brief Execute AppSettingsLoad.
 * @param settings_out Parameter settings_out.
 * @return Return the function result.
 */
  esp_err_t AppSettingsLoad(app_settings_t* settings_out);
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

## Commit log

2025-12-17 Fixed missing mac str and partition table
    [partitions_n8r2_8mb_ota.csv]
2025-12-18 Fixed various compile errors and includes. Updated pin mapping.
2025-12-18 Add scaffolded diagnostic command framework
2025-12-19 Refactor I2C handling and RTC diagnostics
2025-12-19 Add I2C FRAM backend and diagnostics
2025-12-19 Implement MAX31865 RTD driver and diagnostics
2025-12-24 Fixed I2C and FRAM. Attempting fix 0x3002 spam from wifi and setting mesh channel
2025-12-24 Print sampled records on all nodes
2025-12-25 Route CSV data over dedicated UART0 port
2025-12-25 Add console mode switch for data streaming
2025-12-26 Fixing separate UART for CSV logs
    [data_port.c]
2025-12-26 Add calibration window stats sampling
2025-12-26 Store calibration point metadata
2025-12-26 Update calibration fitting to least-squares
2025-12-26 Add piecewise residual calibration mode
2025-12-26 Invalidate calibration on sensor config changes
2025-12-26 Document calibration workflow in help
2025-12-27 Patch SD card to retry mounting periodically
    [2025-12-26.csv]
2025-12-27 Reset SD resume record id per file
    [sd_logger.c]
2025-12-27 Harden SD append failure handling
    [sd_logger.c]
2025-12-27 Fix sensor fault logs error
2025-12-29 Throttle SD flush work and add verify yields
2025-12-29 Changed sd path printing too short
    [sd_logger.c]
2025-12-29 Harden display temperature formatting
2025-12-30 Fixed printf incorrect argument type.
2026-01-01 Increase stack size for main task and chase fram drain on boot issues.
    [sd_logger.c]
2026-01-05 Add SD card detect support; gate mounts; keep SDOUT error per policy
2026-01-07 Add interruptible runtime task delays
2026-01-07 Use interruptible delay for time sync period
2026-01-08 Use polling SPI for MAX31865 transfers
2026-01-08 Make alert sender backoff interruptible
2026-01-08 Add SPI device deinit support
2026-01-08 Make SPI bus init idempotent
2026-01-08 Pause SPI users before stop drain
2026-01-08 Serialize SD IO around mount and flush
2026-01-08 Wire SD DMA-aligned bounce buffer
2026-01-08 Fix sdmmc dma buffer setup for IDF 5.5
    [sd_logger.c]
2026-01-09 Add display SPI pause acknowledgement
2026-01-09 Fix shared SPI bus init for MAX7219
2026-01-09 Increase app init stack and soften SPI bus sharing
2026-01-09 Separate MAX7219 display SPI bus
2026-01-11 Avoid run-time CSV allocations
    [sd_logger.c]
2026-01-13 Updated stack table printf
2026-01-13 Add system alerts for standalone Wi-Fi sensors
2026-01-13 Fix macro use and const missing. Rollup Kconfig.gpio into Kconfig.projbuild
    [units_gpio.c]
2026-01-13 Updated solo SENSOR node
2026-01-13 Updating PDF generator
    [2026-01-13Z.csv]
2026-01-14 Fixed plotting and added F option.
    [pt100_csv_plotter_pdf_v7_local_time_fahrenheit.py]
2026-01-14 host_tools: render out-of-bounds highlights as full-resolution x-spans (fix streak artifacts)
    [pt100_csv_plotter_pdf_v7_local_time_fahrenheit.py]
2026-01-14 host_tools: fix range selector slider layout + hide slider value text + draw limit lines
    [pt100_csv_plotter_pdf_v7_local_time_fahrenheit.py]
2026-01-14 console: fix alert hysteresis parsing as temperature delta (support F)
2026-01-14 Add configurable MAX31865 EMA smoothing (CLI + NVS) and wire into sensor sampling
2026-01-14 RTD: apply EMA on resistance for operator stream; keep exports raw; align alerts with display
2026-01-15 Host tools updated to fix display problems
    [pt100_csv_plotter_pdf_v7_local_time_fahrenheit_patched.py, pt100_csv_plotter_pdf_v7_local_time_fahrenheit_patched_v2.py]
2026-01-15 Fixed incorrect assumption in plotter for calibrated series.
2026-01-15 Add calibration due-date enforcement
2026-01-15 console: add forward declarations for calibration schedule helpers to fix build
2026-01-15 Fixed issues with wrong y_name. Removed overlay in summary
    [pt100_csv_plotter_pdf_v7_local_time_fahrenheit_patched_v5.py]
2026-01-16 Updating plotter zorder
    [2026-01-13Z.csv]
2026-01-19 Add I2C recovery guard for FRAM failures
2026-01-20 Harden MAX31865 SPI reads
2026-01-20 Fix SD reset SPI sharing and ntfy cooldown
2026-01-21 Add ntfy pump cooldown logic
2026-01-22 Add wifi acquire backoff and harden I2C recovery
2026-01-22 Add heap trace window for Wi-Fi start
2026-01-22 Right-size stacks and add heap/I2C diagnostics
2026-01-22 Reserve Wi-Fi driver early
2026-01-23 SD flush traverses FatFs/VFS/Newlib and the SDSPI DMA path. 4KB proved marginal during watermark drains and day-rollover file creation (very low observed watermark), which can lead to corruption/trac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
2026-01-23 Fix temperature text formatting
2026-01-23 Modified calibration points
2026-01-30 Fix reset in logger to deassert both then manually assert to reset ESP32 boards
    [logger.py]
2026-01-30 Harden I2C diagnostics and FRAM flush locking
2026-01-30 Add safe-hold boot flow and reboot latch diagnostics
    [fram_i2c.c]
2026-02-02 I2C Log
2026-02-02 Guard I2C transactions when controller is busy
2026-02-02 Add RTC errlog latch for I2C hang resets
2026-02-03 Asserted the desired DTS/RTS signal lines to stop inadvertant reseting
    [logger.py]
2026-02-07 Adjust I2C timeouts and SD flush locking
2026-02-09 Clamp alert gap deltas
2026-02-09 Deleted CSV files
    [2025-12-26.csv, 2026-01-13Z.csv]
2026-02-12 Add I2C quiesce deferred logging during SD flush
2026-02-12 Suppress FRAM failure escalation during I2C quiesce
2026-02-12 Stop tracking ESP-IDF managed_components. Upgraded to v5.5.2 to fix I2C NACK hang
2026-02-12 Improve stream backend visibility and quiesce/reset handling
    [data_port.c]
2026-02-12 Fix UART0 data stream pin routing configuration
    [data_port.c]
2026-02-13 Handle SD full via log rotation and add SD/ntfy/reset diagnostics
    [sd_logger.c]
2026-02-13 Fix sd_logger path/name truncation handling
    [sd_logger.c]
2026-02-17 Fix calibration save path and add cal method CLI
    [app_settings.h]
2026-02-17 Switch SD logging from CSV to PTLOG daily files
2026-02-17 Consolidate GPIO button polling into unified module
2026-02-17 Enforce explicit calibration evidence across firmware and plotter
2026-02-18 Unify console reporting for applied calibration
2026-02-18 Fix PDF audit duplication and unset calibration method handling
    [pt100_plotter.py]
2026-02-19 Fix calibration-applied timing and PDF calibration reporting
    [pt100_plotter.py]
2026-02-20 Changed report wording and fixed SAFE to STOP to be clearer on the display.
    [pt100_plotter.py]
2026-02-23 Add SD OOS and storage stall system error alerts
2026-02-24 Add SD SPI max clock config and fflush retry
2026-02-26 Add periodic and crash-safe flush handling to logger
    [logger.py]
2026-03-02 logger: replace utcnow with timezone-aware UTC now
    [logger.py, pt100_plotter.py]
2026-03-02 Fix start-date label placement and calibration series/date behavior
    [pt100_plotter.py]
2026-03-02 Fix multi-day date labels and calibrated series auto-selection
    [pt100_plotter.py]
2026-03-02 Serialize shared SPI access for SD and MAX31865
2026-03-02 Upping the Sensor stack size
2026-03-02 Fix multiday start-date label casing and layout clipping
    [pt100_plotter.py]
2026-03-04 Decouple sensor polling cadence from logging interval
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2026-03-06 Move PT100 calibration to resistance domain with legacy migration
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2026-03-07 Preserve sensor fault status in persisted logs and exports
2026-03-13 Documents and starting KiCad board.
    [7_seg.kicad_sch, Connectors.kicad_sch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]
2026-03-16 Fix I2C nested lock reentry and rate-limit timeout logs
2026-03-16 Reorganize PT100 Kconfig by subsystem and fix USB JTAG config const
    [data_port.c]
2026-03-20 Finished KiCad PCB REV A
    [7_seg.kicad_sch, Connectors.kicad_sch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]
2026-04-08 Refine calibration help workflow and status domain wording
2026-04-08 Fix calibration CLI point management and negative add parsing
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2026-04-08 Add cal import/restore command for resistance points
2026-04-09 cal: expose ideal PT100 resistance and ohmic residuals in status
2026-04-09 Adding updated calibration record document
2026-04-09 Add last raw sample fields to cal capture output
2026-04-13 Add calibration window drift/delta metrics and drift-gated capture
    [calibration.h]
2026-04-13 Use regression slope for calibration window drift
    [calibration.h]
2026-04-13 Add smoothed calibration trend config, persistence, and paste import
2026-04-13 Unify calibration window readiness with active-window resolver
2026-04-14 logger: add passive POSIX no-reset serial lifecycle handling
    - split serial open into reset-aware and passive no-reset strategies\n- use passive no-reset open path on POSIX when --no-reset is active\n- add best-effort HUPCL clearing and concise strategy/HUPCL metadata logs\n- avoid explicit modem-line normalization in no-reset path\n- route reconnect reopen and teardown through the same lifecycle helpers\n\nSelf-test plan:\n- Linux: run with --no-reset and verify no boot banner appears on initial connect.\n- Linux: unplug/replug (or force reconnect) and verify no boot banner appears on reconnect.\n- Linux: stop the logger cleanly and verify shutdown does not trigger a reset/banner.\n- Window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
    [logger.py]
2026-04-14 Enable cal capture attachment to running cal live session
2026-04-14 Fix units_gpio Kconfig bool handling
    [units_gpio.c]
2026-04-14 Optimize calibration window live math with rolling aggregates
2026-04-14 Fix cal_op stack overflow by removing large app_settings snapshots from save path
    - moved settings save scratch storage out of caller stack
    - added shared static snapshot buffer with locking
    - refactored calibration persistence APIs to avoid stack-heavy saves
    - preserves deterministic memory use without heap fragmentation
2026-04-14 Adding current calibration status
2026-04-14 Revert stack reporting to deterministic monitored-task registry and remove trace-facility dependency
2026-04-15 Add cal livecal calibrated live console mode
    - add new 'cal livecal' subcommand that reuses cal live task infrastructure with a live output-mode flag
    - gate cal livecal startup using ConsoleCalibrationIsApplied(...) and print clear blocked reason when calibration is not currently applied
    - add deterministic calibrated live line output with UTC timestamp, raw/mean/std resistance, calibrated current/mean/std temp, drift/delta, and MAX31865 fault text+hex
    - add bounded active-window sample accessor and calibrated-window temp stddev computation across fixed window samples (no heap allocations)
    - keep cal stop/shared op behavior unchanged and update help/usage/synopsis/examples for livecal
    - no h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
    [calibration.h]
2026-04-15 Fix compile break from stale cal sample helper call
2026-04-15 Refactored cal livecal print statement
2026-04-15 Fix calibration context persistence during apply
2026-04-15 Diagnose cal live RAM pressure and shift live buffers to PSRAM
2026-04-15 Fix calibration fallback storage init order and PSRAM check
2026-04-16 Fix livecal calibrated-stats cache freshness bug when active window is full
    [calibration.h]
2026-04-16 Fix early livecal cache invalidation by removing concurrent runtime writes to the shared calibration window
    [calibration.h]
2026-04-16 Use runtime sensor snapshot for cal live/livecal consumption
2026-04-16 Fix SD hot-remount state reset and clarify sd verify help
    [sd_logger.c]
2026-04-16 Fix net CLI to show configured vs effective mode
    [app_settings.h]
2026-04-16 Fix app_settings blob version typedef chain and migrations
2026-04-17 Fix PT100 range selector apply flow and preserve manual range
    [pt100_plotter.py]
2026-04-18 Added a tool to parse "cal livecal" lines to CSV
    [bore_bracket_120F_reverse_BAB.csv, repeatability_study.csv]
2026-04-18 Updated livecal_extractor.py to not emit the run and bore empty columns. Created a python script to analyze log files for stability.
    [bore_bracket_120F_reverse_BAB.csv]
2026-04-20 Add plot smoothing controls and drift window warm-up guard
    [analyze_temp_stability.py]
2026-04-20 Fix trailing drift warm-up check for sampled data
    [analyze_temp_stability.py]
2026-04-21 Add readable calibration equation output to cal status
2026-04-21 Updated current cal log with the coefficients
2026-04-22 Expand calibration fit reporting with reusable audit helpers
2026-04-22 Update calibration fitness table and names
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2026-05-06 Fix plotter trim timezone handling and add regression tests
    [pt100_plotter.py]
2026-05-06 Removed extra iterations of plotter files. Refactored directories so updated gitignore.
    [PT100_Datalogger.kicad_pcb]
2026-05-06 Fix Python 3.14 host_tools timezone/import test failures
    [pt100_plotter.py]
2026-05-06 Add spacer between PDF title and summary table
2026-05-06 Fix range selector to write times in input timezone mode
    [pt100_plotter.py]
2026-05-06 Fix sensor fault detail wording for fault_status 0x00
    [pt100_plotter.py]
2026-05-06 Fix range selector timezone variable and callback ordering
    [pt100_plotter.py]
2026-05-06 Fix range selector to use LoadedLog.tzinfo
    [pt100_plotter.py]
2026-06-25 Harden PTLOG candidate filtering
2026-06-27 Fix compact PTLOG same-day revision selection
    [sd_logger.c]
2026-06-29 Fix PTLOG workspace explicit API usage
    [sd_logger.c]
